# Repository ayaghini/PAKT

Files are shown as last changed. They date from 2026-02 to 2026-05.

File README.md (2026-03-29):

# PAKT

## Executive Summary
PAKT is an ESP32-S3-based APRS pocket TNC/tracker built around an SA818 VHF radio,
SGTL5000 audio codec, GPS, and BLE. The MVP now includes both the native PAKT BLE
protocol and KISS-over-BLE so existing APRS software can use the device as a BLE TNC.

The software foundation is substantially in place, and the current bench prototype
has now cleared the core codec and radio bring-up steps:
- firmware includes AX.25/APRS framing, AFSK modulator/demodulator, BLE GATT services,
  KISS-over-BLE, APRS TX scheduling, telemetry payloads, SGTL5000 audio pipeline bring-up,
  staged SA818 bench tests, and SA818 control paths
- the desktop test app and KISS bridge are implemented as reference host tools
- an in-repo iPhone-only SwiftUI app track now exists under `app/ios/`, built against the same native BLE protocol as the desktop client
- host-side software evidence is strong, with current docs recording `364/364` host tests passing
- bench bring-up has confirmed SGTL5000 discovery and headphone output, shared I2C
  visibility for the MAX17048 and M9N, SA818 UART handshake/config, staged PTT/audio tests,
  and short APRS packet TX receipt on a separate receiver

Recent bench work materially improved the RF picture:
- SA818 UART handshake/config recovered and is now responding again on hardware
- staged PTT test and 10-tone TX bench are confirmed working on the current prototype
- APRS packet TX is now bench-proven again on the current hardware state, with packets
  received externally during the restored full test flow
- RX analog/audio activity reaches the demodulator and now has stronger instrumentation
- RX debug now includes PSRAM-backed WAV export, selectable bench stages, selectable
  sample-path conditioning, and a `16 kHz` capture mode
- a separate quiet-capture firmware profile now supports repeated `30 s` low-noise
  captures with a countdown and framed binary export suitable for handoff analysis
- on-device APRS RX is now proven on hardware after fixing a half-rate I2S capture bug
  and reducing Stage C SA818 receive volume; the prototype now decodes APRS frames on-device
- the APRS message-ack path is now wired into `TxScheduler`, so on-air APRS acks
  can complete the firmware message FSM instead of always timing out
- the GPS path now prefers the shared Feather I2C/STEMMA bus (`u-blox M9N @ 0x42`)
  with `UART2` (`GPIO17/GPIO18`, `38400` baud) retained as a fallback; raw NMEA
  traffic is now logged/published even before a valid fix
- GPS over the shared Feather I2C/STEMMA bus is now working on the current
  prototype, including live telemetry delivery to the app; this path should now
  be treated as the default GPS integration baseline rather than an open bring-up item

The project is not MVP-complete yet because hardware validation still gates the milestone:
- BLE security and PTT fail-safe validation on hardware
- SA818 deviation and on-air receive/transmit calibration
- trusted Bell 202 source validation and on-device APRS RX proof
- third-party KISS client validation

## Project Status At A Glance

| Area | Status | Notes |
|---|---|---|
| Core firmware architecture | `strong` | AX.25/APRS, AFSK, BLE, KISS-over-BLE, scheduling, and host tooling are implemented |
| Bench bring-up | `in progress` | I2C, codec bring-up, SA818 UART/config, PTT, staged TX audio, and APRS TX bench are working |
| APRS TX over RF | `proven on current prototype` | tone sequence and APRS packets were heard/received again after SA818 recovery on 2026-03-21 |
| APRS RX over RF | `proven on current prototype` | quiet-profile RX now decodes APRS on-device after fixing the half-rate capture bug and reducing Stage C volume |
| BLE/KISS hardware validation | `pending` | software-complete enough for hardware validation |
| GPS over shared I2C | `proven on current prototype` | `u-blox M9N @ 0x42` is detected after startup, hot-switches to I2C/DDC, and publishes live telemetry to the app |
| MVP milestone | `open` | blocked by BLE safety validation, radio calibration/repeatability, and remaining hardware gates

## Progress Summary
- Software stack is largely implemented and test-backed.
- Prototype hardware can boot the codec/radio path, recover SA818 control, transmit APRS packets over RF, and now decode APRS on-device.
- Main firmware is now in production mode by default: recorder/export bench stages are disabled on boot while the continuous APRS RX path remains active.
- Demodulator instrumentation now exposes RX peak, flag, FCS-reject, and decode counters during bench work.
- Bench stages are now selectable through [bench_profile_config.h](/Users/macmini4/Desktop/PAKT/firmware/main/bench_profile_config.h), so debug sessions can run only the needed benches/stages instead of the full boot-time sequence.
- Full RX recorder/export now works through PSRAM-backed WAV capture, and the quiet profile can export captured demod-input audio through a framed binary serial stream for offline reconstruction.
- A real RX blocker was found and fixed: the audio pipeline was unpacking only half of each 2048-byte I2S read, effectively feeding the demodulator at `8 kHz` while configured for `16 kHz`.
- After fixing that bug and lowering quiet-profile Stage C SA818 volume from `8` to `4`, the device decoded multiple on-air APRS frames in the same `30 s` window.
- GPS parsing is no longer a stub: `gps_task` now reads the M9N over the shared I2C bus when present, falls back to UART if needed, and publishes BLE GPS telemetry even in the no-fix state.
- GPS over the shared Feather I2C/STEMMA bus is now confirmed working in the current hardware setup, and live GPS data is reaching the app.
- APRS ack handling is no longer a dead end: received APRS acks can now call `ctx.notify_ack()` and complete the message FSM in firmware.
- The RX path is now also configurable at the firmware level for:
  - `8 kHz` or `16 kHz` audio rate
  - left/right/average/stronger channel selection
  - stereo-slot swap
  - sample byte swap
  - firmware DC blocking
- The current best debugging workflow is the separate quiet-capture profile.
- The repo now distinguishes clearly between:
  - audio-path alive
  - packet TX proven
  - on-device APRS RX now proven on the corrected quiet profile

## Immediate Next Steps
1. Validate BLE encrypted+bonded write enforcement and PTT fail-safe behavior on live hardware.
2. Verify the newly wired APRS ack path end-to-end with real on-air message acknowledgements.
3. Validate native BLE + KISS-over-BLE behavior on hardware, including reconnect and at least one real client path.
4. Bring up the iPhone app against the same firmware build: connect, view APRS RX/GPS/status, send TX requests, change radio settings, and enable the BLE debug stream.
5. Keep the shared-I2C GPS path as the default baseline and only use UART fallback for alternate wiring or recovery.

## Bench Profile
- Bench/debug stage selection is controlled in [bench_profile_config.h](/Users/macmini4/Desktop/PAKT/firmware/main/bench_profile_config.h).
- Current toggles allow independent enable/disable of:
  - `audio_bench`
  - `sa818_bench`
  - `aprs_bench`
  - APRS Stage 0 loopback
  - APRS Stage A TX burst
  - APRS Stage B RX gain sweep
  - APRS PCM snapshot dump
  - APRS Stage C full RX recorder/export
- Stage C also has a selectable ADC gain step so targeted RX captures can be taken at the most useful receive setting.
- The same file now controls the audio debug sample rate and RX sample interpretation path.

## Current Status
- Phase: prototype hardware bring-up in progress, with packet TX, on-device APRS RX, and shared-I2C GPS telemetry now proven on the current prototype; remaining work is calibration, repeatability, app validation, and safety validation
- Firmware build flow: ESP-IDF with `idf.py`
- Host test flow: raw CMake only for `firmware/test_host`
- Canonical wire-format source: `docs/aprs_mvp_docs/payload_contracts.md`
- Canonical implementation/risk ledger: `docs/aprs_mvp_docs/agent_bootstrap/audit.md`

## Bench-Proven Baseline
- Feather target: Adafruit ESP32-S3 Feather `4 MB flash / 2 MB PSRAM`
- Shared I2C bus: `SGTL5000 @ 0x0A`, `MAX17048 @ 0x36`, `u-blox M9N @ 0x42`
- Audio bring-up rule: enable `SYS_MCLK` before SGTL5000 I2C init
- Verified audio wiring:
  - `GPIO3` `I2C_SDA`
  - `GPIO4` `I2C_SCL`
  - `GPIO8` `I2S_BCLK`
  - `GPIO15` `I2S_WS`
  - `GPIO12` `I2S_DOUT`
  - `GPIO10` `I2S_DIN`
  - `GPIO14` `I2S_MCLK`
- Verified radio control wiring:
  - `GPIO13` `SA818_RX_CTRL`
  - `GPIO9` `SA818_TX_STAT`
  - `GPIO11` `SA818_PTT`
- Restored and re-verified on 2026-03-21:
  - `AT+DMOCONNECT` handshake passes
  - `AT+DMOSETGROUP` frequency config passes
  - staged PTT test passes
  - 10-tone TX bench is audible on a receiver
  - APRS packet TX is received externally
- Bench modules now in the firmware tree:
  - `firmware/main/audio_bench_test/`
  - `firmware/main/sa818_bench_test/`

## Next Steps
- Measure TX deviation and formalize the corrected RX baseline in the bench docs
- Re-run APRS RX across multiple sessions to confirm repeatable decode margin on the corrected quiet profile
- If needed, tune SGTL5000 input/gain/sample interpretation using the new sample-path debug controls, but the core on-device RX proof now exists
- Measure and record SA818 TX deviation with the actual `LINE_OUT -> AF_IN` attenuation in place
- Validate BLE security enforcement and PTT watchdog behavior on the live hardware stack
- Freeze the harness values into the PCB-facing docs once AF levels, deviation, and PTT topology are measured

## Start Here
- `docs/README.md`
- `docs/aprs_mvp_docs/README.md`
- `docs/aprs_mvp_docs/agent_bootstrap/README.md`
- `docs/aprs_mvp_docs/agent_bootstrap/implementation_steps_mvp.md`
- `docs/aprs_mvp_docs/agent_bootstrap/gate_pass_matrix.md`
- `docs/aprs_mvp_docs/agent_bootstrap/audit.md`
- `docs/aprs_mvp_docs/docs/02_mvp_scope.md`
- `docs/aprs_mvp_docs/docs/05_ble_gatt_spec.md`
- `docs/aprs_mvp_docs/docs/19_ble_integration_reference.md`
- `docs/aprs_mvp_docs/docs/16_kiss_over_ble_spec.md`
- `docs/aprs_mvp_docs/payload_contracts.md`
- `docs/dev_setup.md`
- `docs/bench_bringup_checklist.md`
- `hardware/prototyping_wiring.md`
- `hardware/prototype_breakout_wiring_plan.md`

## Repository Layout
- `docs/`: unified documentation home
- `firmware/`: ESP-IDF firmware, host tests, and embedded integration code
- `app/desktop_test/`: desktop BLE reference client and KISS bridge/harness
- `docs/aprs_mvp_docs/docs/`: product, architecture, protocol, firmware, test, and risk docs
- `docs/aprs_mvp_docs/agent_bootstrap/`: low-token onboarding pack, implementation sequence, gates, and audit log
- `docs/aprs_mvp_docs/hardware/`: hardware interface notes and placeholder BOM
- `docs/hardware/`: hardware source library, CAD asset tracking, and reference links
- `docs/dev_setup.md` + `docs/bench_bringup_checklist.md`: operator/developer companion docs
- `hardware/`: practical prototyping wiring and hardware rationale
- `handoff/agent_integration_package/`: external-agent handoff package for host-software integration work

## Working Rules
- Use ESP-IDF `idf.py` for firmware builds; do not use raw CMake as the direct firmware entrypoint.
- Use raw CMake only for pure-software host tests under `firmware/test_host`.
- Keep `docs/aprs_mvp_docs/docs/05_ble_gatt_spec.md`,
- `docs/aprs_mvp_docs/docs/19_ble_integration_reference.md`,
- `docs/aprs_mvp_docs/agent_bootstrap/ble_protocol_quickref.md`,
  `docs/aprs_mvp_docs/docs/16_kiss_over_ble_spec.md`, and
  `docs/aprs_mvp_docs/payload_contracts.md` aligned with the implementation.
- If BLE UUIDs, payload fields, command semantics, chunking, or client behavior changes,
  update all relevant protocol docs in the same change so the desktop app, iPhone app,
  firmware, and future integrations do not drift.
- Prefer `firmware/main/main.cpp` and the component implementations as the source of truth for what is actually wired versus still hardware-gated.

## Build Directories
- `firmware/build_*` are the intended build output directories for the firmware project.
- Repo-root `build_feather_s3/` is also an ESP-IDF-generated build tree for the same `firmware/` project, not a second source tree.
- The metadata inside both `build_feather_s3/project_description.json` and `firmware/build_feather_s3/project_description.json` points back to `firmware/`; the difference is only the chosen build output path.

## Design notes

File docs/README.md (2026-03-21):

# Documentation Index

`docs/` is the single top-level documentation home for this repo.

## Project Snapshot
- Current phase: bench prototype verification
- Proven today:
  - codec/radio path boots and bench audio stages run
  - APRS packet TX has been received externally in a supervised setup
  - RX analog/audio path is active, instrumented, and can now be recorded to a PSRAM-backed WAV export
  - RX debug path is now bench-configurable at the firmware level, including channel selection and sample conditioning controls
  - a `16-bit / 16 kHz` RX capture path is now running on hardware
- Still open:
  - on-device APRS RX decode from a trusted Bell 202 source
  - SA818 TX deviation measurement
  - BLE safety/security hardware validation
  - final RX margin closure through the SGTL5000/I2S/sample path, where the latest suspicion is now concentrated

## Main Sections
- `aprs_mvp_docs/` — canonical product, protocol, architecture, QA, and status docs
- `dev_setup.md` — local toolchain, build, and test flow
- `bench_bringup_checklist.md` — bench execution order for the prototype
- `bench_measured_values_template.md` — measurement capture sheet
- `hardware/` — hardware reference library, source links, and CAD asset tracking
- `../firmware/main/bench_profile_config.h` — build-time bench stage selection for targeted debug sessions

## Recommended Entry Points
- Repo orientation: `aprs_mvp_docs/README.md`
- Current implementation status: `aprs_mvp_docs/agent_bootstrap/gate_pass_matrix.md`
- Rolling verification record: `aprs_mvp_docs/agent_bootstrap/audit.md`
- Bench work: `bench_bringup_checklist.md`
- Local setup: `dev_setup.md`

## Structure Notes
- `aprs_mvp_docs/` is the canonical spec and project-status tree.
- `hardware/` is the reference-library tree for components and assets.
- Repo-root `hardware/` is different: it contains practical wiring and prototype-planning notes rather than the source-library material.

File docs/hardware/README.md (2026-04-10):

# Hardware Reference Library

This folder holds the hardware references that feed schematic capture and PCB
layout. The active baseline now follows the confirmed bench stack rather than
earlier option-screening documents.

## Active hardware baseline
- MCU: `ESP32-S3-WROOM-1` (PCB antenna).
- Radio: `SA818S`.
- Audio codec: `SGTL5000XNLA3`.
- GPS layout baseline: u-blox `NEO-M8N/M8M` compatible footprint (`ublox_NEO`), with module choice finalized later.
- Fuel gauge: `MAX17048G+T10`.
- Charger: `MCP73831T-2ACI/OT`.
- GPS backup battery: `Panasonic BR-1225A/FAN` (non-rechargeable primary cell).

## Reference-design anchor
For battery charging and battery gauging, the custom PCB should follow the
bench-board power behavior of the Adafruit ESP32-S3 Feather baseline, because
that was used for bench validation and aligns with the `MAX17048` gauge path.

## Folder structure
- `components/README.md` - active vs archived component folders.
- `components/<part>/sources.md` - OEM datasheets, application notes, and reference-design links.
- `components/<part>/cad_assets.md` - symbol, footprint, package, and model mapping for KiCad.
- `components/<part>/symbols/` - local KiCad symbol libraries when needed.
- `components/<part>/footprints/` - local KiCad footprint files when needed.
- `components/<part>/step/` - STEP models if they are stored in-repo.

## Optional-components review flow
- Current plan: `hardware/PCB/rev01/reviews/HARDWARE_OPTIONAL_COMPONENT_PLAN.md`
- Completed reviews:
  - `hardware/PCB/rev01/reviews/GPS_OPTIONAL_COMPONENT_REVIEW.md`
  - `hardware/PCB/rev01/reviews/SA818_OPTIONAL_COMPONENT_REVIEW.md`

## Source policy
- Prefer OEM product pages, datasheets, and application notes.
- Keep breakout-board reference links separate from semiconductor OEM links.
- Mark legacy or mirror references clearly.

Current asset status is tracked in:
- `components/CAD_ASSET_STATUS.md`

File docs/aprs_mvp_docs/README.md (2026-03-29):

# APRS 2m Pocket TNC + Tracker (SA818 + ESP32-S3 + GPS) - MVP Docs

Last updated: 2026-03-28

This folder contains the working documentation set for a standalone APRS
(1200 baud AFSK, AX.25) 2m device that exposes BLE interfaces to desktop and phone clients,
including MVP KISS TNC interoperability over BLE for third-party APRS software.

Companion repo-root operator docs live alongside this folder:
- `../dev_setup.md` — local toolchain, build, and test flow
- `../bench_bringup_checklist.md` — prototype bring-up sequence
- `../bench_measured_values_template.md` — bench measurement capture sheet

## Goal (MVP)
A pocket device that:
- Transmits periodic APRS position beacons on 144.390 MHz (NA), configurable by region
- Receives and decodes APRS packets and forwards them to BLE clients
- Sends APRS messages from BLE clients to RF with basic retry/ack handling
- Exposes a KISS-over-BLE profile so existing APRS software can use the device as a TNC
- Uses GPS for position/time
- Provides BLE configuration and live status
- Runs from battery and charges over USB-C
- Supports a Windows desktop BLE test app workflow before phone app rollout
- Supports an iPhone-only SwiftUI companion app using the same native BLE protocol as the desktop app

## Contents
- `docs/01_product_brief.md`
- `docs/02_mvp_scope.md`
- `docs/03_system_architecture.md`
- `docs/04_hardware_block_diagram.md` (+ `assets/hardware_block_diagram.png`)
- `docs/05_ble_gatt_spec.md`
- `docs/06_firmware_architecture.md`
- `docs/07_audio_i2s_codec_notes.md`
- `docs/08_test_plan.md`
- `docs/09_risks_and_mitigations.md`
- `docs/10_open_questions.md`
- `docs/11_hf_ble_feasibility_study.md`
- `docs/12_implementation_backlog.md`
- `docs/15_interoperability_matrix.md`
- `docs/16_kiss_over_ble_spec.md`
- `docs/17_mvp_gap_analysis.md`
- `docs/19_ble_integration_reference.md`
- `hardware/placeholder_bom.csv`
- `hardware/interfaces.md`
- `agent_bootstrap/README.md` (low-token onboarding pack for AI agents)

## Agent-first entrypoint
Start with:
1. `agent_bootstrap/README.md`
2. `agent_bootstrap/implementation_steps_mvp.md`
3. Remaining files in the strict bootstrap load order

The bootstrap pack includes:
- execution workflow
- implementation step sequence with required evidence
- QA gate criteria and failure handling
- step-to-source mapping for minimal-context document loading
- connected-device upload/debug/verify loop (`agent_bootstrap/device_loop.md`)
- rolling implementation log (`agent_bootstrap/audit.md`)
- gate status summary (`agent_bootstrap/gate_pass_matrix.md`)

## Current implementation snapshot
- Software: most MVP software paths are implemented, including native BLE, KISS-over-BLE, AX.25/APRS framing, AFSK modem, APRS TX scheduling, telemetry payloads, desktop BLE tooling, and KISS bridge support.
- Contracts: `payload_contracts.md` is the canonical JSON schema source for BLE payloads.
- Hardware: bench bring-up and RF/electrical validation remain the main gating steps.
- RF status: APRS packet TX is bench-proven on the current prototype, and on-device APRS RX is now also proven on hardware after fixing the half-rate I2S capture bug in the RX path.
- RX diagnosis status: the earlier SGTL5000 / I2S / sample-capture investigation led to a real firmware fix. The current receive-side focus is no longer first-principles RX proof, but repeatability, margin, calibration, and integration into the main firmware path.
- Bench workflow status: blocking bench stages are now selectable through `firmware/main/bench_profile_config.h`, so prototype debug runs can be narrowed to only the needed stages.
- Interop: KISS-over-BLE is part of MVP and is software-complete enough for hardware validation; third-party client evidence is still pending.
- APRS message ack handling is now wired into the firmware TX state machine; end-to-end on-air ack validation is still pending.
- GPS integration now prefers the shared Feather I2C/STEMMA bus (`u-blox M9N @ 0x42`) with `UART2` (`GPIO17/GPIO18`, `38400` baud) as a fallback; the shared-I2C GPS path is now working on the current prototype and live GPS telemetry is reaching the app.

## Documentation split
- `docs/aprs_mvp_docs/` is the canonical spec, architecture, protocol, and project-status tree.
- The sibling files under repo-root `docs/` are the practical operator/developer companion docs for setup and bench execution.
- If implementation-status wording disagrees, prefer `agent_bootstrap/gate_pass_matrix.md`, `agent_bootstrap/audit.md`, and `firmware/main/main.cpp`.
- BLE/protocol change-control set:
  - `docs/05_ble_gatt_spec.md`
  - `docs/19_ble_integration_reference.md`
  - `payload_contracts.md`
  - `docs/16_kiss_over_ble_spec.md`
  - `agent_bootstrap/ble_protocol_quickref.md`
- If BLE UUIDs, payloads, chunking, command semantics, or client-facing protocol behavior changes, update the relevant files in this set together.

## Current hardware baseline
- Audio codec: `SGTL5000` (with explicit `I2S_MCLK`)
- RF module: `SA818`
- Battery charger: `MCP73831/2` class
- Battery fuel gauge: `MAX17048`

## Recommended reading by role
- New coding agent: start with `agent_bootstrap/README.md`
- Firmware bring-up: read `docs/06_firmware_architecture.md`, `docs/07_audio_i2s_codec_notes.md`, `agent_bootstrap/audit.md`, and `../bench_bringup_checklist.md`
- Host/app integration: read `docs/05_ble_gatt_spec.md`, `docs/16_kiss_over_ble_spec.md`, `payload_contracts.md`, and the desktop app sources under `app/desktop_test/`
- Cross-platform BLE integration: start with `docs/19_ble_integration_reference.md`, then `docs/05_ble_gatt_spec.md`, `payload_contracts.md`, and `docs/16_kiss_over_ble_spec.md`
- iPhone app implementation: start with `docs/18_ios_app_architecture.md`, then `docs/05_ble_gatt_spec.md`, `payload_contracts.md`, and the desktop app sources under `app/desktop_test/`

## Current status at a glance
- MVP gate: open
- Strongest validated RF result so far: APRS TX is proven externally and APRS RX is now proven on-device on the current prototype
- GPS status: shared-I2C GPS transport and BLE/app telemetry are now working on the current prototype
- Most important remaining RF work: repeatability, deviation calibration, and end-to-end validation on the corrected firmware baseline
- Main next verification step: continue MVP hardware validation above the now-working RF + GPS stack, and deliver the first iPhone operator app against the same BLE protocol surface

## What this is / is not
- A practical starting point for hardware + firmware implementation
- Enough structure to onboard agents and execute implementation safely
- Not a complete electrical schematic or PCB layout yet

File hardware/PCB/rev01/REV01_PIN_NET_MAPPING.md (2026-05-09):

# PAKT Rev01 Pin/Net Mapping (As-Built Schematic Snapshot)

This mapping is synced to `hardware/PCB/rev01/rev01.kicad_sch` as currently wired.
Use this file as the source of truth for routing and firmware pin assignment checks.

## 1) MCU Control/Data Mapping

| Function | ESP32-S3-WROOM-1 pin | Net Name | Remote pin(s) | Notes |
|---|---|---|---|---|
| I2C SDA | IO3 | `I2C_SDA` | U3 `CTRL_DATA`, U4 `SDA`, U1 `SDA/~SPI_CS` | Shared I2C bus |
| I2C SCL | IO4 | `I2C_SCL` | U3 `CTRL_CLK`, U4 `SCL`, U1 `SCL/SPI_CLK` | Shared I2C bus |
| I2S BCLK | IO8 | `I2S_BCLK` | U3 `I2S_SCLK` | Audio clock |
| I2S LRCLK/WS | IO15 | `I2S_LRCLK` | U3 `I2S_LRCLK` | Word select |
| I2S DOUT | IO12 | `I2S_DOUT` | U3 `I2S_DOUT` | ESP -> codec |
| I2S DIN | IO10 | `I2S_DIN` | U3 `I2S_DIN` | Codec -> ESP |
| I2S MCLK | IO14 | `I2S_MCLK` | U3 `SYS_MCLK` | Must run before codec init |
| GPS RX path | IO18 | `GPS_RXD` | U1 `TXD/SPI_MISO` | ESP RX <- GPS TX |
| GPS TX path | IO17 | `GPS_TXD` | U1 `RXD/SPI_MOSI` | ESP TX -> GPS RX |
| SA818 RX path | IO9 | `SA818_RXD` | U5 `TXD` | ESP RX <- SA818 TX |
| SA818 TX path | IO13 | `SA818_TXD` | U5 `RXD` | ESP TX -> SA818 RX |
| SA818 PTT | IO11 | `SA818_PTT_N` | U5 `PTT` | Active low |
| USB FS D+ (MCU side) | USB_D+ pin | `USB_D_P` | U8 pin 6 | After ESD device |
| USB FS D- (MCU side) | USB_D- pin | `USB_D_N` | U8 pin 4 | After ESD device |

## 2) USB Data/ESD Chain

| Segment | Net | Nodes |
|---|---|---|
| Connector side D+ | `DD+` | J4 A6/B6, U8 pin 1 |
| Connector side D- | `DD-` | J4 A7/B7, U8 pin 3 |
| MCU side D+ | `USB_D_P` | U8 pin 6, U2 USB_D+ |
| MCU side D- | `USB_D_N` | U8 pin 4, U2 USB_D- |
| ESD supply | `+5V` | U8 pin 5, C22 |

## 3) Power Nets (Current Schematic)

| Net | Source path | Main consumers |
|---|---|---|
| `VBUS` | USB-C VBUS pins | U6 input cap path, Q4 gate control, D6 anode |
| `+5V` | Local USB/ESD rail | U8 (`USBLC6-2P6`), C22 |
| `VBAT` | 18650 battery node (BT2) | U4 `CELL/VDD`, FB16 input, Q4 drain |
| `+5V_SA818` | SA818 pre-supply rail | FB16 output, D15 anode, C33, R7/R8 pull-up source |
| `Net-(D15-K)` | SA818 supply rail after D15 | U5 `VBAT`, C8/C9/C10 |
| `Net-(D6-K)` | Main regulator-input rail | U7 `VIN`, C23, R21, Q4 source |
| `+3.3V` | U7 output | ESP32, SGTL5000 rails, GPS VCC, I2C pull-ups, support caps |
| `VBCKP` | GPS backup rail | BT1+, U1 `V_BCKP`, D2 cathode |
| `GPS_BCKP_CHG` | Backup charge feed | R17 output, D2 anode |

### MAX17048 (U4) pin map (updated symbol)

| U4 pin | Pin name | Intended net/function |
|---|---|---|
| 1 | `CTG` | Leave NC unless using external thermistor path |
| 2 | `CELL` | `VBAT` battery sense |
| 3 | `VDD` | `VBAT` supply |
| 4 | `GND` | `GND` |
| 5 | `*ALRT` | Alert output (`MAX17048_ALRT_N` if labeled) |
| 6 | `QSTRT` | Quick-start control (`MAX17048_QSTRT`) |
| 7 | `SCL` | `I2C_SCL` |
| 8 | `SDA` | `I2C_SDA` |
| 9 | `EPAD` | Tie to `GND` |

## 4) RF/Analog Paths

### SA818 TX/RF path

| Net | From | To |
|---|---|---|
| `SA818_MIC_IN_PATH` | U3 line outputs via C17 | U5 `MIC_IN` |
| `AF_RADIO_OUT` | U5 `AF_OUT` | U3 line inputs via C16 |
| `SA818_ANT` | U5 `ANT` | U9 `IN` |
| `Net-(U9-OUT)` | U9 `OUT` | J2 center pin |

### SGTL5000 bench-reference filtering additions (As currently placed, no AP7313)

Use this as the recommended add-on set for SGTL5000 supply stability and cleaner analog behavior.

| Ref | Value | Connect pin 1 to | Connect pin 2 to | Purpose |
|---|---|---|---|---|
| `C3` | `2.2u_SGTL_PRE` | `+3.3V` | `GND` | Pre-bead bulk decoupling |
| `C4` | `2.2uf` | `+3.3V` | `GND` | Additional pre-bead bulk decoupling (as currently valued) |
| `FB2` | `Murata BLM18PG121SN1D` | `+3.3V` | SGTL filtered rail feeding `VDDA` | Analog-domain HF isolation (same family as SA818 FB16) |
| `C6` | `2.2u_SGTL_POST` | SGTL filtered rail (FB2 output) | `GND` | Post-bead bulk decoupling |
| `C5` | `2.2uf` | SGTL filtered rail (FB2 output) | `GND` | Additional post-bead bulk decoupling (as currently valued) |
| `C15` | `100n_SGTL_VAG` | `U3 VAG` | `GND` | Local VAG HF bypass (place close to U3 pin 5) |

Recommended SGTL rail usage with the above:
- `U3 VDDA` -> SGTL filtered rail from `FB2` output
- `U3 VDDD` and `U3 VDDIO` -> `+3.3V` (or filtered rail if you intentionally choose single-rail codec power)
- Keep `C11/C12/C13/C14` local to U3 pins as currently done.

### GPS rail filtering additions (same ferrite family)

| Ref | Value | Connect pin 1 to | Connect pin 2 to | Purpose |
|---|---|---|---|---|
| `FB1` | `Murata BLM18PG121SN1D` | `+3.3V` | GPS filtered rail feeding `U1 VCC` | Isolate GPS rail noise |
| `C1` | `10u_GPS_RAIL` | GPS filtered rail (FB1 output) | `GND` | GPS local bulk decoupling |
| `C2` | `100n_GPS_RAIL` | GPS filtered rail (FB1 output) | `GND` | GPS local HF bypass |

Audio coupling note from bench reference:
- Teensy Audio Adapter commonly uses `2.2uF` AC-coupling on line paths.
- If you want to match that behavior, change `C16` and `C17` from `1u` to `2.2u`.

Scope note:
- microSD-related parts in the bench reference are intentionally excluded.

### GPS RF path

| Net | From | To | Notes |
|---|---|---|---|
| `GPS_RF_IN` | J5 center pin | U1 `RF_IN` through L3 | GPS antenna input path |
| `Net-(C26-Pad1)` | L3 output | C26, R23 | Matching/bias node |
| `VCCREF` | U1 `VCC_RF` | R23 | RF bias feed |

### GPS timepulse indicator

| Net | From | To |
|---|---|---|
| `GPS_TIMEPULSE` | U1 `TIMEPULSE` | R24 |
| `Net-(D4-A)` | R24 | D4 anode (LED cathode to GND) |

## 5) Key Support Components Present

- GPS: `BT1`, `D2`, `R17`, `J5`, `L3`, `R23`, `C26`, `R24`, `D4`
- SA818 RF/power: `U9`, `J2`, `FB16`, `D15`, `C33`, `C8/C9/C10`
- SGTL filter additions: `FB2`, `C3/C4/C5/C6`, `C15`
- GPS rail filter additions: `FB1`, `C1/C2`
- USB protection: `U8` (`USBLC6-2P6`)
- Charger/fuel gauge core: `U6`, `U4`, `C18/C19/C20`, `R5`, `R10`, `R11`, `R12`
- ESP boot/reset: `SW1`, `SW2`, `R13`, `R14`, `C21`

## 6) Net Label Checklist (Current)

`I2C_SDA`, `I2C_SCL`, `I2S_BCLK`, `I2S_LRCLK`, `I2S_DOUT`, `I2S_DIN`, `I2S_MCLK`, `GPS_RXD`, `GPS_TXD`, `GPS_TIMEPULSE`, `SA818_RXD`, `SA818_TXD`, `SA818_PTT_N`, `SA818_MIC_IN_PATH`, `AF_RADIO_OUT`, `SA818_ANT`, `GPS_RF_IN`, `VCCREF`, `DD+`, `DD-`, `USB_D_P`, `USB_D_N`, `VBUS`, `+5V`, `VBAT`, `+5V_SA818`, `Net-(D15-K)`, `Net-(D6-K)`, `+3.3V`, `VBCKP`, `GPS_BCKP_CHG`, `GND`.

## 7) Notes

- Charger nets are currently auto-named in schematic as `Net-(U6-PROG)` and `Net-(U6-STAT)`.
- ESP EN/BOOT nets are currently auto-named in schematic as `Net-(U2-EN)` and `Net-(U2-IO0)`.
- Keep `R17`/`D2` backup-charge path DNP unless backup chemistry supports recharge.

## 8) Net Standardization Map

Use this map to replace remaining KiCad auto-nets (`Net-(...)`) with explicit names.

| Current Auto Net | Standard Name |
|---|---|
| `Net-(C26-Pad1)` | `GPS_RF_MATCH` |
| `Net-(D1-K)` | `CHG_LED_N` |
| `Net-(D4-A)` | `GPS_TIMEPULSE_LED` |
| `Net-(D5-A)` | `USB_TVS_A` |
| `Net-(D5-K)` | `USB_TVS_K` |
| `Net-(D6-K)` | `VSYS_MAIN` |
| `Net-(D15-K)` | `SA818_VBAT` |
| `Net-(J4-CC1)` | `USB_CC1` |
| `Net-(J4-CC2)` | `USB_CC2` |
| `Net-(U2-EN)` | `ESP_EN` |
| `Net-(U2-IO0)` | `ESP_IO0` |
| `Net-(U4-QSTRT)` | `MAX17048_QSTRT` |
| `Net-(U4-*ALRT)` | `MAX17048_ALRT_N` |
| `Net-(U5-H{slash}L)` | `SA818_HL` |
| `Net-(U5-PD)` | `SA818_PD` |
| `Net-(U6-PROG)` | `MCP73831_PROG` |
| `Net-(U6-STAT)` | `CHG_STAT_N` |
| `Net-(U6-VBAT)` | `MCP73831_VBAT` |
| `Net-(U7-EN)` | `REG_EN` |
| `Net-(U9-OUT)` | `SA818_RF_OUT` |
## 9) Waveshare 3.97in e-Paper HAT+ (40-pin) Integration

Source: Waveshare 3.97in e-Paper HAT+ manual and schematic.

### Recommended ESP32 net assignment (conflict-free with current Rev01)

| e-Paper signal | HAT 40-pin physical pin | ESP32-S3 GPIO | New net name |
|---|---:|---:|---|
| `DIN` | 19 | IO21 | `EPD_DIN` |
| `SCLK` | 23 | IO16 | `EPD_SCLK` |
| `CS` | 24 | IO5 | `EPD_CS` |
| `DC` | 22 | IO6 | `EPD_DC` |
| `RST` | 11 | IO7 | `EPD_RST` |
| `BUSY` | 18 | IO38 | `EPD_BUSY` |
| `PWR` | 12 | IO39 | `EPD_PWR_EN` |
| `3V3` | 1 and/or 17 | 3V3 rail | `+3.3V` |
| `5V` (optional) | 2 and/or 4 | 5V rail | `+5V` |
| `GND` | 6/9/14/20/25/30/34/39 | GND | `GND` |

Notes:
- Above keeps your existing UART/I2C/I2S/SA818 assignments untouched.
- Display board supports 3.3V or 5V supply input; for ESP32-native IO use 3.3V domain.
- Waveshare reference ESP32 mapping is `DIN=IO14`, `CLK=IO13`, `CS=IO15`, `DC=IO27`, `RST=IO26`, `BUSY=IO25`, `PWR=IO33`; reassignment above is intentional to avoid Rev01 pin conflicts.
- `IO14` is already used by `I2S_MCLK` in Rev01 and should not be reused for e-paper.
- For ESP32-S3-WROOM-1 variants with embedded Octal PSRAM (R8 variants), `IO35/IO36/IO37` are not available for user GPIO; mapping above avoids those pins.

### 40-pin socket to place in schematic/PCB

- Symbol: `Connector_Generic:Conn_02x20_Odd_Even`
- Footprint (THT): `Connector_PinSocket_2.54mm:PinSocket_2x20_P2.54mm_Vertical`
- Footprint (stackable/holder style): `Connector_PinSocket_2.54mm:PinSocket_2x20_P2.54mm_Vertical_SMD` (if you need solder-side clearance) or long-tail stackable equivalent from vendor.

Suggested accessible MPN options:
- Through-hole female socket: `Sullins PPTC202LFBN-RC` (2x20, 2.54mm)
- Stackable long-tail female header: `Adafruit 2223` equivalent style (choose vendor-specific 2x20 stackable, 2.54mm, >=8.5mm body).

### Mechanical constraints from vendor docs

Confirmed:
- HAT+ board size: `99.50 mm x 60.00 mm`
- Header pitch: `2.54 mm`, 2x20

Mounting holes:
- Waveshare public manual/schematic do not publish explicit hole XY coordinates for this specific HAT+ board.
- Use these PCB constraints for placement unless you re-measure from the physical board or vendor CAD:
  - Hole drill: `3.2 mm` (M3 clearance)
  - Keepout ring: `>= 6.0 mm` OD recommended
  - If you intend to co-mount with Raspberry Pi pattern hardware, use M2.5 hardware and verify fit against the actual HAT board before fab.

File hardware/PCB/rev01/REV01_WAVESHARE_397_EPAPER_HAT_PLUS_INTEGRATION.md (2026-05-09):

# REV01 Waveshare 3.97inch e-Paper HAT+ Integration

## Sources
- Product: https://www.waveshare.com/3.97inch-e-paper-hat-plus.htm?sku=31063
- Manual: https://www.waveshare.com/wiki/3.97inch_e-Paper_HAT%2B_Manual
- Schematic PDF: https://files.waveshare.com/wiki/3.97inch_e-Paper_HAT%2B_G/3.97inch_e-Paper_HAT%2B.pdf

## Required wiring (HAT 40-pin to ESP32)

| HAT physical pin | HAT net/signal | Connect to Rev01 |
|---:|---|---|
| 1 | 3V3 | `+3.3V` |
| 2 | 5V | `+5V` (optional; do not use if running full 3.3V domain only) |
| 6 | GND | `GND` |
| 11 | RST | `EPD_RST` -> ESP32 IO36 |
| 12 | PWR | `EPD_PWR_EN` -> ESP32 IO38 |
| 18 | BUSY | `EPD_BUSY` -> ESP32 IO37 |
| 19 | DIN (MOSI) | `EPD_DIN` -> ESP32 IO14 |
| 22 | DC | `EPD_DC` -> ESP32 IO35 |
| 23 | SCLK | `EPD_SCLK` -> ESP32 IO16 |
| 24 | CS (CE0) | `EPD_CS` -> ESP32 IO21 |
| 25 | GND | `GND` |

Recommended extra grounds for return-path quality: also tie any of 9/14/20/30/34/39 to GND plane.

## Suggested schematic symbol + footprint

- Symbol: `Connector_Generic:Conn_02x20_Odd_Even`
- Footprint: `Connector_PinSocket_2.54mm:PinSocket_2x20_P2.54mm_Vertical`

### Suggested purchasable connector MPNs
- `Sullins PPTC202LFBN-RC` (2x20 female, THT, 2.54mm)
- Any equivalent 2x20 stackable female header, 2.54mm pitch, long-tail style if you need passthrough/holder behavior.

### Buy links
- Sullins `PPTC202LFBN-RC` (Digi-Key): https://www.digikey.com/en/products/detail/sullins-connector-solutions/PPTC202LFBN-RC/810164
- Waveshare display product page: https://www.waveshare.com/3.97inch-e-paper-hat-plus.htm?sku=31063

## Mechanical dimensions for PCB placement

Confirmed from Waveshare manual:
- Driver board size: `99.50 mm x 60.00 mm`
- Display size: `86.40 mm x 51.84 mm`

Mounting-hole data status:
- The provided manual/schematic do not include explicit hole XY coordinates for this HAT+ board.
- If you need exact hole placement for direct screw alignment, measure from a physical board or request vendor CAD/GERBER.
- Conservative default for placeholder footprints:
  - Hole drill: `3.2 mm` (M3 clearance)
  - Courtyard/keepout diameter: `6.0 mm` minimum

## Firmware pin defines (Rev01 proposal)

```c
#define EPD_DIN_PIN   14
#define EPD_SCLK_PIN  16
#define EPD_CS_PIN    21
#define EPD_DC_PIN    35
#define EPD_RST_PIN   36
#define EPD_BUSY_PIN  37
#define EPD_PWR_PIN   38
```

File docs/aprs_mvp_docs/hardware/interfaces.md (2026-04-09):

# Hardware interfaces (schematic handoff)

## External interfaces
- USB-C: charging and optional native USB/debug.
- Antenna: SMA or equivalent `50 ohm` path from SA818 RF output.
- Single-cell Li-ion battery connector.
- Buttons:
  - Reset / boot on the MCU support side
  - Function button on the product side if retained
- Indicators:
  - Charging status
  - BLE / status
  - TX and RX status

## Internal electrical interfaces
- ESP32-S3 UART <-> SA818 UART (`3.3V` TTL)
- ESP32-S3 GPIO -> SA818 PTT
- ESP32-S3 I2S <-> SGTL5000 codec
- ESP32-S3 MCLK output -> SGTL5000 `SYS_MCLK`
- SGTL5000 analog out -> SA818 `AF_IN` (AC-coupled)
- SA818 `AF_OUT` -> SGTL5000 analog in (AC-coupled)
- ESP32-S3 shared I2C <-> SGTL5000
- ESP32-S3 shared I2C <-> MAX17048
- ESP32-S3 shared I2C <-> GPS (default path)
- ESP32-S3 UART <-> GPS NMEA (fallback path)
- Optional GPS PPS -> ESP32 interrupt-capable GPIO
- MCP73831 `STAT` output -> charge LED and optional observation node

## Battery-section reference rule
- The charger and fuel-gauge topology should follow the Adafruit ESP32-S3 Feather with `4MB Flash / 2MB PSRAM`, because that is the confirmed bench board and Adafruit identifies `MAX17048` on that variant.

## Required named nets
- Power: `VBUS`, `VBAT_RAW`, `V_RADIO`, `V_SYS_3V3`, `V_AUD_3V3`, `GND`
- Radio control: `SA818_PTT`, `SA818_RX_CTRL`, `SA818_TX_STAT`
- Audio: `AF_TX_COUPLED`, `AF_RX_COUPLED`
- GPS: `GPS_TX_NMEA`, `GPS_RX_CTRL`, optional `GPS_PPS`
- Shared buses: `I2C_SDA`, `I2C_SCL`, `I2S_BCLK`, `I2S_WS`, `I2S_DOUT`, `I2S_DIN`, `I2S_MCLK`

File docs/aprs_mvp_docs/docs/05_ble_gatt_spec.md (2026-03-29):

# BLE GATT Specification

This document defines the Bluetooth Low Energy Generic Attribute Profile (GATT)
for the APRS Pocket TNC.

Client note:
- MVP development started with the desktop BLE test app.
- The repo now also carries an iPhone-only SwiftUI app track under `app/ios/`.
- Protocol compatibility between desktop and iPhone clients is a requirement: new app-facing features should extend the existing contract rather than fork it.

## Services Overview

The device exposes:

1. **Device Information Service (Standard):** `0x180A`
2. **APRS Service (Custom):** configuration, commands, messaging, and status
3. **Device Telemetry Service (Custom):** runtime telemetry channels
4. **KISS Service (Custom):** raw KISS TNC frame transport for third-party APRS software

## Project Base UUID

All custom services and characteristics use the shared 128-bit base UUID.

- **Base UUID template:** `544E4332-8A48-4328-9844-3F5C00000000`
- **Rule:** insert the 16-bit value into bytes 12-13 of the UUID (the `0000` before the last group)
- **Example:** `0xA001` -> `544E4332-8A48-4328-9844-3F5CA0010000`

All UUID strings below are shown fully expanded.

---

## 1. Device Information Service

Standard BLE service.

| Characteristic | UUID (16-bit) | Properties | Value (example) |
| --- | --- | --- | --- |
| Manufacturer Name | `0x2A29` | Read | "PAKT" |
| Model Number | `0x2A24` | Read | "APRS-TNC-1" |
| Firmware Revision | `0x2A26` | Read | "0.1.0" |
| Software Revision | `0x2A28` | Read | "0.1.0" (desktop app)  |

---

## 2. APRS Service

**Service UUID:** `544E4332-8A48-4328-9844-3F5CA0000000`

| Characteristic | UUID (16-bit) | Full UUID | Properties | Max App Payload | Data Format  | Notes / canonical payload |
| --- | --- | --- | --- | --- | --- | --- |
| **Device Config** | `0xA001` | `544E4332-8A48-4328-9844-3F5CA0010000` | Read, Write | 256 B | UTF-8 JSON | `{"callsign":"W1AW","ssid":9}` |
| **Device Command** | `0xA002` | `544E4332-8A48-4328-9844-3F5CA0020000` | Write Without Response | 64 B | UTF-8 JSON | `{"cmd":"beacon_now"}` or `{"cmd":"radio_set","freq_hz":144390000}` |
| **Device Status** | `0xA003` | `544E4332-8A48-4328-9844-3F5CA0030000` | Notify | 128 B | UTF-8 JSON | `{"radio":"idle","bonded":true,"gps_fix":true,"pending_tx":0,"rx_queue":0,"uptime_s":3600}` |
| **Device Capabilities** | `0xA004` | `544E4332-8A48-4328-9844-3F5CA0040000` | Read | 160 B | UTF-8 JSON | `{"fw_ver":"0.1.0","hw_rev":"EVT-A","protocol":1,"features":["aprs_2m","ble_chunking","telemetry","msg_ack","config_rw","gps_onboard","kiss_ble"]}` |
| **RX Packet Stream**  | `0xA010` | `544E4332-8A48-4328-9844-3F5CA0100000` | Notify | 256 B | UTF-8 String | APRS packet in TNC2 monitor format |
| **TX Request** | `0xA011` | `544E4332-8A48-4328-9844-3F5CA0110000` | Write | 256 B | UTF-8 JSON | `{"dest":"APRS","text":"Hello World","ssid":0}` |
| **TX Result** | `0xA012` | `544E4332-8A48-4328-9844-3F5CA0120000` | Notify | 64 B | UTF-8 JSON | `{"msg_id":"42","status":"tx|acked|timeout|cancelled|error"}` |

---

## 3. Device Telemetry Service

**Service UUID:** `544E4332-8A48-4328-9844-3F5CA0200000`

| Characteristic | UUID (16-bit) | Full UUID | Properties | Max App Payload | Data Format | Notes / canonical payload |
| --- | --- | --- | --- | --- | --- | --- |
| **GPS Telemetry** | `0xA021` | `544E4332-8A48-4328-9844-3F5CA0210000` | Notify | 128 B | UTF-8 JSON  | `{"lat":49.035,"lon":-123.100,"alt_m":150.0,"speed_kmh":12.5,"course":90.0,"sats":8,"fix":1,"ts":764426119}` |
| **Power Telemetry**  | `0xA022` | `544E4332-8A48-4328-9844-3F5CA0220000` | Notify | 96 B | UTF-8 JSON  | `{"batt_v":3.95,"batt_pct":88,"tx_dbm":30.0,"vswr":1.2,"temp_c":34.5}` |
| **System Telemetry** | `0xA023` | `544E4332-8A48-4328-9844-3F5CA0230000` | Notify | 96 B | UTF-8 JSON  | `{"free_heap":120000,"min_heap":95000,"cpu_pct":22,"tx_pkts":5,"rx_pkts":3,"tx_errs":0,"rx_errs":0,"uptime_s":1800}` |
| **Debug Stream** | `0xA024` | `544E4332-8A48-4328-9844-3F5CA0240000` | Notify | 180 B logical | UTF-8 text  | Runtime debug lines, emitted only when enabled by `Device Command` |

Debug stream rules:

- Disabled by default.
- Enabled and disabled using `{"cmd":"debug_stream","enabled":true|false}` on `Device Command`.
- Intended for operator-facing runtime diagnostics in the desktop and iPhone apps.
- Firmware should emit scoped, human-readable lines only for selected categories; it must not blindly mirror all ESP logs onto BLE.

---

## 4. KISS Service

**Service UUID:** `544E4332-8A48-4328-9844-3F5CA0500000`

| Characteristic | UUID (16-bit) | Full UUID | Properties | Max App Payload | Data Format | Notes |
| --- | --- | --- | --- | --- | --- | ----- |
| **KISS RX** | `0xA051` | `544E4332-8A48-4328-9844-3F5CA0510000` | Notify | 330 B logical | Binary KISS | Device -> client, chunked when needed |
| **KISS TX** | `0xA052` | `544E4332-8A48-4328-9844-3F5CA0520000` | Write With Response  | 330 B logical | Binary KISS | Client -> device, encrypted + bonded |

KISS MVP rules:

- Port 0 only.
- Data frame type `0x00` required for actual AX.25 transfer.
- `0x0F` return-from-KISS may be accepted and echoed for compatibility, but the device is not modal; native PAKT BLE and KISS service may coexist.
- Extended KISS port/parameter commands (`0x01`-`0x06`) are out of scope for MVP and may be ignored safely.
- MVP maximum logical KISS frame size is 330 bytes after reassembly; oversize frames must be dropped and counted as TX/RX errors.

## Canonical Schema Source

For JSON field-level contracts, use:
- `docs/aprs_mvp_docs/payload_contracts.md`

If this file and payload contracts diverge, payload contracts are authoritative.

For KISS binary framing and service behavior, use:
- `docs/aprs_mvp_docs/docs/16_kiss_over_ble_spec.md`

---

## Security Notes

- Pairing alone is not sufficient for write-capable control endpoints.
- Require LE Secure Connections with bonding for production firmware.
- Restrict write access (`Device Config`, `Device Command`, `TX Request`, `KISS TX`) to encrypted + bonded links.
- Require a physical user action (pair button or boot-time pairing window) before accepting new bonds.
- Enforce an application-level allowlist for privileged commands (for example `radio_set`).

## Device Command notes

The `Device Command` characteristic remains the single command channel for one-shot actions and radio/debug control.

Current command families:

1. `{"cmd":"beacon_now"}`
- immediate APRS position beacon attempt using current config and latest GPS snapshot

2. `{"cmd":"debug_stream","enabled":true|false}`
- toggles the dedicated debug notify stream on `0xA024`

3. `{"cmd":"radio_set", ...}`
- supported fields are optional and may be combined in one write:
  - `freq_hz`
  - `rx_freq_hz`
  - `tx_freq_hz`
  - `squelch`
  - `volume`
  - `wide_band`
- unsupported or malformed payloads are rejected

## Device Status notes

`Device Status` is now a live dashboard-oriented notify, not a reserved placeholder.

Current status payload includes at least:
- `radio`
- `bonded`
- `encrypted`
- `gps_fix`
- `pending_tx`
- `rx_queue`
- `rx_freq_hz`
- `tx_freq_hz`
- `squelch`
- `volume`
- `wide_band`
- `debug_enabled`
- `uptime_s`

## Transport and MTU Notes

- Values in "Max App Payload" are logical payload sizes, not guaranteed single-PDU BLE payloads.
- Implement explicit chunking for any payload that can exceed `(negotiated_mtu - 3)` bytes.
- Required protocol fields for chunked payloads:
  - `msg_id`: unique id for a logical message.
  - `chunk_idx`: zero-based chunk index.
  - `chunk_total`: number of chunks.
- RX and TX endpoints must support reassembly timeout and duplicate-chunk handling.
- Clients should request a higher MTU, but firmware must still work at default MTU.
- KISS RX and KISS TX use the same chunk header and timeout rules as the native JSON endpoints.

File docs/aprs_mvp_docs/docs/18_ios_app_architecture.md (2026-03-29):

# iPhone App Architecture

Date: 2026-03-28
Status: initial in-repo scaffold landed; simulator build verified

## Purpose

Define the first iPhone-only operator app for PAKT while keeping protocol compatibility with the existing desktop BLE app.

The app is an MVP operator tool, not a consumer-polished product.

## Goals

- connect and disconnect to a PAKT device over BLE
- show live APRS packets from the native `rx_packet` stream
- show live GPS, system, and device status
- send APRS transmit requests using the existing `tx_request` contract
- send advanced raw commands over `device_command`
- control SA818 settings through the same command channel
- show a session-only debug console backed by the dedicated BLE debug stream

## Compatibility rule

The iPhone app must reuse the same BLE protocol and payload contracts as the desktop app wherever possible.

That means:
- same UUID map
- same JSON payloads
- same TX result semantics
- same device status semantics
- same chunking protocol for client writes
- no separate iOS-only radio-control protocol

New protocol surface added for the app:
- `0xA024` Debug Stream notify characteristic
- expanded `device_command` payload support
- enriched `device_status` payload for dashboard/radio state

## Code layout

Current scaffold:

- `app/ios/project.yml` — XcodeGen source of truth
- `app/ios/PAKTiOS/PAKTiOSApp.swift` — app entry
- `app/ios/PAKTiOS/BLEProtocol.swift` — UUIDs, chunk split/reassembly, payload decoding helpers
- `app/ios/PAKTiOS/Models.swift` — protocol-aligned models
- `app/ios/PAKTiOS/BLEManager.swift` — CoreBluetooth transport/session state
- `app/ios/PAKTiOS/ContentView.swift` — SwiftUI tab shell and feature screens
- `app/ios/PAKTiOSTests/` — protocol-level smoke tests

## Screen set

V1 screen groups:

1. Device
- scan/connect/disconnect
- capability summary
- live device status

2. Packets
- session-only APRS monitor list from native `rx_packet`

3. GPS
- textual GPS fix and motion status

4. Transmit
- APRS TX request send
- beacon-now action
- raw command send
- TX result history

5. Radio
- RX/TX frequency
- squelch
- volume
- bandwidth

6. Debug
- toggle debug stream
- live append-only console
- clear session log

## Transport notes

- CoreBluetooth is wrapped in a single `BLEManager`
- the app subscribes to the native notify characteristics used by the desktop app
- debug stream subscription is enabled only when the user toggles it on
- chunking is required for client writes that may exceed one ATT payload, matching the desktop `chunker.py` behavior

## Session model

V1 is session-only:
- APRS packets are kept in memory only
- debug console is kept in memory only
- no local database
- no offline queueing

## Firmware dependencies

The app depends on firmware support for:
- `device_status` live notify
- `device_command` support for:
  - `radio_set`
  - `debug_stream`
  - `beacon_now`
- `debug_stream` notify characteristic

## Validation checklist

- app builds for iPhone simulator
- scan/connect flow works
- capability and config reads work
- APRS RX notify appears in the packet list
- GPS telemetry updates the GPS screen
- TX request yields `tx_result`
- radio settings write over `device_command`
- debug toggle enables/disables the dedicated debug stream
- desktop app still interoperates with the same firmware build

## Current handoff status

What is already verified in this repo state:
- firmware protocol additions build successfully with `idf.py build`
- the updated firmware was flashed successfully to the current prototype on `/dev/cu.usbmodem111101`
- the SwiftUI iPhone app scaffold generates from XcodeGen and builds for iOS Simulator
- the same iPhone app project also builds for a paired physical iPhone on this machine
- desktop Python telemetry tests pass after the protocol updates

What is still blocked:
- desktop BLE validation from this Mac was not completed in-session; host BLE scanning behaved inconsistently and should be rechecked by the next agent
- physical iPhone install/launch has not yet been verified end to end
- on-device iPhone BLE validation has not yet been run
- keep `app/ios/project.yml` and the generated `app/ios/PAKTiOS.xcodeproj` aligned on future changes; treat `project.yml` as the source of truth and regenerate deliberately

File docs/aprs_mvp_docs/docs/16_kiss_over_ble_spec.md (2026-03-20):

# KISS-over-BLE Profile — MVP Specification (INT-003)

Status: **MVP REQUIRED** — specification frozen for implementation.
Version: 0.2
Date: 2026-03-16

---

## 1. Purpose

This document defines the KISS-over-BLE profile: a transport-layer mapping of
the KISS TNC protocol [TAPR KISS] onto the PAKT BLE GATT service. The goal is
to enable existing APRS software (for example APRSdroid, YAAC, and Xastir) to
communicate with the PAKT TNC in MVP, either directly or through a thin bridge
utility where needed.

KISS is now an MVP requirement because third-party APRS software compatibility
is a core project goal. Native PAKT BLE remains the richer control/telemetry
protocol, but KISS-over-BLE must coexist with it in the same MVP release.

---

## 2. Background: KISS Protocol

KISS (Keep It Simple Stupid) is a simple framing protocol defined for TNC
communication over serial (RS-232/USB). Relevant properties:

- Frames delimited by `0xC0` (FEND) bytes
- Frame type byte: `0x00` = data frame, `0x0F` = return-from-KISS
- Special byte escaping: `0xC0 -> 0xDB 0xDC`, `0xDB -> 0xDB 0xDD`
- No ACK, no retransmit — KISS is a raw byte pipe

The PAKT BLE GATT service already provides structured message semantics
(chunking, ack, retry). The KISS profile adds a raw-frame pipe alongside the
structured service for compatibility with existing tools.

---

## 3. KISS-over-BLE Design

### 3.1 Transport approach

Rather than repurposing the existing APRS service characteristics, the KISS
profile adds a new **KISS Service** with two characteristics:

| Characteristic | UUID | Properties | Direction | Description |
|---|---|---|---|---|
| KISS RX | `544E4332-8A48-4328-9844-3F5CA0510000` | Notify | Device -> App | KISS frames decoded from RF, delivered to client |
| KISS TX | `544E4332-8A48-4328-9844-3F5CA0520000` | Write (with response) | App -> Device | KISS frames to transmit over RF |

### 3.2 Frame transport

KISS frames MAY exceed a single BLE ATT payload. The INT-002 chunking protocol
(`[msg_id:1][chunk_idx:1][chunk_total:1][payload...]`) is used for both KISS RX
and KISS TX characteristics, identical to the existing APRS service chunking.

- `mtu - 6` bytes of KISS frame data per chunk
- MVP maximum logical KISS frame size after reassembly: `330` bytes
- Oversize frames are dropped and counted as protocol errors

### 3.3 KISS service UUIDs

```
KISS Service:  544E4332-8A48-4328-9844-3F5CA0500000
KISS RX:       544E4332-8A48-4328-9844-3F5CA0510000  (notify)
KISS TX:       544E4332-8A48-4328-9844-3F5CA0520000  (write w/ response)
```

### 3.4 KISS frame handling

**TX path (App -> Device -> RF):**
1. App sends chunked KISS frame to KISS TX characteristic.
2. Firmware reassembles the frame via BleChunker.
3. Firmware strips FEND delimiters, un-escapes, and parses the KISS command byte.
4. Only port `0` data frames (`0x00`) are forwarded as AX.25 frames to the
   existing TX scheduler (`TxScheduler`).
5. Firmware does NOT send KISS-level ACK for data frames; KISS remains a raw pipe.
6. Invalid or oversize KISS frames are dropped and counted in error telemetry.

**RX path (RF -> Device -> App):**
1. Firmware decodes APRS/AX.25 frame from modem.
2. Firmware wraps the AX.25 frame in a KISS data frame (FEND `0x00` <data> FEND).
3. Firmware sends chunked KISS frame via KISS RX notify.
4. App reassembles and delivers to KISS-speaking software.

### 3.5 Return-from-KISS (`0x0F`)

If the app sends a frame with type byte `0x0F`, the device may echo a one-shot
`0x0F` compatibility response, but it does **not** switch modes. The device is
non-modal in MVP: native PAKT BLE and KISS-over-BLE may both remain active.

### 3.6 Multi-client arbitration

KISS mode and native PAKT mode operate simultaneously. The device sends both
KISS RX notifies and native `rx_packet` notifies for every decoded frame. TX
requests from the native `tx_request` characteristic and KISS TX characteristic
are merged into the same `TxScheduler` queue. KISS TX frames do not receive
`tx_result` notifies; KISS callers must implement their own retry logic if
needed.

---

## 4. Capability negotiation

Before using the KISS profile, the client MUST check the Device Capabilities
characteristic:

```python
caps = await client.read_capabilities()
if not caps.supports("kiss_ble"):
    # Fall back to native PAKT protocol
```

Firmware that supports the KISS profile will advertise `"kiss_ble"` in the
features list. Firmware without the KISS profile will not have the KISS Service
in its GATT table; attempting to subscribe to KISS RX will raise a
characteristic-not-found error.

---

## 5. MVP implementation scope

The MVP implementation consists of:

1. **Firmware**: `firmware/components/kiss/` — KissFramer (encode/decode), KISS
   GATT service added to BleServer, TX path integration into TxScheduler.
2. **Desktop bridge app**: `app/desktop_test/kiss_bridge.py` — accepts serial
   KISS connection (virtual COM or named pipe) and bridges to BLE KISS
   characteristics.
3. **Test vectors**: known KISS-encoded AX.25 frames with expected BLE chunk
   sequences.

---

## 6. MVP acceptance

The KISS profile is MVP-complete when all of the following are true:

1. KISS Service is present in the GATT table and capability record advertises `kiss_ble`.
2. A chunked KISS TX data frame reaches the shared TX scheduler and produces RF
   output through the normal APRS path.
3. A decoded RF frame appears on both native `rx_packet` and KISS RX.
4. Oversize or malformed KISS frames are dropped safely with no crash or stuck-TX behavior.
5. At least one third-party KISS client or bridge exchanges frames successfully
   with the device.

---

## 7. Protocol decisions frozen for MVP

1. KISS TX requires the same encrypted + bonded write policy as native `tx_request`.
2. Only port `0` is supported.
3. KISS extended commands (`0x01`-`0x06`) are ignored or treated as no-op in MVP.
4. Device operation is non-modal; native PAKT BLE and KISS-over-BLE may coexist.
5. The MVP logical frame size limit is 330 bytes after reassembly.

---

## 8. References

- TAPR KISS TNC specification: https://www.ax25.net/kiss.aspx (external)
- PAKT BLE GATT specification: `docs/aprs_mvp_docs/docs/05_ble_gatt_spec.md`
- INT-002 chunking specification: `docs/aprs_mvp_docs/docs/05_ble_gatt_spec.md` (chunk framing section)

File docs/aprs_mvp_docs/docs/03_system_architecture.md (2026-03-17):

# System architecture (high level)

## Major subsystems
1. RF subsystem
   - SA818 VHF module
   - Antenna, matching, filtering, shielding

2. Audio modem subsystem
   - SGTL5000 I2S audio codec (ADC/DAC, mono path in firmware)
   - Explicit `SYS_MCLK` from ESP32-S3 I2S clock output
   - Analog interface to SA818 AF in/out
   - DSP / modem running on ESP32-S3:
     - 1200 baud AFSK demod (Bell 202)
     - AX.25 framing/CRC
     - APRS encode/decode helpers

3. Positioning subsystem
   - GPS module (UART NMEA, optional PPS)

4. Connectivity subsystem
   - BLE GATT services
   - Windows desktop BLE test client (development and bench validation)
   - Phone BLE client (user-facing workflow)
   - KISS-over-BLE service for third-party APRS software
   - Optional Wi-Fi (later) for updates / gateway

5. Power subsystem
   - MCP73831/2 Li-ion/LiPo charger
   - MAX17048 battery gauge on I2C
   - Regulators (3.3V digital, SA818 supply as required)
   - Power switching (RF off in sleep)

## Data flow
- GPS -> ESP32 -> APRS encoder -> Audio DAC -> SA818 -> RF
- RF -> SA818 audio -> Codec ADC -> ESP32 demod -> packet stream -> BLE -> Phone
- RF -> SA818 audio -> Codec ADC -> ESP32 demod -> packet stream -> BLE -> Windows desktop test app
- Windows desktop test app -> BLE -> ESP32 -> APRS message encoder -> TX
- Phone -> BLE -> ESP32 -> APRS message encoder -> TX
- Third-party KISS client/bridge -> BLE KISS service -> ESP32 -> AX.25/TX scheduler -> TX
- RF -> ESP32 decode -> BLE KISS service -> third-party KISS client/bridge

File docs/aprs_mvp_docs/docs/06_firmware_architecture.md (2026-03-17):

# Firmware architecture (draft)

## RTOS model
ESP32-S3 FreeRTOS tasks suggested:
1. `radio_task`
   - SA818 UART config
   - PTT control
   - TX scheduling
2. `audio_task`
   - I2S read/write (SGTL5000 codec)
   - SGTL5000 clock and route init (including `SYS_MCLK` expectations)
   - AFSK demod/encode pipeline
3. `aprs_task`
   - AX.25 encode/decode
   - APRS parsing/building (position/message)
   - Message retry/ack state machine
4. `gps_task`
   - NMEA parse
   - Fix aging, smoothing, time
5. `ble_task`
   - GATT services, notify throttling
   - Config storage
   - Native PAKT BLE + KISS-over-BLE coexistence
6. `power_task`
   - battery measurement
   - sleep policy, wake sources

7. `kiss_task` or KISS module within `ble_task`/`aprs_task`
   - KISS frame encode/decode
   - shared queue integration with native TX/RX path

## Key interfaces
- `IAudioIO` (codec abstraction): `read_samples()`, `write_samples()`
- `IRadioControl`: `set_freq()`, `set_squelch()`, `ptt(on/off)`
- `IPacketLink`: send/receive AX.25 frames
- `IStorage`: config + logs

## Data structures
- Ring buffer for audio samples
- Packet queue:
  - RX decoded frames -> BLE notify
  - RX decoded frames -> KISS RX notify
  - TX requests -> scheduler
  - KISS TX requests -> same scheduler

## Timing
- Use precise sample rate (e.g., 8 kHz) for AFSK modem.
- Ensure SGTL5000 `SYS_MCLK` ratio is valid for selected sample rate.
- Ensure TX preamble flags and bit-stuffing per AX.25.
- Rate-limit BLE notifications to avoid starving modem.

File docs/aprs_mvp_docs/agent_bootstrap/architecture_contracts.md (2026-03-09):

# Architecture Contracts (Implementation Constraints)

## A. Firmware layer contracts
- `IAudioIO`: deterministic sample IO; no dynamic allocation in hot path.
- `IRadioControl`: idempotent `set_freq`, explicit `ptt(on/off)` state.
- `IPacketLink`: AX.25 frames in/out; no BLE concerns in this layer.
- `IStorage`: versioned config, atomic writes.

## B. BLE contract
- Use current UUID map from `../docs/05_ble_gatt_spec.md`. Base UUID: `544E4332-8A48-4328-9844-3F5C00000000`.
- Writes for config/command/TX require encrypted+bonded link.
- Chunking required above `(mtu-3)` with `msg_id/chunk_idx/chunk_total`.
- Firmware must function at default MTU.
- Notify paths must be rate-limited and must not starve modem/audio tasks.

## C. Audio/clock contract (SGTL5000 baseline)
- SGTL5000 requires valid `SYS_MCLK`; firmware and board must agree on clock source and ratio.
- Sample rate configuration is invalid unless SGTL5000 clock-ratio checks pass.
- Audio/modem path has priority over BLE notify bursts.
- BLE notify must be rate-limited to protect demod stability.
- TX state machine must fail safe to `PTT=off`.
- Startup/shutdown sequencing must avoid pop/click events on AF path where practical.

## D. App contract
- Separate transport (BLE) from mode logic (APRS/HF profiles).
- UI never sends raw radio commands without validation.
- Show explicit state for pending/ack/timeout.
- Desktop test app must validate GATT behavior before phone UX features depend on it.

## E. Compatibility contract
- New protocol behavior must be versioned.
- Unknown fields must be ignored (forward compatibility).
- Breaking changes require capability negotiation.

## F. Power/telemetry contract
- Charger path baseline is MCP73831/2; gauge baseline is MAX17048.
- Battery telemetry must expose both voltage and percentage if available.
- Telemetry reads must degrade gracefully when gauge data is temporarily unavailable.

## G. Error and recovery contract
- Any unrecoverable TX/audio/radio error forces `PTT=off`.
- Reinit paths must be idempotent (safe to call more than once).
- Recovery logic must use bounded retries: maximum 3 attempts with at least 1 s between attempts; escalate to error state if all retries fail.

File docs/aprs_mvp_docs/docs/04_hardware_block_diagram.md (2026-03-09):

# Hardware block diagram

See: `assets/hardware_block_diagram.png`

Notes:
- SGTL5000 is the current codec baseline for MVP/Rev A planning.
- Include explicit I2S `MCLK` routing from ESP32-S3 to SGTL5000 `SYS_MCLK`.
- Use an I2S codec path for stable audio levels and simpler filtering.
- Keep RF module physically separated/shielded from digital sections.
- Provide test points for audio in/out, PTT, UART, and power rails.

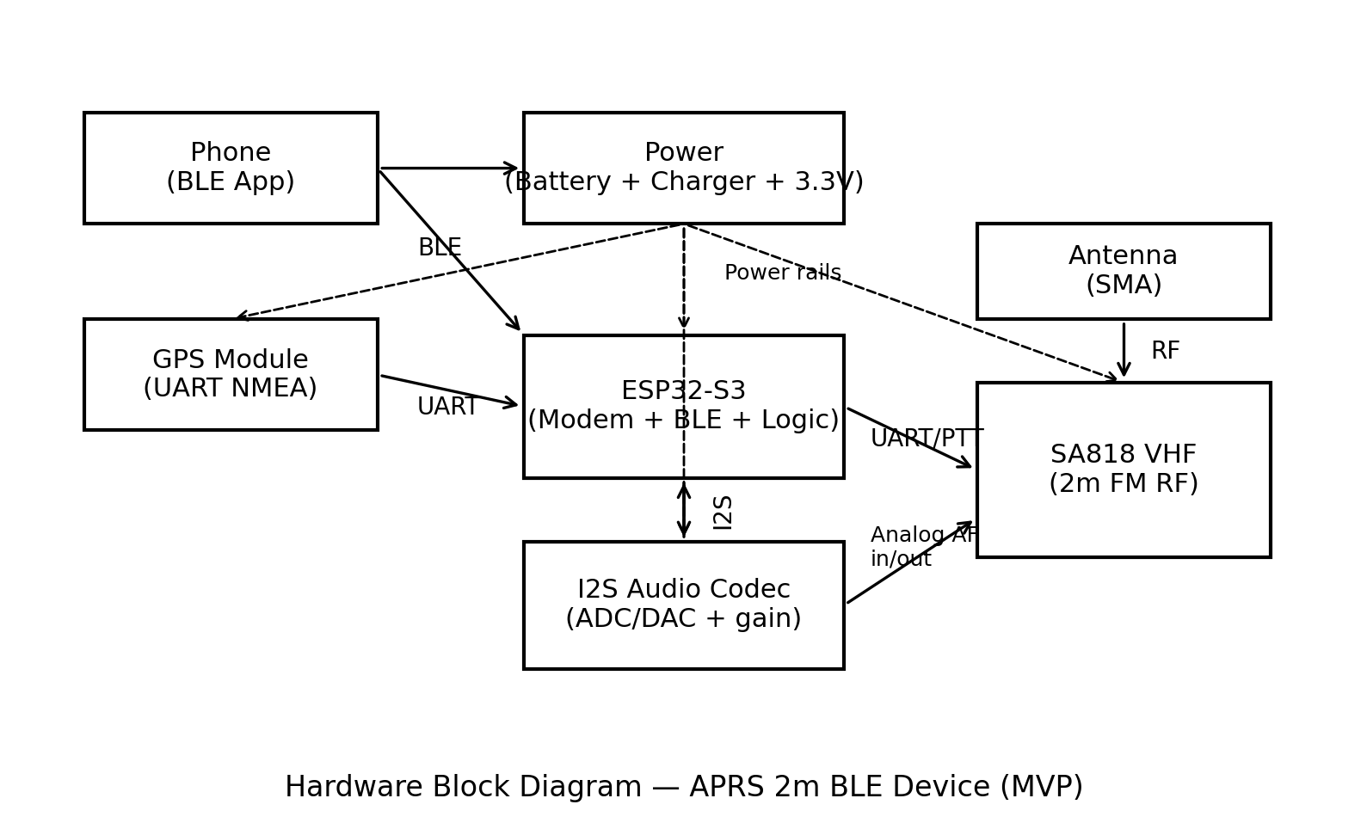
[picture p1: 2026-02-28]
docs/aprs_mvp_docs/assets/hardware_block_diagram.png

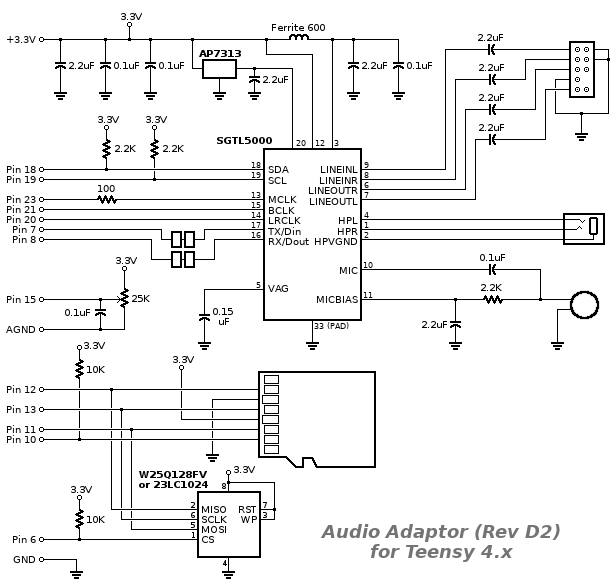
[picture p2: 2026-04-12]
docs/hardware/components/sgtl5000/schematic_audio4b.png

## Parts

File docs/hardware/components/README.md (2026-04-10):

# Hardware Component Library

This folder is the hardware source-of-truth library for PCB capture.

## Active component set
- `esp32-s3/` - ESP32-S3 module references used for the Feather-class MCU baseline.
- `sa818/` - SA818-V radio module references and imported CAD assets.
- `sgtl5000/` - SGTL5000 codec references and CAD assets for the bench-proven audio path.
- `neo-m8n/` - current GPS baseline is the u-blox `NEO-M9N` breakout/module; this folder name is legacy and will be renamed only when the schematic tree is moved to a dedicated PCB project.
- `gps-backup-battery/` - selected `V_BCKP` backup-cell references and implementation notes for the GPS block.
- `max17048/` - active fuel-gauge baseline for PCB capture.
- `mcp73831/` - active single-cell charger baseline for PCB capture.

## Archived legacy references
- `max17043/` - archived alternate; not part of the current PCB baseline.
- `wm8960/` - archived codec alternate; not part of the current PCB baseline.

## How to use this library
1. Start with each component folder's `sources.md` and `cad_assets.md`.
2. Use only the active component set above for the first KiCad schematic.
3. Treat archived folders as historical context only.
4. If a standard KiCad library part is preferred over a vendored local copy, record that explicitly in `cad_assets.md`.

## Important power-reference note
The battery and gauge reference for this project is the Adafruit ESP32-S3
Feather with `4MB Flash / 2MB PSRAM`, because that is the board used on the
bench and Adafruit's current guide for that board identifies `MAX17048` as the
fuel gauge.

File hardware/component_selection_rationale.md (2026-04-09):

# Confirmed Hardware Baseline

This document replaces the earlier option-screening rationale with the
bench-confirmed hardware baseline that should drive KiCad schematic capture.

## Locked subsystem choices

| Subsystem | Locked baseline | Status | PCB implication |
|---|---|---|---|
| MCU + BLE/Wi-Fi | Adafruit ESP32-S3 Feather with `4MB Flash / 2MB PSRAM` bench baseline | locked | Match the exact bench board family for power-domain behavior and proven GPIO usage. |
| RF modem module | `SA818-V` | locked | Keep UART + PTT + AF wiring unchanged from the bench profile. |
| Audio codec | `SGTL5000` | locked | Preserve `SYS_MCLK` requirement and the proven `LINE_OUT_L` / `LINE_IN_L` radio path. |
| GPS | u-blox `NEO-M9N` class | locked | Keep shared-I2C integration as the default baseline; retain UART fallback pads if space allows. |
| Fuel gauge | `MAX17048` | locked | Follow the Adafruit ESP32-S3 Feather `4MB Flash / 2MB PSRAM` bench-board behavior and pin usage. |
| Charger | `MCP73831T-2ACI/OT` topology | locked | Follow the same Feather bench-board charging behavior. |

## What is no longer part of the active baseline
- `WM8960` is no longer an active codec candidate.
- `MAX17043` is no longer an active fuel-gauge candidate.
- Older Feather battery-gauge topologies that use `LC709203` are not the reference for this PCB.
- The optional SSD1306 display is not part of the first PCB capture baseline.

## Bench-confirmed design rules to preserve

### ESP32-S3
- Preserve the proven bus and control mapping:
  - `GPIO3` -> `I2C_SDA`
  - `GPIO4` -> `I2C_SCL`
  - `GPIO8` -> `I2S_BCLK`
  - `GPIO15` -> `I2S_WS`
  - `GPIO12` -> `I2S_DOUT`
  - `GPIO10` -> `I2S_DIN`
  - `GPIO14` -> `I2S_MCLK`
  - `GPIO13` -> `SA818_RX_CTRL`
  - `GPIO9` -> `SA818_TX_STAT`
  - `GPIO11` -> `SA818_PTT`
  - `GPIO17/GPIO18` -> GPS UART fallback
- Keep UART debug/programming access on Rev A.

### SA818-V
- Preserve active-low PTT behavior.
- Keep local radio bulk capacitance near the module.
- Keep the antenna path short, controlled, and isolated from high-speed digital routing.

### SGTL5000
- Keep `SYS_MCLK` explicit in the schematic and routing plan.
- Preserve the firmware bring-up order: start `I2S/MCLK`, then configure the codec over I2C.
- Keep AC-coupled analog paths with DNP tuning footprints for TX attenuation and RX filtering.

### GPS
- Shared I2C is the default integration baseline because it is bench-proven.
- UART fallback remains useful for recovery, alternate modules, or debug.
- Add optional PPS if routing budget permits.

### Battery subsystem
- Mirror the Adafruit ESP32-S3 Feather with `4MB Flash / 2MB PSRAM` battery behavior so bench wiring and custom PCB behavior stay aligned.
- Keep charger, battery connector, bulk cap, and fuel gauge physically close to the battery entry area.
- Add test points for `VBAT_RAW`, `V_SYS_3V3`, `V_RADIO`, and charger status if possible.

## Schematic requirements generated from the confirmed baseline
1. Explicit `VBUS`, `VBAT_RAW`, `V_SYS_3V3`, `V_AUD_3V3`, and `V_RADIO` nets.
2. Explicit `I2S_MCLK` net from ESP32-S3 to SGTL5000.
3. DNP footprints for AF gain shaping and receive filtering.
4. DNP footprint for an optional PTT transistor stage.
5. USB-C sink `CC1/CC2` resistors and ESD protection on external connectors.
6. Radio bulk capacitance close to the SA818 supply entry.

## PCB release gates
1. SA818 supply droop and PTT polarity remain stable on the bench baseline.
2. TX deviation has measured, repeatable attenuation values.
3. RX decode remains repeatable on the proven SGTL5000 path.
4. No brownout or reset occurs during repeated TX cycles.
5. Every active BOM line has at least one real sourceable candidate and a verified package.

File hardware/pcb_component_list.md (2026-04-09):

# PCB Component List

This is the first-pass component list for KiCad capture. It is organized around
the confirmed bench baseline and is intended for review before schematic entry.

## Status keys
- `locked` — selected from the bench-proven baseline.
- `reference-derived` — taken from the Adafruit reference design and should be reviewed.
- `tuning` — expected to be finalized from bench measurements or datasheet review.

## Core active components

| Subsystem | Item | Component / value | Package / form | Status | Notes |
|---|---|---|---|---|---|
| MCU | U1 | ESP32-S3 module, matching Adafruit ESP32-S3 Feather `4MB Flash / 2MB PSRAM` | module | locked | Match the exact bench board family. |
| Radio | U2 | `SA818-V` | module | locked | Bench-proven radio baseline. |
| Codec | U3 | `SGTL5000` | QFN-32 | locked | Bench-proven audio codec. |
| GPS | U4 | u-blox `NEO-M9N` class module | module | locked | Shared-I2C baseline, UART fallback optional. |
| Fuel gauge | U5 | `MAX17048` | TDFN-8 | locked | Use the `MAX17048` family, not `MAX17043`. |
| Charger | U6 | `MCP73831T-2ACI/OT` | SOT-23-5 | locked | Adafruit-style single-cell charger baseline. |
| 3V3 regulator | U7 | main `3.3V` regulator | TBD | reference-derived | Final part depends on current budget and power-path strategy. |

## Battery / USB / charge section

| Item | Component / value | Package / form | Status | Notes |
|---|---|---|---|---|
| J1 | USB-C receptacle | USB-C | locked | USB device + charging input. |
| R1 | `5.1 kOhm` `CC1` resistor | 0603 | reference-derived | USB-C sink configuration. |
| R2 | `5.1 kOhm` `CC2` resistor | 0603 | reference-derived | USB-C sink configuration. |
| J2 | JST-PH-2 battery connector | through-hole / SMT hybrid | locked | Single-cell Li-ion battery connector. |
| U6 | `MCP73831T-2ACI/OT` | SOT-23-5 | locked | Charger IC. |
| R3 | `PROG` resistor, start with `5.1 kOhm` | 0603 | reference-derived | Review against desired battery charge current. |
| D1 | Charge LED | 0603 | reference-derived | Driven from charger `STAT`. |
| R4 | Charge LED resistor, start with `5.1 kOhm` | 0603 | reference-derived | Mirrors Adafruit approach. |
| C1 | Charger input bulk cap, start with `10 uF` | 0805 | reference-derived | Place close to charger input. |
| C2 | Battery-node bulk cap, start with `10 uF` | 0805 | reference-derived | Place close to battery node / charger. |
| U5 | `MAX17048` | TDFN-8 | locked | Fuel gauge IC. |
| TP1 | `VBAT_RAW` test point | test pad | locked | Required for bring-up. |

## ESP32-S3 support

| Item | Component / value | Package / form | Status | Notes |
|---|---|---|---|---|
| SW1 | Reset button | tact switch | locked | Keep on Rev A. |
| SW2 | Boot / recovery button | tact switch | locked | Keep on Rev A. |
| R5 | `EN` pull-up, start with `10 kOhm` | 0603 | reference-derived | Mirrors Feather-class support network. |
| C3 | `EN` / reset timing capacitor, start with `1 uF` | 0603 | reference-derived | Review with final module/reset topology. |
| J3 | Debug / programming header | header or tag-connect | locked | Keep early bring-up easy. |
| C4..C7 | ESP32 supply decoupling caps | `100 nF + bulk` | tuning | Final quantity depends on selected module and regulator. |

## I2C shared bus

| Item | Component / value | Package / form | Status | Notes |
|---|---|---|---|---|
| R6 | `I2C_SDA` pull-up, `2.2 kOhm` to `4.7 kOhm` | 0603 | tuning | Only one effective pull-up set on the bus. |
| R7 | `I2C_SCL` pull-up, `2.2 kOhm` to `4.7 kOhm` | 0603 | tuning | Shared by SGTL5000, MAX17048, GPS. |

## SGTL5000 audio section

| Item | Component / value | Package / form | Status | Notes |
|---|---|---|---|---|
| U3 | `SGTL5000` | QFN-32 | locked | Main audio codec. |
| C8..C15 | Codec supply decoupling network | mixed | tuning | Pull exact values from the NXP datasheet during schematic capture. |
| FB1 | Ferrite bead for `V_AUD_3V3` | 0603 | reference-derived | DNP-capable if not needed. |
| C16 | `AF_TX` AC-coupling cap, start with `1 uF` | 0603/0805 | locked | Between codec output and SA818 AF input network. |
| R8 / R9 | `AF_TX` attenuation network | 0603 | tuning | Final values depend on measured TX deviation. |
| C17 | `AF_RX` AC-coupling cap, start with `1 uF` | 0603/0805 | locked | Between SA818 AF output and codec line input. |
| R10 / C18 | Optional `AF_RX` RC filter | 0603 | tuning | DNP-capable bench-tuning network. |

## SA818 radio section

| Item | Component / value | Package / form | Status | Notes |
|---|---|---|---|---|
| U2 | `SA818-V` | module | locked | Main radio module. |
| C19 | Radio local decoupling `100 nF` | 0603 | locked | Place at module supply entry. |
| C20 | Radio local bulk `10 uF` | 0805/1206 | locked | Place at module supply entry. |
| C21 | Radio burst bulk `220 uF` to `470 uF` | electrolytic / polymer | tuning | Final value to be confirmed from TX supply droop measurement. |
| Q1 | Optional PTT transistor stage | SOT-23 | tuning | DNP unless direct drive proves weak/noisy. |
| R11 / R12 | Optional PTT bias resistors | 0603 | tuning | Populate only if transistor stage is used. |
| J4 | Antenna connector | SMA or U.FL | locked | Depends on enclosure/mechanics. |

## GPS section

| Item | Component / value | Package / form | Status | Notes |
|---|---|---|---|---|
| U4 | `NEO-M9N` class module | module | locked | Shared-I2C baseline. |
| C22..C24 | GPS local decoupling caps | mixed | tuning | Pull exact values from the chosen module datasheet. |
| TP2 | Optional PPS test point | test pad | reference-derived | Useful during bring-up. |

## User interface / support

| Item | Component / value | Package / form | Status | Notes |
|---|---|---|---|---|
| D2 | Status LED | 0603 | reference-derived | Firmware-controlled. |
| D3 | RX LED | 0603 | reference-derived | Firmware-controlled. |
| D4 | TX LED | 0603 | reference-derived | Firmware-controlled. |
| R13..R15 | LED resistors | 0603 | tuning | Final value depends on LED choice and brightness target. |
| SW3 | Function button | tact switch | reference-derived | Optional but useful on Rev A. |
| TP3..TP6 | `V_SYS_3V3`, `V_RADIO`, `AF_TX_COUPLED`, `AF_RX_COUPLED` | test pads | locked | Strongly recommended. |

## Open review items before schematic entry
1. Lock the exact ESP32-S3 module orderable.
2. Confirm the main `3.3V` regulator part and current headroom.
3. Decide whether `MAX17048 !ALRT` is routed to the MCU.
4. Confirm the desired charger current and therefore the final `PROG` resistor.
5. Replace the tuning placeholders in the SGTL5000 and GPS sections with datasheet-derived values.

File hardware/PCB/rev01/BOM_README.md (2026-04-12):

# Rev01 BOM Notes

This folder now includes two BOM helper files:

- `rev01_bom_preferred.csv`: one line per reference with preferred MPN/manufacturer.
- `rev01_bom_grouped.csv`: grouped line items with quantity and reference list.

## Packaging strategy applied

- Resistors: standardized to `0603` (`R_0603_1608Metric`).
- Ferrite beads: standardized to `0603` (`BLM18PG121SN1D` family).
- Capacitors:
  - `100n`, `1u`, `2.2u`: mostly `0603`.
  - `4.7u`, `10u`: mostly `0805` for capacitance derating margin.
  - `47pF` RF matching capacitor (`C26`): `0402`.
  - `100u` bulk (`C10`): kept `1206`.
  - Polymer bulk (`C33`): kept custom footprint.
- LEDs: unified to `0603`.

## Important review items before release

- Confirm exact ESP32 module variant for production order (`U2` flash/PSRAM option).
- Confirm exact GPS module order code (`U1`, e.g. `NEO-M8N-0` vs `NEO-M8M-0`).
- Verify RF-matching/passive choices (`L3`, `C26`, `R23`) against measured RF results.
- Verify TVS part selection (`D5`) against final USB protection requirement.
- Treat `DNP` entries as not populated unless intentionally enabled.

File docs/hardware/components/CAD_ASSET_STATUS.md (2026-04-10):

# CAD Asset Status

This file tracks the CAD assets that matter for the current PCB baseline.

## Status legend
- `exact`: ready to use as-is for the active hardware baseline.
- `provisional`: usable with explicit pre-schematic verification.
- `reference-only`: archived or historical, not part of the active PCB baseline.

## Active component matrix
| Component | Symbol | Footprint | STEP | Status | Notes |
|---|---|---|---|---|---|
| `esp32-s3` | `RF_Module.kicad_sym` | `ESP32-S3-WROOM-1.kicad_mod` | `ESP32-S3-WROOM-1.step` | provisional | Use as a module reference only after matching the exact module variant for the PCB. |
| `sa818` | `SA818S.kicad_sym` | `XCVR_SA818S.kicad_mod` | `SA818S.step` | exact | Bench baseline radio module. |
| `sgtl5000` | `Audio.kicad_sym` | `QFN-32-1EP_5x5mm_P0.5mm_EP3.6x3.6mm.kicad_mod` | `QFN-32-1EP_5x5mm_P0.5mm_EP3.7x3.7mm.step` | provisional | Symbol is fine; confirm exposed-pad size and 3D fit before PCB release. |
| `neo-m8n` | `RF_GPS.kicad_sym` | `ublox_NEO.kicad_mod` | `NEO-M9N-00B.step` | provisional | Folder name is legacy; current bench baseline is `NEO-M9N`. |
| `gps-backup-battery` | standard KiCad (`Device:Battery_Cell`, `Device:D_Schottky`) | selected during schematic (`BR-1225A/FAN` tab pattern + SOD-323 diode) | n/a | provisional | Backup battery path is now part of rev01 plan; verify exact battery tab footprint against chosen cell. |
| `max17048` | `MAX17048.kicad_sym` | `DFN-8-1EP_3x2mm_P0.5mm_EP1.7x1.4mm.kicad_mod` | `DFN-8-1EP_3x2mm_P0.5mm_EP1.75x1.45mm.step` | provisional | Dedicated local symbol added; confirm package drawing against exact orderable suffix before release. |
| `mcp73831` | `MCP73831.kicad_sym` | `Package_TO_SOT_SMD:SOT-23-5` | standard KiCad 3D model | provisional | Active charger package is `SOT-23-5`; do not use the old placeholder DFN mapping. |

## Archived references
| Component | Status | Notes |
|---|---|---|
| `max17043` | reference-only | Archived alternate, not part of the current PCB baseline. |
| `wm8960` | reference-only | Archived codec alternate, not part of the current PCB baseline. |

## Pre-schematic checks still required
1. Lock the exact ESP32-S3 module orderable tied to the final antenna/module strategy.
2. Confirm the SGTL5000 exposed pad and analog supply pin decoupling network from the NXP datasheet.
3. Confirm the exact `NEO-M9N` mechanical model if enclosure clearance is tight.
4. Verify the MAX17048 and MCP73831 package land patterns against selected manufacturers' package drawings before fab release.
5. Verify `BR-1225A/FAN` tab footprint land dimensions and polarity marking before PCB release.

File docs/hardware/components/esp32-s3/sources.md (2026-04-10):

# ESP32-S3 Sources

## Official datasheets
- ESP32-S3 Datasheet (Espressif PDF)
  - https://www.espressif.com/en/support/documents/technical-documents/datasheets/ESP32-S3-Datasheet.pdf
- ESP32-S3-WROOM-1/WROOM-1U Datasheet (module-level)
  - https://www.espressif.com/sites/default/files/documentation/esp32-s3-wroom-1_wroom-1u_datasheet_en.pdf
- ESP32-S3 Technical Reference Manual (Espressif PDF)
  - https://www.espressif.com/sites/default/files/documentation/esp32-s3_technical_reference_manual_en.pdf

## Official application notes / design guidance
- ESP32-S3 Hardware Design Guidelines
  - https://documentation.espressif.com/esp-hardware-design-guidelines/en/latest/esp32s3/index.html
- ESP32-S3 Series SoC Errata
  - https://www.espressif.com/en/support/documents/technical-documents/errata/esp32-s3-series-soc-errata

## Bench-board reference
- Adafruit Learn guide: Adafruit ESP32-S3 Feather
  - https://learn.adafruit.com/adafruit-esp32-s3-feather/overview
- Adafruit Learn downloads page
  - https://learn.adafruit.com/adafruit-esp32-s3-feather/downloads

## Notes
- Use the Hardware Design Guidelines and errata as mandatory review before schematic freeze.
- For this project, the exact bench board is the Adafruit ESP32-S3 Feather with `4MB Flash / 2MB PSRAM`.
- Module integration reminders for rev01:
  - Preserve antenna keepout for `ESP32-S3-WROOM-1` PCB antenna.
  - Keep EN/boot-strapping support network explicit in schematic.

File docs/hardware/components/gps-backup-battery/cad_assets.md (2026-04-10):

# CAD Assets

This folder tracks schematic/PCB assets for the GPS backup battery support path.

## Symbol intent
- Battery symbol (`Device:Battery_Cell` or project-local equivalent).
- Schottky diode symbol (`Device:D_Schottky`).
- Optional 0 ohm link symbol (`Device:R` with value `0R`, default DNP).

## Footprint intent
- Battery:
  - Prefer the exact footprint matching selected tab-cell package dimensions for `BR-1225A/FAN`.
- Schottky diode:
  - `SOD-323` or `SOD-523` class footprint (based on chosen diode part).
- Optional link resistor:
  - `0402`/`0603` according to assembly preference.

## Verification checklist
1. Battery footprint polarity and keepout are correct.
2. `V_BCKP` diode orientation is battery -> `V_BCKP`.
3. `VCC -> V_BCKP` 0 ohm link is marked DNP by default when battery is used.

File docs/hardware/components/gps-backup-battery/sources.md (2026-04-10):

# GPS Backup Battery Sources

## Selected battery (rev01 default)
- Panasonic `BR-1225A/FAN` (3 V, 48 mAh, tab-mount primary lithium coin cell)
  - Product listing:
    - https://www.digikey.com/en/products/detail/panasonic-energy/BR-1225A-FAN/447501
  - Datasheet page:
    - https://www.digikey.com/htmldatasheets/production/3718077/0/0/1/br-1225a-fan.html

## GPS backup-domain references
- u-blox NEO-M9N Integration Manual (backup battery and minimal design guidance)
  - https://content.u-blox.com/sites/default/files/NEO-M9N_Integrationmanual_UBX-19014286.pdf
- u-blox NEO-M9N datasheet
  - https://www.u-blox.com/sites/default/files/NEO-M9N-00B_DataSheet_UBX-19014285.pdf

## Notes
- `BR-1225A/FAN` is non-rechargeable. Do not implement any charge path into the battery node.
- Keep isolation diode + DNP fallback link strategy in schematic so `V_BCKP` source can be switched without PCB respin.

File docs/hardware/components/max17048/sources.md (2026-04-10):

# MAX17048 Sources

## OEM references
- Analog Devices product page
  - https://www.analog.com/en/products/max17048.html
- Analog Devices datasheet PDF
  - https://www.analog.com/media/en/technical-documentation/data-sheets/max17048-max17049.pdf

## OEM application / design guidance
- Analog Devices technical article: Characterizing a Battery for Use with a Fuel Gauge
  - https://www.analog.com/en/resources/technical-articles/battery-gauge--maxim-integrated.html

## Bench-board reference
- Adafruit Learn guide: Adafruit ESP32-S3 Feather
  - https://learn.adafruit.com/adafruit-esp32-s3-feather/overview
- Adafruit Learn downloads page
  - https://learn.adafruit.com/adafruit-esp32-s3-feather/downloads

## Project note
- `MAX17048` is the locked fuel-gauge baseline for the custom PCB.
- The bench board is the Adafruit ESP32-S3 Feather with `4MB Flash / 2MB PSRAM`.
- Adafruit's current public Learn guide for that board identifies `MAX17048` as the battery gauge.
- Datasheet capture notes for schematic:
  - `VDD` bypass capacitor `0.1 uF` to GND is required.
  - `QSTRT` should be tied to GND when unused.
  - `ALRT`/`SDA`/`SCL` require system pullups when used.

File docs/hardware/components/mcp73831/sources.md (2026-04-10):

# MCP73831 Sources

## OEM references
- Microchip product page
  - https://www.microchip.com/en-us/product/MCP73831
- Microchip datasheet landing page
  - https://www.microchip.com/en-us/product/MCP73831#document-table
- Microchip datasheet PDF (`DS20001984H`)
  - https://ww1.microchip.com/downloads/en/DeviceDoc/MCP73831-Family-Data-Sheet-DS20001984H.pdf

## OEM application notes
- AN1149: Battery Charger System Design for a Single-Cell Li-Ion Battery
  - https://www.microchip.com/en-us/application-notes/an1149
- AN947: Power Management in Portable Applications: Charging Lithium-Ion/Lithium-Polymer Batteries
  - https://www.microchip.com/en-us/application-notes/an947

## Bench-board reference
- Adafruit Learn guide: Adafruit ESP32-S3 Feather
  - https://learn.adafruit.com/adafruit-esp32-s3-feather/overview

## Project notes
- The project baseline is `MCP73831T-2ACI/OT`.
- Use the Adafruit ESP32-S3 Feather with `4MB Flash / 2MB PSRAM` as the bench-board reference when reviewing the charger section.
- Keep `5.1 kOhm` as the starting `PROG` resistor assumption unless the battery charge-current target changes during sourcing review.
- Pull the exact datasheet PDF revision from the Microchip product page before fab release.
- Datasheet capture notes for schematic:
  - `VDD` and `VBAT` each need at least `4.7 uF` bypass to `VSS`.
  - Charge current formula: `IREG (mA) = 1000 / RPROG (kOhm)`.
  - Hot-pluggable input should include transient suppression (TVS/transorb).

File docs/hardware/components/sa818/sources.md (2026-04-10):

# SA818 Sources

## Official datasheets
- SA818 Product Download Center (NiceRF)
  - https://www.nicerf.com/driver?m=driver&f=driver&driver_id=88
- NiceRF Download Center (All documents)
  - https://www.nicerf.com/download/
- SA818S-CE product page (includes specs, pin definitions, and typical application circuit)
  - https://www.nicerf.com/walkie-talkie-module/walkie-talkie-module-sa818s-ce.html
- SA818S 1W Embedded walkie talkie module datasheet V1.7 (direct file endpoint)
  - https://www.nicerf.com/download_file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

## Official application notes / programming guidance
- SA818 Program Software User Manual (from SA818 download center)
- SA818 FAQ / command examples (from SA818 download center)
- SA818 SA818S SA868 programming manual (NiceRF direct file endpoint, password-protected)
  - https://www.nicerf.com/download_file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

## Notes
- NiceRF hosts SA818 docs in the module download center. Save exact PDF revisions into this folder before schematic release.
- Downloaded locally for this repo snapshot:
  - `SA818S_1W_Embedded_walkie_talkie_module_V1.7.pdf`
  - `SA818S_typical_application_circuit.jpg`

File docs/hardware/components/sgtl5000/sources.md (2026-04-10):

# SGTL5000 Sources

## Datasheet / Product
- NXP SGTL5000 product page
  - https://www.nxp.com/products/audio-and-radio/audio-converters/ultra-low-power-audio-codec%3ASGTL5000
- NXP SGTL5000 datasheet (Rev. 7, 2022-01)
  - https://www.nxp.com/docs/en/data-sheet/SGTL5000.pdf

## Evaluation hardware
- NXP SGTL5000 evaluation kit
  - https://www.nxp.com/products/audio-and-radio/audio-converters/evaluation-kit-sgtl5000-low-power-stereo-codec%3AKITSGTL5000EVBE

## Notes
- SGTL5000 is selected as current project baseline codec for MVP and Rev A planning.
- Ensure `SYS_MCLK` planning is explicit in schematic and firmware clock configuration.
- Mono modem operation should use a single channel with deterministic routing and gain control.
- External `VDDD` is required for new designs (per NXP datasheet typical application note).

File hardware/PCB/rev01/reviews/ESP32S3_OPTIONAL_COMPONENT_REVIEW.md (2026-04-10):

# ESP32-S3 Review 01: Optional/Support Components for Rev01

Scope: `ESP32-S3-WROOM-1` module integration only, focused on boot/reset robustness, power stability, and RF-safe layout support parts.

Primary references:
- ESP32-S3-WROOM-1/WROOM-1U datasheet:
  - https://www.espressif.com/sites/default/files/documentation/esp32-s3-wroom-1_wroom-1u_datasheet_en.pdf
- ESP32-S3 hardware design guidelines:
  - https://documentation.espressif.com/esp-hardware-design-guidelines/en/latest/esp32s3/index.html

---

## 1. Key constraints from official guidance

- Boot strapping depends on GPIO strapping pins (`GPIO0`, `GPIO45`, `GPIO46`; plus `GPIO3` for JTAG source selection).
- `GPIO0` and `GPIO46` control boot mode at reset; signal timing must satisfy setup/hold around reset release.
- Module placement must protect antenna performance; baseboard interference near antenna region should be minimized.
- Hardware guidelines recommend 3.3 V supply with sufficient current capability and local input capacitance/ESD protection at power entry.

---

## 2. Power stability and entry protection

Populate now:
1. `TVS_3V3_IN` (or upstream rail TVS) at module power entry if rail is exposed to cable/hot-plug transients.
2. `C_3V3_ENTRY_10uF` bulk capacitor at 3.3 V entry to the ESP32 power branch.
3. `C_3V3_LOCAL_100nF` decoupling near module power pins (at least one per local power cluster).
4. Keep power feed short/wide and ensure low-impedance return path.

DNP options to place now:
1. Extra local `1uF` footprint near module supply pins if bench shows transient droop.
2. Ferrite bead footprint for isolating noisy digital branch if coexistence noise appears.

---

## 3. Reset/boot support network

Populate now:
1. `R_EN_PULLUP` (10k typical) on EN/CHIP_PU.
2. `C_EN_DELAY` (100 nF to 1 uF footprint) to GND for reset stabilization/boot reliability tuning.
3. `R_IO0_PULLUP` (10k typical) so normal boot defaults to SPI boot.
4. `BOOT` pushbutton footprint to pull `GPIO0` low for download mode.
5. `RESET` pushbutton footprint on EN.

DNP options to place now:
1. Auto-program transistor network footprint (USB-UART DTR/RTS to EN/IO0) if automated flashing is desired in rev01.
2. Small series resistor footprints on EN/IO0 control lines for edge/noise tuning.

Note:
- Exact pull-up/down values can be finalized after combined MCU + USB-UART interface decision; values above are standard integration practice for ESP modules.

---

## 4. Strapping pin safety and reserved pins

Populate/layout now:
1. Keep strapping-pin external loads weak/high-impedance at reset unless intentionally controlling boot behavior.
2. Avoid large capacitive loads directly on strapping pins.
3. Keep test points for at least `EN`, `GPIO0`, `U0TXD`, `U0RXD`.

Design rule notes:
- Respect module-specific unavailable pins tied to in-package memory interfaces (variant-dependent) per module datasheet.
- Do not place copper/ground/features in antenna keepout region.

---

## 5. Minimal practical BOM additions (ESP32-S3 section)

Populate now:
1. `R_EN_PULLUP`
2. `C_EN_DELAY`
3. `R_IO0_PULLUP`
4. `SW_BOOT` and `SW_RESET`
5. `C_3V3_ENTRY_10uF` + local decoupling (`100nF` class)

Place as DNP/optional:
1. Auto-program transistor network
2. Extra local `1uF` near module supply
3. Ferrite bead on module power branch

---

## 6. Recommended rev01 population

- Populate robust manual boot/reset network and power-entry stabilization now.
- Keep auto-download circuit as DNP footprint unless you want immediate USB-UART one-click flashing on prototype boards.
- Reserve antenna keepout strictly in layout and keep noisy/high-current nets away from module antenna edge.

Bench checks to decide optional population:
- Cold-boot and reset reliability across supply ramp profiles.
- Flash/download reliability with chosen programming workflow.
- RF performance sensitivity to nearby board features.

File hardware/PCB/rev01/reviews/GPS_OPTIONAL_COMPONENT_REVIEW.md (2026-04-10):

# GPS Review 01: NEO-M9N / NEO-M8N-Layout Optional Support Components

Scope: GPS section only (as requested), focused on supply stability, filtering, and startup behavior.

Primary references:
- NEO-M9N Integration Manual (UBX-19014286, R10, 2025-03-27)
  - https://content.u-blox.com/sites/default/files/NEO-M9N_Integrationmanual_UBX-19014286.pdf
- NEO-M9N-00B Datasheet (UBX-19014285, R08, 2025-10-09)
  - https://www.u-blox.com/sites/default/files/NEO-M9N-00B_DataSheet_UBX-19014285.pdf

---

## 1. Decisions You Should Make Now (GPS-only)

### A) Backup domain strategy (`V_BCKP`)
- Why: without `V_BCKP`, module cold-starts each boot.
- Datasheet/integration guidance: connect backup battery to `V_BCKP` for warm/hot starts; if no backup source, tie `V_BCKP` to `VCC`.

Recommendation:
- Add all three options in schematic now:
  1. `R_DNP` link: `VCC -> V_BCKP` (default populated for first build).
  2. Backup-source footprint option (coin cell or supercap) to `V_BCKP`.
  3. Isolation diode footprint (DNP by default) between backup source and `V_BCKP`.

This gives you startup-performance flexibility without PCB respin.

### B) USB usage on GPS (`V_USB` pin)
- If GPS USB is not used: `V_USB` must be tied to GND.
- If USB is used: keep 1 uF local capacitor near `V_USB`; u-blox recommends separate LDO path for USB supply behavior.

Recommendation for PAKT rev01:
- You are not planning GPS USB now -> tie `V_USB` to GND in schematic, no connector required.

### C) RF front-end protection level
- u-blox flags RF input ESD protection as mandatory in real-world integration.

Recommendation:
- Add ESD diode footprint at antenna connector to GND (populate by default).
- Keep optional footprints for extra protection/filtering (DNP unless testing requires):
  - series RF element / 0 ohm jumper position
  - SAW footprint or matching placeholder

---

## 2. Power/Supply Stability Components

## Must-have (populate)
- `C_VCC_1uF` close to GPS `VCC` pin.
- `C_VCC_100nF` close to GPS `VCC` pin.
- Solid low-impedance `VCC` feed (avoid series resistance in supply path; short/wide feed).
- Full ground pin stitching to ground plane.

## Strongly recommended (populate)
- Keep GPS supply branch isolated from noisy digital/radio return loops (placement/routing discipline).
- Add at least one GPS rail test point (`TP_GPS_VCC`) and one ground probe point nearby.

## Optional (DNP footprints)
- Ferrite bead in GPS `VCC` branch (`FB_GPS`) if conducted noise appears during coexistence tests.
- Extra bulk cap footprint (`4.7 uF` to `10 uF`) near module in case of rail droop in full-system operation.

---

## 3. RF/Antenna Optional Components

## Must-have (populate)
- ESD protection path at antenna input.
- Controlled-impedance RF trace planning (50 ohm target), no stubs.

## Optional by use-case
- Bias-tee inductor footprint if active antenna feed is needed from `VCC_RF`.
- Current-limit resistor footprint in `VCC_RF` feed path for short-circuit robustness in active-antenna scenarios.
- Optional external LNA/SAW placeholders only if your enclosure/RF environment proves hostile.

For first PAKT board: place footprints, leave DNP unless bench validates need.

---

## 4. Interface/Protection Optional Components

## Recommended optional footprints
- `SAFEBOOT_N` test pad (or tiny header access) for recovery/firmware service.
- `TIMEPULSE` test pad (excellent for bring-up timing/lock diagnostics).
- Optional open-drain isolation footprint on host I/O paths if you plan deep backup scenarios with host rails off (prevents back-powering through IOs).

---

## 5. Minimal Practical BOM Additions (GPS section)

Populate now:
1. `C_GPS_VCC_1uF` (X7R).
2. `C_GPS_VCC_100nF` (X7R).
3. `ESD_RF_GPS` diode at antenna connector.
4. `BAT_GPS_BCKP` = `Panasonic BR-1225A/FAN` (3 V, 48 mAh, tab-mount primary coin cell).
5. `D_GPS_BCKP_OR` = Schottky isolation diode (`BAT54`-class) in series from battery to `V_BCKP`.
6. `TP_TIMEPULSE` and `TP_GPS_VCC`.

Place as DNP options now:
1. `R_VBCKP_LINK` (0 ohm) from `VCC` to `V_BCKP` (lab/fallback option only; keep DNP when battery is populated).
2. `FB_GPS_VCC` ferrite bead.
3. `C_GPS_BULK` 4.7-10 uF.
4. `L_BIAS_TEE` for active antenna power path.
5. Optional RF front-end placeholder parts (series/SAW position).

---

## 6. My Recommendation for Rev01 (fastest safe path)

- Populate: basic decoupling + ESD + backup battery path on `V_BCKP` + testpoints.
- Keep DNP: `VCC -> V_BCKP` fallback link and active-antenna bias path.
- Validate on bench:
  - TTFF and reacquisition performance first.
  - If startup behavior is not acceptable, populate backup source next spin/next build.

---

## 7. Selected Backup Battery (locked for review)

Chosen part:
- `Panasonic ML-1220/F1AN` (rechargeable lithium coin cell, 3 V class).

Why this part:
- Active industrial part with standard 12.5 mm coin-cell form factor.
- Commonly sourced through major distributors; practical for prototype and low-volume builds.
- Capacity (48 mAh nominal) is usable for GPS backup retention without adding a charging circuit.

Implementation notes:
- Keep the isolation diode (`BAT54`-class) between backup battery positive and `V_BCKP`.
- Add low-current trickle path for rechargeable option:
  - `+3V3 -> R18 (100k) -> D7 (BAT54) -> GPS_BCKP_BAT`.
- Keep the `VCC -> V_BCKP` 0 ohm fallback link footprint (`R6`) for bring-up flexibility.
- If you switch back to a primary (non-rechargeable) coin cell, do not populate the trickle-charge path.

Source links:
- u-blox integration guidance (`V_BCKP`, `V_USB`, minimal design):
  - https://content.u-blox.com/sites/default/files/NEO-M9N_Integrationmanual_UBX-19014286.pdf
- Rechargeable backup battery references:
  - https://industry.panasonic.com/global/en/products/primary-batteries/rechargeable-coin/ml

If you want, next message I can convert this into exact schematic symbols/refs/nets for your current `rev01.kicad_sch` naming so you can drop them in directly.

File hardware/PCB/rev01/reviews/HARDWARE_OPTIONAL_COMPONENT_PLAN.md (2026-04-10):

# Rev01 Optional Components Plan

This plan tracks datasheet-driven optional/support components one block at a time, with explicit decisions for what we populate in `rev01` vs leave as DNP.

## Current status

| Block | Review file | Status | Decision summary |
|---|---|---|---|
| GPS (`NEO-M8N`/`M9N`-layout compatible) | `GPS_OPTIONAL_COMPONENT_REVIEW.md` | done | Add backup battery path + decoupling + RF ESD now; keep ferrite/bias-tee/extra RF filtering as DNP options. |
| Radio (`SA818S`) | `SA818_OPTIONAL_COMPONENT_REVIEW.md` | done | Add robust local power decoupling/bulk and RF ESD; keep extra supply filtering/audio conditioning as DNP options until bench data says needed. |
| Audio codec (`SGTL5000XNLA3`) | `SGTL5000_OPTIONAL_COMPONENT_REVIEW.md` | done | Core decoupling + VAG cap + audio AC coupling now; keep CPFLT as conditional by rail voltage and optional analog shaping as DNP. |
| Fuel gauge (`MAX17048G+T10`) | `MAX17048_OPTIONAL_COMPONENT_REVIEW.md` | done | Add mandatory 0.1uF bypass + clean CELL/VDD sense routing; tie QSTRT low; ALRT/I2C pullups included with optional alert flexibility. |
| Charger (`MCP73831T-2ACI/OT`) | `MCP73831_OPTIONAL_COMPONENT_REVIEW.md` | done | Add required >=4.7uF input/output caps, set RPROG baseline, include TVS and thermal/layout safeguards; keep extra bulk/STAT-MCU path as options. |
| MCU (`ESP32-S3-WROOM-1`) | `ESP32S3_OPTIONAL_COMPONENT_REVIEW.md` | done | Add robust EN/BOOT network and entry decoupling; keep auto-program and extra filtering as optional footprints; enforce antenna keepout/strap safety. |

## Locked decision: GPS backup battery

- Selected battery: `Panasonic BR-1225A/FAN` (3 V, 48 mAh, tab-mount primary cell).
- Required support parts:
  1. `D_GPS_BCKP_OR` Schottky diode (`BAT54` class), battery -> `V_BCKP`.
  2. `R_VBCKP_LINK` 0 ohm fallback link (`VCC -> V_BCKP`), DNP by default if battery is populated.
  3. `C_GPS_VCC_1uF` + `C_GPS_VCC_100nF` local decoupling at GPS `VCC`.

## Notes for schematic capture

- Use DNP footprints for optional filters from each review so rev01 can be tuned on bench without PCB respin.
- Record final population choices in this plan before routing freeze.

## Power architecture updates (current)

- USB input connector added: `USB_C_Receptacle_USB2.0_16P` (`J4`) with `5.1k` Rd on `CC1/CC2`.
- Main rail for high-current radio path is now `VSYS_MAIN`.
- SA818 supply preference updated to `VSYS_MAIN` (not from `+3V3` regulator output).
- Added `TPS63031DSK` (`U7`) as 3.3V regulator stage with required inductor and input/output capacitors.
- GPS backup battery updated to rechargeable option (`ML-1220/F1AN`) with trickle path (`R18` + `D7`) plus isolation diode to `V_BCKP`.

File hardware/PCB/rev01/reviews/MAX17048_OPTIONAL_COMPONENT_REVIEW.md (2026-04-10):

# MAX17048 Review 01: Optional/Support Components for Rev01

Scope: `MAX17048G+T10` only, focused on supply stability, sensing integrity, and alert/pullup behavior for schematic readiness.

Primary references:
- ADI MAX17048/MAX17049 datasheet (Rev. 7):
  - https://www.analog.com/media/en/technical-documentation/data-sheets/max17048-max17049.pdf
- ADI MAX17048 product page:
  - https://www.analog.com/en/products/max17048.html

---

## 1. Key datasheet constraints for external components

- `VDD` must be bypassed with `0.1 uF` to GND (explicit pin description requirement).
- `MAX17048` `VDD` and `CELL` both connect to the positive battery terminal in 1S usage.
- `CTG` must connect to ground.
- `QSTRT` should be tied to GND if not used.
- `ALRT` is open-drain active-low; if used, system pull-up is required.
- Datasheet states the system must provide pullups for `ALRT` (if used), `SDA`, and `SCL`.
- Exposed pad (TDFN) should be connected to GND.

---

## 2. Power/sense stability components

Populate now:
1. `C_FG_VDD_100nF` (X7R) very close to `VDD`.
2. Kelvin-style short routing from battery rail to `CELL`/`VDD` node (avoid noisy/high-current detours).
3. Solid local ground reference and exposed-pad grounding vias.

DNP options to place now:
1. `C_FG_BULK_1uF` footprint near `VDD`/`CELL` only if bench noise or droop appears.
2. Optional small series resistor footprint in alert line for edge damping if needed by EMC testing.

---

## 3. I2C and alert support network

Populate now:
1. `R_I2C_SDA_PU` and `R_I2C_SCL_PU` on the shared bus (typical 4.7k to 3.3V unless bus capacitance dictates otherwise).
2. `R_FG_ALRT_PU` (typical 10k to 3.3V) if `ALRT` is routed to MCU.
3. `QSTRT` tie-to-GND (direct or via 0R link).

DNP options:
1. Test-point on `ALRT` if not routed to MCU interrupt on rev01.
2. Optional 0R link to repurpose `QSTRT` to a reset pulse source in later testing.

Note:
- Pull-up resistor values above are implementation guidance inferred from standard I2C/open-drain practice; the datasheet mandates pullups but does not force exact resistor values.

---

## 4. Minimal practical BOM additions (MAX17048 section)

Populate now:
1. `C_FG_VDD_100nF`
2. `R_I2C_SDA_PU`
3. `R_I2C_SCL_PU`
4. `R_FG_ALRT_PU` (if `ALRT` used)
5. `QSTRT` GND tie component (`0R` or direct net tie)

Place as DNP/optional:
1. `C_FG_BULK_1uF`
2. Optional alert-series resistor footprint
3. Optional `ALRT` test-point if MCU interrupt is omitted

---

## 5. Recommended rev01 population

- Populate the mandatory `0.1uF` bypass and stable battery-sense routing now.
- Keep `QSTRT` tied low for rev01.
- Route `ALRT` to MCU with pull-up if you want low-SOC interrupt behavior from first bring-up; otherwise leave it on test pad with pull-up footprint.

Bench checks to decide optional population:
- I2C waveform quality at chosen pull-up values.
- Gauge reading stability during SA818 TX current bursts.
- Need for asynchronous low-battery interrupt handling (`ALRT`) in firmware behavior.

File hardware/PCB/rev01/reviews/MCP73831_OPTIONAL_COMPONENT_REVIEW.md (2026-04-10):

# MCP73831 Review 01: Optional/Support Components for Rev01

Scope: `MCP73831T-2ACI/OT` charger block only, focused on required external parts, power stability, and thermal robustness.

Primary references:
- Microchip MCP73831/2 datasheet (DS20001984H):
  - https://ww1.microchip.com/downloads/en/DeviceDoc/MCP73831-Family-Data-Sheet-DS20001984H.pdf
- Microchip MCP73831 product page:
  - https://www.microchip.com/en-us/product/mcp73831

---

## 1. Key datasheet constraints for external components

- `VDD` input should be bypassed to `VSS` with a minimum `4.7 uF`.
- `VBAT` output should be bypassed to `VSS` with a minimum `4.7 uF` for CV-loop stability, especially with no battery attached.
- Charge current is set by resistor from `PROG` to `VSS` with:
  - `IREG (mA) = 1000 / RPROG (kOhm)`.
- If `PROG` is left floating (or driven high), charging is disabled.
- Hot-pluggable inputs (USB/cable) require input overvoltage transient protection; datasheet recommends transorb from input to ground.
- Exposed thermal pad (if DFN package used) must connect to `VSS`; thermal vias improve dissipation.

---

## 2. Power stability and filtering network

Populate now:
1. `C_CHG_IN_4u7` (`>=4.7 uF`, X7R preferred) from `+5V_USB` to GND, near `VDD`.
2. `C_CHG_BAT_4u7` (`>=4.7 uF`, X7R preferred) from `VBAT` to GND, near `VBAT` pin.
3. `R_PROG` set for target charge current (start with `5.1 kOhm` for ~196 mA).
4. Short/wide copper on high-current charger paths (`VDD`, `VBAT`, GND return).

DNP options to place now:
1. Extra bulk on input (`10 uF`) if USB rail droop appears under cable/hub conditions.
2. Extra bulk on battery node (`10 uF`) if pack wiring inductance/no-load ringing appears.

---

## 3. Protection and status interface

Populate now:
1. `TVS_USB_IN` on charger input (transorb/TVS from `+5V_USB` to GND) due to hot-plug transients.
2. `R_LED_CHG` + status LED on `STAT` (if visual charging indicator desired in rev01).

DNP options:
1. `R_STAT_PU` footprint to route `STAT` to MCU input if firmware-side charge-state reading is desired later.
2. Input series impedance footprint (ferrite or small resistor) only if EMI/plug-in transients require tuning.

---

## 4. Thermal and layout recommendations

Populate/layout now:
1. Keep MCP73831 physically close to battery connector and `VBAT` copper to reduce drop.
2. Provide copper area around ground and power pins for heat spreading.
3. If migrating to DFN variant in future revision, include thermal-via strategy under EP.

Bench-triggered optional action:
- If charger enters thermal regulation too early under expected ambient, reduce programmed current (increase `R_PROG`) or improve copper heat spreading.

---

## 5. Minimal practical BOM additions (MCP73831 section)

Populate now:
1. `C_CHG_IN_4u7`
2. `C_CHG_BAT_4u7`
3. `R_PROG` (`5.1 kOhm` initial)
4. `TVS_USB_IN`
5. `R_LED_CHG` + `LED_CHG` (if status LED kept)

Place as DNP/optional:
1. `C_CHG_IN_BULK_10uF`
2. `C_CHG_BAT_BULK_10uF`
3. `R_STAT_PU` + MCU status routing option
4. Input tuning footprint (ferrite/resistor)

---

## 6. Recommended rev01 population

- Populate both required `>=4.7 uF` capacitors and keep `R_PROG = 5.1 kOhm` as first-build baseline.
- Populate input TVS for hot-plug protection.
- Keep optional bulk and STAT-to-MCU path as DNP footprints unless bench behavior requires them.

Bench checks to decide DNP population:
- Input rail transient behavior at plug/unplug events.
- Charge thermal throttling behavior at expected ambient.
- Need for MCU-aware charge-state telemetry beyond LED indication.

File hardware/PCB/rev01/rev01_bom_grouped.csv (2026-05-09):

Quantity | Value | Footprint | MPN | Manufacturer | DNP | References | Notes
1 | 0500LP15A500E | PAKT_Local_Fp:Johanson_0500LP15A500E_P8 | 0500LP15A500E | Johanson Technology | no | U9 | SA818 RF low-pass filter
1 | 0R_QSTRT_GND | Resistor_SMD:R_0603_1608Metric | RC0603JR-070RL | Yageo | no | R11 | Jumper 0603
1 | 10 | Resistor_SMD:R_0603_1608Metric | RC0603FR-0710RL | Yageo | no | R23 | 1% 0603
1 | 100k_EN_PULLUP | Resistor_SMD:R_0603_1608Metric | RC0603FR-07100KL | Yageo | no | R21 | 1% 0603
1 | 100k_VBUS_PD | Resistor_SMD:R_0603_1608Metric | RC0603FR-07100KL | Yageo | no | R19 | 1% 0603
1 | 100n | Capacitor_SMD:C_0603_1608Metric | CL10B104KB8NNNC | Samsung | no | C25 | 100nF 50V X7R 0603
1 | 100n_EN_DELAY | Capacitor_SMD:C_0603_1608Metric | CL10B104KB8NNNC | Samsung | no | C21 | 100nF 50V X7R 0603
1 | 100n_FG_VDD | Capacitor_SMD:C_0603_1608Metric | CL10B104KB8NNNC | Samsung | no | C18 | 100nF 50V X7R 0603
1 | 100n_GPS_RAIL | Capacitor_SMD:C_0603_1608Metric | CL10B104KB8NNNC | Samsung | no | C2 | 100nF 50V X7R 0603
1 | 100n_SA818 | Capacitor_SMD:C_0603_1608Metric | CL10B104KB8NNNC | Samsung | no | C8 | 100nF 50V X7R 0603
1 | 100n_SGTL_VAG | Capacitor_SMD:C_0603_1608Metric | CL10B104KB8NNNC | Samsung | no | C15 | 100nF 50V X7R 0603
1 | 100n_VDDA | Capacitor_SMD:C_0603_1608Metric | CL10B104KB8NNNC | Samsung | no | C12 | 100nF 50V X7R 0603
1 | 100n_VDDD | Capacitor_SMD:C_0603_1608Metric | CL10B104KB8NNNC | Samsung | no | C11 | 100nF 50V X7R 0603
1 | 100n_VDDIO | Capacitor_SMD:C_0603_1608Metric | CL10B104KB8NNNC | Samsung | no | C13 | 100nF 50V X7R 0603
2 | 100nf | Capacitor_SMD:C_0603_1608Metric | CL10B104KB8NNNC | Samsung | no | C22, C31 | 100nF 50V X7R 0603
1 | 100u_SA818 | Capacitor_SMD:C_1206_3216Metric | GRM31CR60J107ME39L | Murata | no | C10 | 100uF 6.3V X5R 1206 (verify derating)
1 | 10k_ALRT_PU | Resistor_SMD:R_0603_1608Metric | RC0603FR-0710KL | Yageo | no | R10 | 1% 0603
1 | 10k_EN_PULLUP | Resistor_SMD:R_0603_1608Metric | RC0603FR-0710KL | Yageo | no | R13 | 1% 0603
1 | 10k_IO0_PULLUP | Resistor_SMD:R_0603_1608Metric | RC0603FR-0710KL | Yageo | no | R14 | 1% 0603
1 | 10k_PD_PULLUP | Resistor_SMD:R_0603_1608Metric | RC0603FR-0710KL | Yageo | no | R8 | 1% 0603
1 | 10k_STAT_PU | Resistor_SMD:R_0603_1608Metric | RC0603FR-0710KL | Yageo | no | R12 | 1% 0603
1 | 10u_3V3_OUT | Capacitor_SMD:C_0805_2012Metric | CL21A106KPFNNNE | Samsung | no | C24 | 10uF 10V X5R 0805
1 | 10u_GPS_RAIL | Capacitor_SMD:C_0805_2012Metric | CL21A106KPFNNNE | Samsung | no | C1 | 10uF 10V X5R 0805
1 | 10u_SA818 | Capacitor_SMD:C_0805_2012Metric | CL21A106KPFNNNE | Samsung | no | C9 | 10uF 10V X5R 0805
1 | 10u_VHI_IN | Capacitor_SMD:C_0805_2012Metric | CL21A106KPFNNNE | Samsung | no | C23 | 10uF 10V X5R 0805
2 | 10uf | Capacitor_SMD:C_0805_2012Metric | CL21A106KPFNNNE | Samsung | no | C27, C28 | 10uF 10V X5R 0805
1 | 18650_LiIon | Battery:BatteryHolder_Keystone_1042_1x18650 | Keystone 1042 | Keystone | no | BT2 | 18650 holder
1 | 1k | Resistor_SMD:R_0603_1608Metric | RC0603FR-071KL | Yageo | no | R24 | 1% 0603
1 | 1k_RPROG | Resistor_SMD:R_0603_1608Metric | RC0603FR-071KL | Yageo | no | R5 | 1% 0603
1 | 1u_AF_RX_IN | Capacitor_SMD:C_0603_1608Metric | CL10A105KA8NNNC | Samsung | no | C16 | 1uF 10V X5R 0603
1 | 1u_AF_TX_OUT | Capacitor_SMD:C_0603_1608Metric | CL10A105KA8NNNC | Samsung | no | C17 | 1uF 10V X5R 0603
1 | 1uf | Capacitor_SMD:C_0805_2012Metric | CL10A105KA8NNNC | Samsung | no | C29 | 1uF 10V X5R 0603
1 | 1uF 16v | Capacitor_SMD:C_0603_1608Metric | CL10A105KA8NNNC | Samsung | no | C14 | 1uF 10V X5R 0603
1 | 2.2u_SGTL_POST | Capacitor_SMD:C_0603_1608Metric | CL10A225KO8NNNC | Samsung | no | C6 | 2.2uF 16V X5R 0603
1 | 2.2u_SGTL_PRE | Capacitor_SMD:C_0603_1608Metric | CL10A225KO8NNNC | Samsung | no | C3 | 2.2uF 16V X5R 0603
2 | 2.2uf | Capacitor_SMD:C_0603_1608Metric | CL10A225KO8NNNC | Samsung | no | C4, C5 | 2.2uF 16V X5R 0603
2 | 4.7k | Resistor_SMD:R_0603_1608Metric | RC0603FR-074K7L | Yageo | no | R3, R4 | 1% 0603
1 | 4.7k_GPS_BCKP_CHG | Resistor_SMD:R_0603_1608Metric | RC0603FR-074K7L | Yageo | no | R17 | 1% 0603
1 | 4.7u_CHG_BAT | Capacitor_SMD:C_0805_2012Metric | CL21A475KBQNNNE | Samsung | no | C20 | 4.7uF 16V X5R 0805
1 | 4.7u_CHG_IN | Capacitor_SMD:C_0805_2012Metric | CL21A475KBQNNNE | Samsung | no | C19 | 4.7uF 16V X5R 0805
1 | 4.7u_GPS_BULK | Capacitor_SMD:C_0805_2012Metric | CL21A475KBQNNNE | Samsung | no | C7 | 4.7uF 16V X5R 0805
1 | 47k_PTT_PULLUP | Resistor_SMD:R_0603_1608Metric | RC0603FR-0747KL | Yageo | no | R7 | 1% 0603
1 | 47pF | Capacitor_SMD:C_0402_1005Metric | CL05C470JB5NNNC | Samsung | no | C26 | 47pF C0G 0402
1 | 5.1k_CC1 | Resistor_SMD:R_0603_1608Metric | RC0603FR-075K1L | Yageo | no | R15 | 1% 0603
1 | 5.1k_CC2 | Resistor_SMD:R_0603_1608Metric | RC0603FR-075K1L | Yageo | no | R16 | 1% 0603
1 | AP2112K-3.3 | Package_TO_SOT_SMD:SOT-23-5 | AP2112K-3.3TRG1 | Diodes Inc. | no | U7 | 3.3V LDO
1 | BAT54 | Diode_SMD:D_SOD-323 | BAT54 | onsemi | no | D2 | Schottky
1 | BOOT | Button_Switch_SMD:SW_SPST_TL3342 | TL3342F160QG | E-Switch | no | SW2 | Boot button
1 | BR-1225A/FAN | Battery:BatteryHolder_Keystone_3000_1x12mm | Keystone 3000 | Keystone | no | BT1 | CR1225 holder
1 | CI160808-33NJ | Inductor_SMD:L_0603_1608Metric | CI160808-33NJ | Samsung Electro-Mechanics | no | L3 | 33nH RF inductor
1 | CONSMA006.062 | PAKT_Local_Fp:SMA_Amphenol_132134-14_Vertical_P5 | TBD | TBD | no | J2 | Review/Select
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

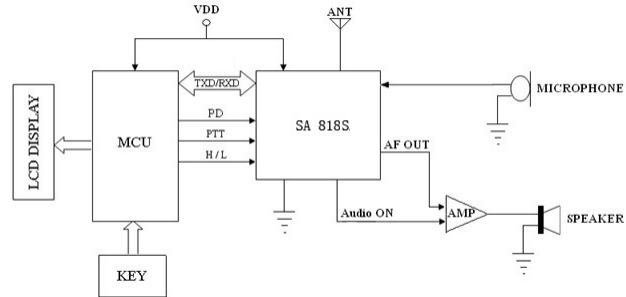
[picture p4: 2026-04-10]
docs/hardware/components/sa818/SA818S_typical_application_circuit.jpg

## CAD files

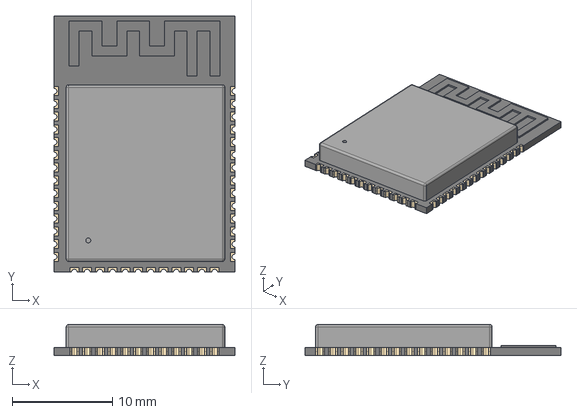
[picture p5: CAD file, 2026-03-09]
docs/hardware/components/esp32-s3/step/ESP32-S3-WROOM-1.step
18.0 x 25.5 x 3.10 mm

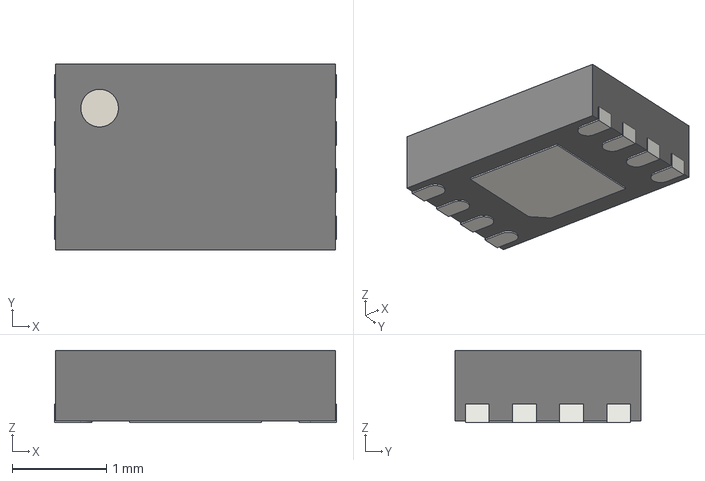
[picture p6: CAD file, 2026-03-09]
docs/hardware/components/max17043/step/DFN-8-1EP_3x2mm_P0.5mm_EP1.75x1.45mm.step
3.00 x 1.98 x 0.77 mm

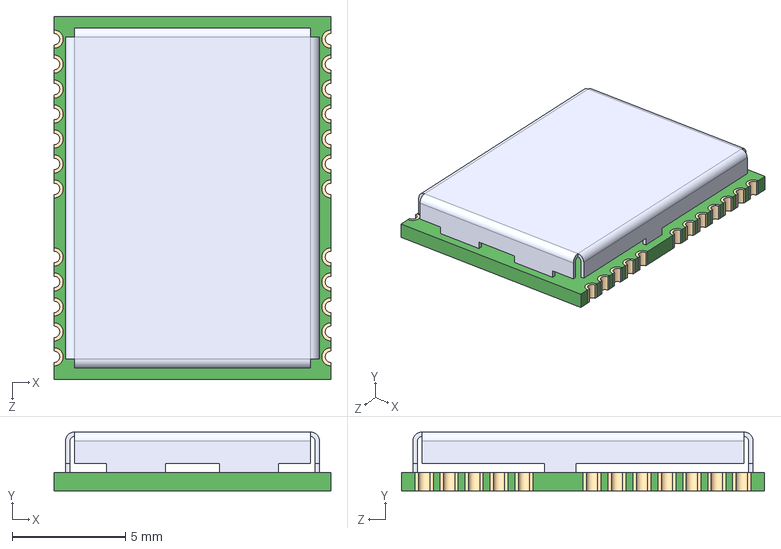
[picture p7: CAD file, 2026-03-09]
docs/hardware/components/neo-m8n/step/NEO-M9N-00B.step
12.2 x 2.60 x 16.0 mm

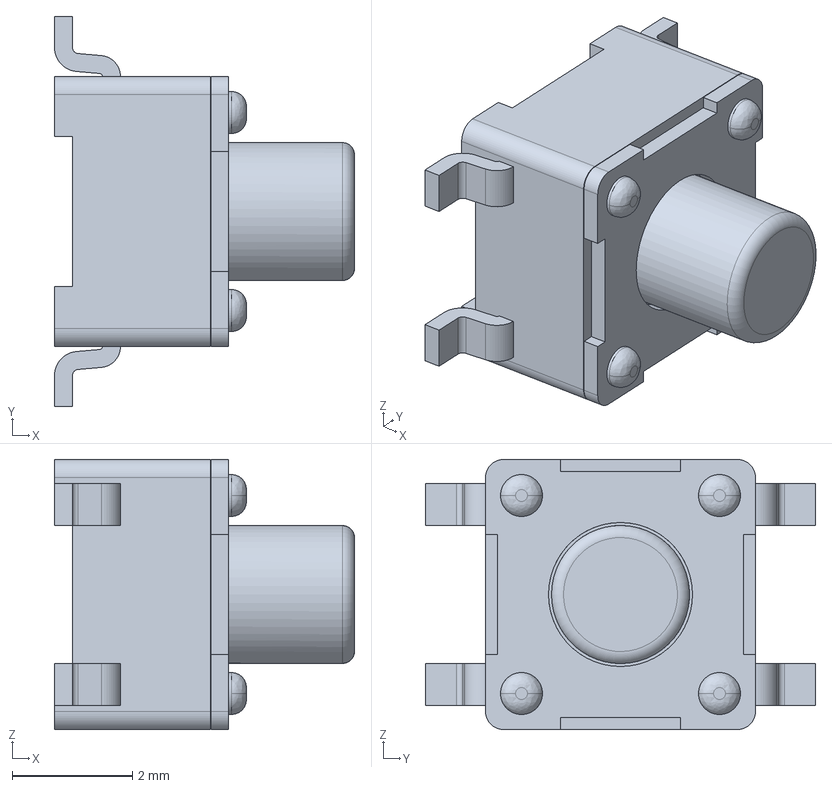
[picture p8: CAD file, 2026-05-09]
docs/hardware/components/PTS_647_SN50_SMTR2_LFS/PTS647SN50SMTR2LFS.stp
5.00 x 6.50 x 4.50 mm

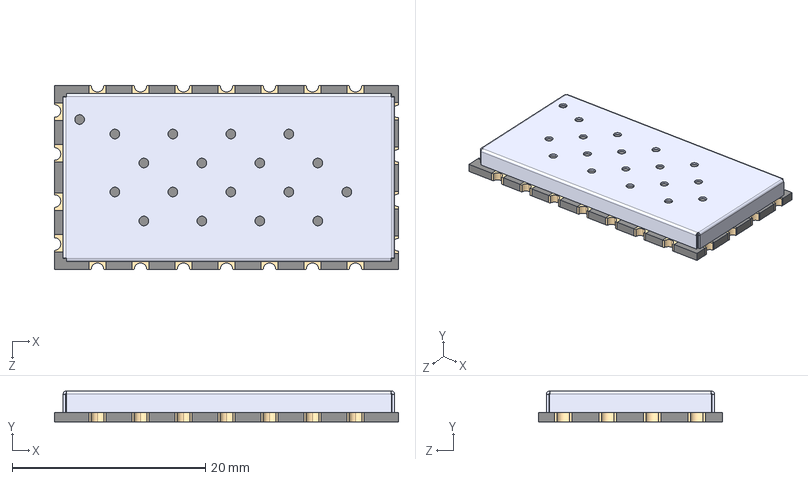
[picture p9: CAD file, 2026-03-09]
docs/hardware/components/sa818/step/SA818S.step
35.6 x 3.20 x 19.0 mm

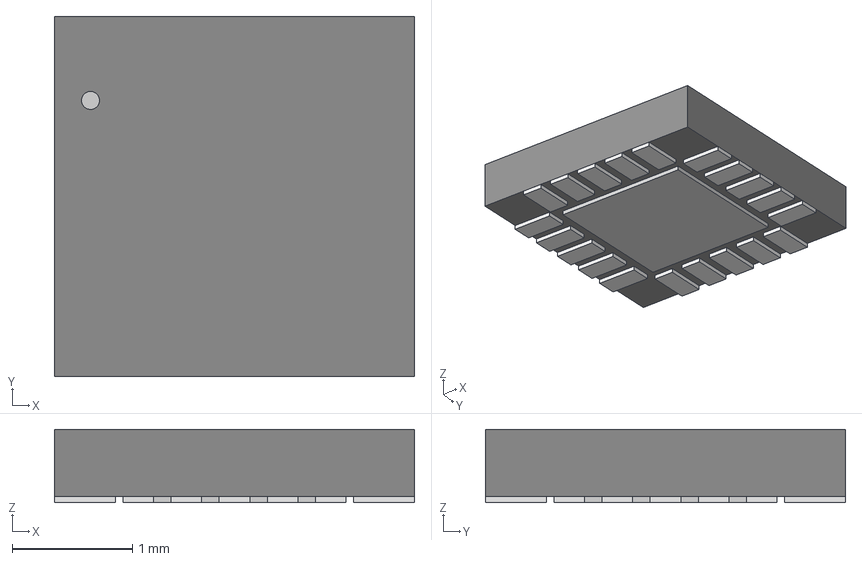
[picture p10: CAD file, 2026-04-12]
docs/hardware/components/sgtl5000/step/HUQFN20_SOT1628-1_NXP.step
3.00 x 3.00 x 0.612 mm

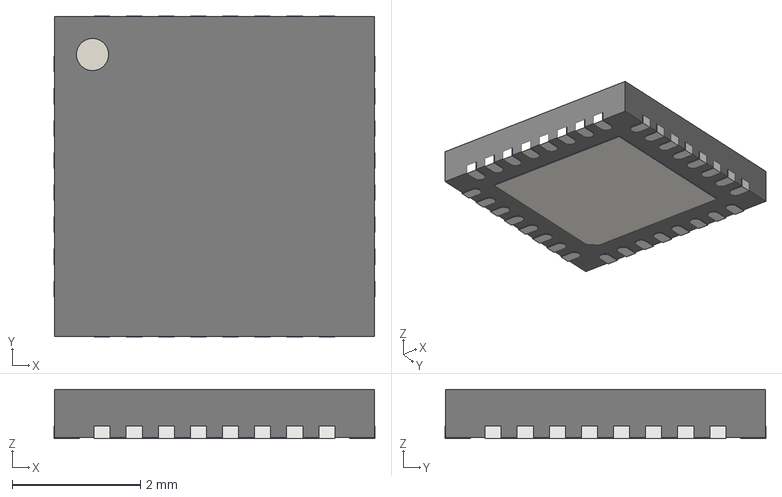
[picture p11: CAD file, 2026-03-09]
docs/hardware/components/wm8960/step/QFN-32-1EP_5x5mm_P0.5mm_EP3.45x3.45mm.step
5.00 x 5.00 x 0.77 mm

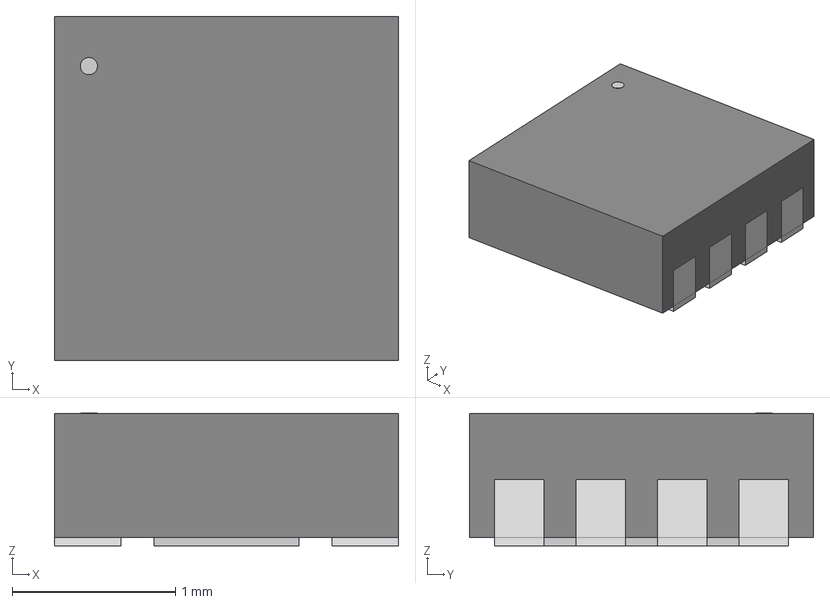
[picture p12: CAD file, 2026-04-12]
docs/hardware/components/max17048/MAX17048.step
2.11 x 2.11 x 0.815 mm

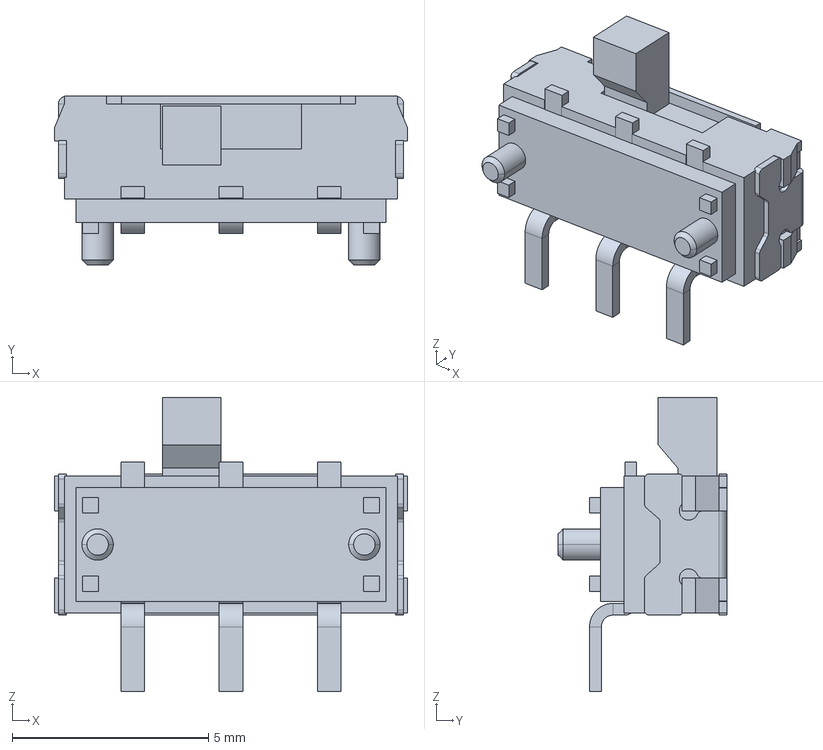
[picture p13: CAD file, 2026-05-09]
docs/hardware/components/Slide_switch/JS102011SAQN.step
9.00 x 4.30 x 7.50 mm

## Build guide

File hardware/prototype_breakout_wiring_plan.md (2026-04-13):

# Prototype Breakout Wiring Plan

Bench stack:
- Adafruit ESP32-S3 Feather family, `4 MB flash / 2 MB PSRAM` power-reference baseline
- Teensy Audio Adapter Rev D (`SGTL5000`)
- `SA818-V`
- u-blox `M9N`
- `1.3 inch IIC v2.0` OLED display with `SH1106` controller on the default I2C bus

Goal:
- Use one wiring plan for prototype bring-up and later PCB migration.
- Keep firmware pin mapping stable between proto and PCB.
- Keep the custom PCB power section aligned with the Adafruit ESP32-S3 Feather with `4MB Flash / 2MB PSRAM` bench behavior.
- Keep bench validation aligned with `docs/bench_bringup_checklist.md` and record values in `docs/bench_measured_values_template.md`.

## 1. Sources consulted
- `hardware/prototyping_wiring.md`
- `hardware/component_selection_rationale.md`
- `docs/aprs_mvp_docs/hardware/interfaces.md`
- `docs/hardware/components/esp32-s3/sources.md`
- `docs/hardware/components/sa818/sources.md`
- `docs/hardware/components/neo-m8n/sources.md`
- `docs/hardware/components/sgtl5000/sources.md`
- `docs/hardware/components/max17048/sources.md`
- `docs/hardware/components/mcp73831/sources.md`

Notes:
- This repo stores authoritative source links and the Adafruit Feather reference repos used for the battery subsystem.
- The electrical plan below follows the confirmed project net conventions and the bench-proven SGTL5000/SA818/GPS architecture already used in firmware.

## 2. Architecture wiring diagram

```mermaid
flowchart LR
    USB5V["USB 5V"] --> FEATHER["ESP32-S3 Feather"]
    BAT["Li-ion Battery"] --> FEATHER

    FEATHER -->|3V3 + GND| AUDIO["Teensy Audio Adapter Rev D\nSGTL5000"]
    FEATHER -->|UART + PTT + GND| SA["SA818-V"]
    FEATHER -->|I2C + optional UART fallback| GPS["u-blox M9N"]
    FEATHER -->|I2C SDA/SCL| OLED["1.3 inch OLED\nSH1106"]

    FEATHER -->|I2C SDA/SCL| AUDIO
    FEATHER -->|I2S BCLK/LRCLK/DOUT/DIN/MCLK| AUDIO

    AUDIO -->|AF_TX_COUPLED| SA
    SA -->|AF_RX_COUPLED| AUDIO
    SA --> ANT["Antenna / dummy load"]
```

## 3. Pin map

### 3.1 I2C control bus
| Feather GPIO | Net | Connects to |
|---|---|---|
| GPIO3 | `I2C_SDA` | SGTL5000 SDA, MAX17048 SDA, GPS SDA, SH1106 SDA |
| GPIO4 | `I2C_SCL` | SGTL5000 SCL, MAX17048 SCL, GPS SCL, SH1106 SCL |

Requirements:
- One pull-up set only on the bus.
- Bench bus members now include `SGTL5000 @ 0x0A`, `MAX17048 @ 0x36`, `u-blox M9N @ 0x42`, and the SH1106 display at the module's fitted address, typically `0x3C` and occasionally `0x3D`.
- The SGTL5000 appears on I2C only after `SYS_MCLK` is active.
- Confirm the SH1106 module does not add pull-ups strong enough to overload the existing bus pull-ups.

### 3.2 I2S audio bus
| Feather GPIO | Net | Teensy Audio / SGTL5000 signal |
|---|---|---|
| GPIO8 | `I2S_BCLK` | `BCLK / SCLK` |
| GPIO15 | `I2S_LRCLK` | `LRCLK / WS` |
| GPIO12 | `I2S_DOUT` | `DIN` |
| GPIO10 | `I2S_DIN` | `DOUT` |
| GPIO14 | `I2S_MCLK` | `MCLK / SYS_MCLK` |

Requirements:
- Keep wires short and grouped with ground.
- The earlier overlap concern is obsolete; the current bench profile already uses this mapping successfully alongside the radio control pins.

### 3.3 UARTs and control
| Function | Feather GPIO | Net | Remote signal |
|---|---|---|---|
| GPS TX | GPIO17 | `GPS_TXD` | GPS RXD |
| GPS RX | GPIO18 | `GPS_RXD` | GPS TXD |
| Radio TX | GPIO13 | `SA818_TXD` | SA818 RXD |
| Radio RX | GPIO9 | `SA818_RXD` | SA818 TXD |
| PTT | GPIO11 | `SA818_PTT_N` | SA818 PTT |

### 3.4 USB data protection path (current schematic)
| Segment | Net | Notes |
|---|---|---|
| USB-C connector side D+ | `DD+` | J4 A6/B6 to ESD input |
| USB-C connector side D- | `DD-` | J4 A7/B7 to ESD input |
| MCU side D+ | `USB_D_P` | ESD output to ESP32 USB_D+ |
| MCU side D- | `USB_D_N` | ESD output to ESP32 USB_D- |
| ESD IC | `U8 USBLC6-2P6` | Protects USB data pair |

## 4. Analog audio interconnect

| Source | Destination | Net | Prototype conditioning |
|---|---|---|---|
| `SGTL5000 LINE_OUT_L` | `SA818 AF_IN` | `AF_TX_COUPLED` | `1 uF` AC coupling + attenuation pad |
| `SA818 AF_OUT` | `SGTL5000 LINE_IN_L` | `AF_RX_COUPLED` | `1 uF` AC coupling + optional RC filter |

RF path now present in rev01 schematic:
- `SA818_ANT` from SA818 goes into `U9 (0500LP15A500E)` RF filter.
- Filter output `Net-(U9-OUT)` goes to SMA connector `J2`.
- GPS RF input uses `J5` plus L/C/R network (`L3`, `C26`, `R23`) tied to `VCCREF`.

Bench-proven usage:
- Headphone verification uses the PJRC 3.5 mm jack.
- Input verification uses the PJRC `LINE_IN` header.
- The project-appropriate SGTL5000 receive path for SA818 is `LINE_IN`, not `MIC_IN`.

## 5. Power and grounding guidance

### 5.1 Rail strategy
- For this prototype, battery management and charging are provided by the Feather board.
- For the custom PCB, replicate the Adafruit ESP32-S3 Feather with `4MB Flash / 2MB PSRAM` battery behavior so the bench behavior carries forward.
- Current rev01 schematic feeds SA818 through a dedicated branch:
  - `VBAT` -> `FB16` -> `+5V_SA818` -> `D15` -> `Net-(D15-K)` -> SA818 `VBAT`.
  - Local bulk caps on SA818 rail: `C8/C9/C10` and upstream `C33`.
- Keep the codec on a clean `3.3V` domain, optionally filtered for analog use.

### 5.2 Prototype decoupling guidance
- SA818 supply entry: `100 nF + 10 uF + 220-470 uF` bulk nearby.
- Add local `10 uF` on the SGTL5000 harness if leads are long.
- Add local decoupling at the GPS breakout if the breakout itself is sparse.

### 5.3 Grounding
- Use a star-like return concept in proto wiring.
- Run at least one dedicated ground wire alongside each signal bundle.

## 6. Open items before PCB capture
- Replace provisional AF attenuation and filter values with measured bench values.
- Record measured SA818 deviation and received AF levels from the working harness.
- Decide whether to keep net auto-names (`Net-(...)`) or replace with stable named nets before final routing review.
- Complete SGTL filtered-rail wiring using placed parts: `FB2` (`BLM18PG121SN1D`) with `C3/C4` on bead input side and `C6/C5` on bead output side; keep `C15` on `VAG`.
- Complete GPS filtered-rail wiring using placed parts: `FB1` (`BLM18PG121SN1D`) + `C1 10u` + `C2 100n` on bead output side near `U1`.
- Add a display status screen on the SH1106 that mirrors the bench system state: top bar for battery, GPS, and frequency; main area for received APRS traffic.

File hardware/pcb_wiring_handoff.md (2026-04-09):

# PCB Wiring Handoff

This is the schematic-entry wiring guide for the first KiCad pass.

## 1. Power architecture

### Main flow
1. USB-C `VBUS` feeds the charger input.
2. Charger output and battery connector meet at `VBAT_RAW`.
3. `VBAT_RAW` feeds:
   - the fuel gauge `MAX17048`
   - the main system power path / regulator input
   - the radio power branch
4. Main regulation produces `V_SYS_3V3`.
5. `V_AUD_3V3` is derived from `V_SYS_3V3` through filtering for the codec analog domain.

### Required power nets
- `VBUS`
- `VBAT_RAW`
- `V_SYS_3V3`
- `V_AUD_3V3`
- `V_RADIO`
- `GND`

### Battery section rules
- Follow the Adafruit ESP32-S3 Feather with `4MB Flash / 2MB PSRAM` bench-board battery behavior.
- Keep charger, battery connector, fuel gauge, and battery bulk capacitor physically close.
- Keep the SA818 high-current return away from codec analog return routing.

## 2. ESP32-S3 pin map to preserve

| GPIO | Net | Destination |
|---|---|---|
| GPIO3 | `I2C_SDA` | SGTL5000, MAX17048, GPS |
| GPIO4 | `I2C_SCL` | SGTL5000, MAX17048, GPS |
| GPIO8 | `I2S_BCLK` | SGTL5000 |
| GPIO15 | `I2S_WS` | SGTL5000 |
| GPIO12 | `I2S_DOUT` | SGTL5000 |
| GPIO10 | `I2S_DIN` | SGTL5000 |
| GPIO14 | `I2S_MCLK` | SGTL5000 |
| GPIO13 | `SA818_RX_CTRL` | SA818 RXD |
| GPIO9 | `SA818_TX_STAT` | SA818 TXD |
| GPIO11 | `SA818_PTT` | SA818 PTT |
| GPIO17 | `GPS_RX_CTRL` | GPS RXD fallback |
| GPIO18 | `GPS_TX_NMEA` | GPS TXD fallback |

## 3. Shared I2C bus

### Bus members
- `SGTL5000 @ 0x0A`
- `MAX17048 @ 0x36`
- `u-blox M9N @ 0x42`

### Rules
- Only one effective pull-up set on the bus.
- Keep the bus short and away from the SA818 RF area.
- Preserve shared-I2C GPS as the default path.

## 4. I2S audio bus

### Signals
- `I2S_BCLK`
- `I2S_WS`
- `I2S_DOUT`
- `I2S_DIN`
- `I2S_MCLK`

### Rules
- `I2S_MCLK` is mandatory for the SGTL5000.
- Keep the I2S group compact and referenced to a continuous ground plane.
- If edge quality becomes poor, reserve `22 Ohm` to `47 Ohm` series resistor footprints near the MCU.

## 5. Codec-to-radio analog path

### TX path
- `SGTL5000 LINE_OUT_L`
- AC-coupling capacitor
- DNP attenuation network
- `SA818 AF_IN`

### RX path
- `SA818 AF_OUT`
- AC-coupling capacitor
- optional DNP RC filter
- `SGTL5000 LINE_IN_L`

### Rules
- Keep analog routing short and away from RF and switching noise.
- Add accessible test points for `AF_TX_COUPLED` and `AF_RX_COUPLED`.
- Preserve the left-channel path that was proven on the bench.

## 6. SA818 interface

### Digital control
- `SA818_RX_CTRL`
- `SA818_TX_STAT`
- `SA818_PTT`

### Rules
- `SA818_PTT` is active low in the current bench baseline.
- Keep a DNP transistor stage available if direct GPIO drive needs conditioning.
- Add local `100 nF`, `10 uF`, and extra bulk capacitance at the SA818 supply entry.

## 7. GPS interface

### Default path
- Shared `I2C_SDA` / `I2C_SCL`

### Fallback path
- `GPS_TX_NMEA`
- `GPS_RX_CTRL`
- optional `GPS_PPS`

### Rules
- Keep GPS physically separated from the SA818 RF and power-burst area.
- Preserve UART fallback pads if space permits.

## 8. Bring-up-critical notes
1. Start `I2S/MCLK` before SGTL5000 I2C configuration.
2. Confirm `AT+DMOCONNECT` on the radio path before RF testing.
3. Measure TX deviation before locking the final `AF_TX` attenuation values.
4. Confirm no brownout during repeated TX bursts before PCB release.

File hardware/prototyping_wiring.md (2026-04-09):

# PCB Wiring Baseline

This document is the wiring baseline for the first KiCad schematic. It now
reflects the confirmed bench configuration rather than earlier exploratory
hardware plans.

For the physical breakout harness used on the bench, see:
- `hardware/prototype_breakout_wiring_plan.md`

## Scope and assumptions
- Target architecture: ESP32-S3 + SA818-V + SGTL5000 + u-blox M9N + MAX17048.
- Logic domain is `3.3V` unless a module explicitly requires otherwise.
- Battery charging and battery gauging should follow the Adafruit ESP32-S3 Feather with `4MB Flash / 2MB PSRAM` bench-board behavior.
- SA818 supply/current and AF levels still require final measured values before layout release.

## 1. Power tree

### Functional flow
1. USB-C `VBUS` -> `MCP73831T-2ACI/OT` charger input.
2. Charger `VBAT` -> single-cell Li-ion battery connector.
3. `VBAT_RAW` -> `MAX17048 CELL/VDD`.
4. `VBAT_RAW` -> system power path / regulator path.
5. Switched or regulated rails feed:
   - `V_RADIO` for the SA818 path
   - `V_SYS_3V3` for ESP32-S3 digital logic
   - `V_AUD_3V3` as the filtered codec analog rail

### Required rails
- `VBUS`
- `VBAT_RAW`
- `V_SYS_3V3`
- `V_AUD_3V3`
- `V_RADIO`
- `GND`

### Power integrity rules
- Place local bulk capacitance near the SA818 supply entry.
- Place `100 nF` decoupling at every IC power pin with the shortest possible loop.
- Add bulk capacitance near the ESP32-S3 supply entry.
- Keep SA818 TX current return out of the codec analog ground path.
- Include test points for `VBAT_RAW`, `V_SYS_3V3`, and `V_RADIO`.
- Keep charger, battery connector, and fuel gauge in the same battery-power zone.

## 2. Shared I2C control bus

| ESP32-S3 pin | Net | Devices |
|---|---|---|
| GPIO3 | `I2C_SDA` | SGTL5000, MAX17048, GPS |
| GPIO4 | `I2C_SCL` | SGTL5000, MAX17048, GPS |

Rules:
- Only one effective pull-up set on the bus.
- Keep the bus short and away from the SA818 RF area.
- Bench-verified devices on this bus are `SGTL5000 @ 0x0A`, `MAX17048 @ 0x36`, and `u-blox M9N @ 0x42`.
- The SGTL5000 does not answer cleanly until `SYS_MCLK` is running, so start `I2S/MCLK` first, then run codec I2C init.

## 3. I2S audio bus

| ESP32-S3 pin | Net | SGTL5000 pin |
|---|---|---|
| GPIO8 | `I2S_BCLK` | `SCLK` |
| GPIO15 | `I2S_WS` | `LRCLK` |
| GPIO12 | `I2S_DOUT` | `DIN` |
| GPIO10 | `I2S_DIN` | `DOUT` |
| GPIO14 | `I2S_MCLK` | `SYS_MCLK` |

Rules:
- `I2S_MCLK` is mandatory for the SGTL5000.
- Keep these traces short and referenced to a continuous ground plane.
- Reserve optional `22 Ohm` to `47 Ohm` series resistors at the MCU side if edge control is needed.
- The earlier pin-conflict draft is obsolete. The current bench profile uses `GPIO15` for `I2S_WS` and `GPIO13/GPIO9/GPIO11` for radio control without overlap.

## 4. UART and control links

| Function | ESP32-S3 pin | Net | Remote pin |
|---|---|---|---|
| GPS TX | GPIO17 | `GPS_RX_CTRL` | GPS RXD |
| GPS RX | GPIO18 | `GPS_TX_NMEA` | GPS TXD |
| Radio TX | GPIO13 | `SA818_RX_CTRL` | SA818 RXD |
| Radio RX | GPIO9 | `SA818_TX_STAT` | SA818 TXD |
| PTT | GPIO11 | `SA818_PTT` | SA818 PTT |

Optional:
- Route GPS PPS to a spare interrupt-capable GPIO if board space allows.

## 5. Analog audio interface

| Source | Destination | Net | Starting network |
|---|---|---|---|
| `SGTL5000 LINE_OUT_L` | SA818 `AF_IN` | `AF_TX_COUPLED` | AC coupling capacitor + DNP attenuation network |
| SA818 `AF_OUT` | `SGTL5000 LINE_IN_L` | `AF_RX_COUPLED` | AC coupling capacitor + optional DNP RC filter |

Rules:
- Keep the analog path short and away from RF and switching currents.
- Add test pads for `AF_TX_COUPLED` and `AF_RX_COUPLED`.
- Preserve the bench-proven left-channel path for the first PCB pass.

## 6. Battery and charging

- Follow the Adafruit ESP32-S3 Feather with `4MB Flash / 2MB PSRAM` battery behavior for:
  - `MCP73831T-2ACI/OT`
  - `MAX17048`
  - USB-C sink `CC` resistors
  - charger `STAT` LED path
- Keep `MAX17048 CELL` and `VDD` on `VBAT_RAW`.
- Tie `MAX17048 QSTRT` low unless a firmware-controlled quick-start function is intentionally added.
- Decide whether `MAX17048 !ALRT` goes to the ESP32 or to a test pad only.
- Provide charger status output to LED and optionally to an MCU-readable node if that adds value.

## 7. Required named nets

- Power: `VBUS`, `VBAT_RAW`, `V_SYS_3V3`, `V_AUD_3V3`, `V_RADIO`, `GND`
- Audio: `AF_TX_COUPLED`, `AF_RX_COUPLED`
- Radio control: `SA818_PTT`, `SA818_RX_CTRL`, `SA818_TX_STAT`
- GPS: `GPS_TX_NMEA`, `GPS_RX_CTRL`, optional `GPS_PPS`
- I2C: `I2C_SDA`, `I2C_SCL`
- I2S: `I2S_BCLK`, `I2S_WS`, `I2S_DOUT`, `I2S_DIN`, `I2S_MCLK`

## 8. Pre-PCB validation checklist
1. Confirm SA818 supply voltage/current limits on the exact purchased module.
2. Confirm SA818 PTT polarity and UART electrical levels.
3. Measure the required `AF_TX` level for proper deviation.
4. Measure `AF_RX` level/noise floor into the codec path.
5. Verify no ESP32 resets during repeated TX bursts.
6. Verify GPS lock and shared-I2C stability while TX/RX is active.
7. Verify I2C bus rise time with SGTL5000, MAX17048, and GPS attached.
8. Verify BLE operation while the RX audio pipeline is active.
9. Verify SGTL5000 `SYS_MCLK` frequency/ratio configuration is stable at the selected sample rate.
10. Keep the firmware bring-up order as: power bus -> enable QT/STEMMA pull-up path -> start I2S/MCLK -> init SGTL5000 over I2C.
11. Preserve these working SGTL5000 setup assumptions in firmware unless bench data disproves them:
    `CHIP_I2S_CTRL=0x0030`, `CHIP_SSS_CTRL=0x0010`, `CHIP_ANA_CTRL=0x0006`, `CHIP_SHORT_CTRL=0x4446`, final `CHIP_ANA_POWER=0x40FF`
12. Confirm headphone output with the bench audio test before wiring SA818.
13. Validate SA818 UART on `GPIO13/GPIO9` with `AT+DMOCONNECT` before RF tests.
14. Run only short, supervised TX-audio tests until deviation is measured and tuned.

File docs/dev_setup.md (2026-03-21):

# PAKT Developer Setup Guide

Covers: host unit tests, Python desktop tests, and ESP-IDF firmware build.
No hardware required for the first three sections.

This file is the practical setup companion to the canonical spec/status tree in
`docs/aprs_mvp_docs/`. For protocol or implementation-status questions, prefer:
- `docs/aprs_mvp_docs/docs/05_ble_gatt_spec.md`
- `docs/aprs_mvp_docs/docs/16_kiss_over_ble_spec.md`
- `docs/aprs_mvp_docs/agent_bootstrap/gate_pass_matrix.md`
- `docs/aprs_mvp_docs/agent_bootstrap/audit.md`

Generated build directory note:
- `firmware/build_*` is the intended location for firmware and host-test build outputs.
- Repo-root `build_feather_s3/` is also an ESP-IDF-generated build tree for the same `firmware/` project, but it is a separate output directory rather than a second source tree.

---

## 1. Prerequisites

Important toolchain split:

- Firmware target (`firmware/`) is built through ESP-IDF using `idf.py`.
- Raw CMake is not the direct developer entrypoint for firmware builds.
- Raw CMake is used for the host-only test target in `firmware/test_host`.

### 1.1 Host unit tests (C++, CMake)

| Tool | Minimum version | Notes |
|---|---|---|
| CMake | 3.16 | FetchContent used for doctest |
| C++ compiler | GCC 10 / Clang 12 / MSVC 2019 (v16.11) | C++17 required |
| Ninja (optional) | any | faster builds |
| Git | any | doctest fetched via FetchContent |

### 1.2 Python desktop tests

| Tool | Minimum version |
|---|---|
| Python | 3.10 |
| pip | any |

### 1.3 ESP-IDF firmware build (no hardware needed)

| Tool | Version | Notes |
|---|---|---|
| ESP-IDF | v5.3.2 | exact version used in CI; other v5.x may work |
| idf.py | bundled with ESP-IDF | |

Install ESP-IDF following the official guide for your OS. After install, `idf.py` must be on PATH or activated via `. $IDF_PATH/export.sh`.

---

## 2. Host unit tests

```bash
# From repo root:
cmake -S firmware/test_host -B build/test_host -DCMAKE_BUILD_TYPE=Release
cmake --build build/test_host
./build/test_host/pakt_tests --reporters=console --no-intro
```

On Windows (MSVC or MinGW):
```powershell
cmake -S firmware/test_host -B build/test_host -DCMAKE_BUILD_TYPE=Release
cmake --build build/test_host --config Release
.\build\test_host\Release\pakt_tests.exe --reporters=console --no-intro
```

Run a single test file's tests by filtering:
```bash
./build/test_host/pakt_tests -tc="GPRMC*" --reporters=console
```

Expected output: `[doctest] test cases: 200+ | 200+ passed | 0 failed`

---

## 3. Python desktop tests

```bash
cd app/desktop_test
python -m venv .venv
# Linux/macOS:
source .venv/bin/activate
# Windows:
.venv\Scripts\activate

pip install -r requirements.txt
pytest -v
```

Expected output: all tests pass. BLE transport tests use mocks (no hardware needed).

---

## 4. Firmware build (ESP-IDF, no hardware)

Use ESP-IDF's `idf.py` for firmware builds. Although ESP-IDF uses CMake under
the hood, developers and agents should treat `idf.py` as the supported command
surface for the firmware target.

```bash
# Activate ESP-IDF environment (adjust path to your install):
. ~/esp/esp-idf/export.sh        # Linux/macOS
# or:
%USERPROFILE%\esp\esp-idf\export.bat   # Windows CMD

cd firmware
idf.py set-target esp32s3
idf.py build
```

Build output: `firmware/build/pakt.bin`, `pakt.elf`, `pakt.map`.
No device connection is needed for a build-only check.

### 4.1 Bench/debug stage selection

The prototype firmware now supports build-time selection of which blocking bench
stages run at boot. Edit:

- `firmware/main/bench_profile_config.h`

This file controls:

- top-level benches: `audio_bench`, `sa818_bench`, `aprs_bench`
- APRS sub-stages: Stage 0 loopback, Stage A TX burst, Stage B RX gain sweep,
  PCM snapshot logging, and Stage C full RX recorder/export
- audio sample-rate selection for the codec/I2S/modem pipeline:
  - `8000` for the original APRS bench rate
  - `16000` for higher-fidelity debug and capture runs
- Stage C ADC gain step for targeted capture runs
- RX sample-path controls for codec/I2S debugging:
  - selected RX input view: left, right, average, or stronger channel
  - optional stereo-slot swap
  - optional sample byte swap
  - optional firmware DC blocker before recorder/demod
  - SGTL5000 register readback logging after init

Recommended workflow for focused debugging:

1. Edit `firmware/main/bench_profile_config.h`
2. Disable benches you do not want for this session
3. Rebuild with `idf.py build`
4. Flash and monitor the targeted run only

This is the preferred path for prototype debug work instead of commenting bench
code in `main.cpp`.

---

## 5. CI pipeline (reference)

The GitHub Actions CI runs three jobs on every push/PR to `main`:

| Job | Command | What it checks |
|-----|---|---|
| `firmware-build` | `idf.py build` | Full ESP-IDF build, no warnings in touched modules |
| `host-tests` | CMake + CTest | 200+ C++ unit tests (ax25, aprs, modem, BLE chunker, TxScheduler, telemetry, GPS, payload validator, TX integration, PTT watchdog/PttController, config store, SA818 driver) |
| `app-tests` | `pytest` | Python tests for chunker, BLE transport FSM, config store, message tracker, telemetry parser |

See `.github/workflows/ci.yml` for full configuration.

---

## 6. Component dependency map

```
main
|- aprs_fsm         <- TxScheduler, TxResultEncoder, AprsTaskContext
|  \- payload_codec <- PayloadValidator, DeviceConfigStore (+ config_to_json)
|- safety_watchdog  <- PttWatchdog, PttController
|- radio_sa818      <- ISa818Transport, Sa818CommandFormatter, Sa818ResponseParser, Sa818Radio
|- ble_services     <- BleServer, BleChunker
|- gps              <- NmeaParser
|- telemetry        <- GpsTelem, BattTelem, SysTelem
|- capability       <- DeviceCapabilities
|- aprs             <- Aprs frame encoder/decoder
|  \- ax25         <- AX.25 framing
\- modem           <- AfskModulator, AfskDemodulator
```

`payload_codec`, `safety_watchdog`, and `radio_sa818` have no component dependencies (pure C++).
All others depend on `payload_codec` transitively through `aprs_fsm`.

---

## 7. Useful build targets

```bash
# Run only GPS parser tests:
./build/test_host/pakt_tests -tc="GPRMC*" -tc="GPGGA*" -tc="feed*"

# Run only payload validator tests (42 tests):
./build/test_host/pakt_tests -tc="config*" -tc="tx_request*"

# Run only TX integration tests (26 tests):
./build/test_host/pakt_tests -tc="TxResultEncoder*" -tc="AprsTaskContext*"

# Python: run only chunker tests:
pytest app/desktop_test/test_chunker.py -v

# Python: run all tests with verbose output:
pytest app/desktop_test/ -v

# Python: run only messaging tracker tests:
pytest app/desktop_test/test_messaging.py -v

# Run only PTT watchdog + PttController tests (21 tests):
./build/test_host/pakt_tests -tc="PttWatchdog*" -tc="PttController*" --reporters=console

# Run only config store tests (7 tests, includes config_to_json):
./build/test_host/pakt_tests -tc="DeviceConfigStore*" --reporters=console

# Run only SA818 driver tests (18 tests):
./build/test_host/pakt_tests -tc="Sa818*" --reporters=console
```

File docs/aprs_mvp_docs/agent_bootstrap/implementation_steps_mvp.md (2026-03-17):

# MVP Implementation Steps (Agent Sequence)

Status legend: `todo | in_progress | blocked | done`
Evidence legend: `code + tests + gate summary + residual risks`

## Step 0 - Project readiness
- IDs: PM-001, PM-002, FW-001
- Status: done
- Exit: reproducible build confirmed; board detected; toolchain version pinned; CI baseline passing
- Evidence: firmware/CMakeLists.txt (ESP-IDF v5.3.2, target esp32s3); sdkconfig.defaults with pinned BLE/FreeRTOS config; .github/workflows/ci.yml with firmware-build and host-tests jobs
- Connected-board add-on: command profile selected + first successful flash/boot log capture

## Step 1 - Hardware control baseline
- IDs: HW-002, FW-002, FW-003, FW-016
- Status: in_progress
- Exit: SA818 driver works on bench; PTT safe-off verified
- Evidence (FW-002 done): IAudioIO/IRadioControl/IPacketLink/IStorage interfaces in firmware/components/pakt_hal/include/pakt/; mocks in mock/; 40 host unit tests passing in firmware/test_host/. FW-003 (SA818 driver) software-complete (see below).
- Evidence (FW-003 done — software): Sa818Radio component (firmware/components/radio_sa818/): ISa818Transport (injectable UART abstraction), Sa818CommandFormatter (connect/set_group AT builders), Sa818ResponseParser (Ok/Error/Unknown classifier), Sa818Radio (IRadioControl impl; idempotent set_freq; force_ptt_off on any UART failure). Sa818UartTransport (firmware/main/Sa818UartTransport.h): ESP-IDF UART1 concrete transport, excluded from host tests. radio_task wired: GPIO11 configured as PTT output (default HIGH=off), direct-GPIO safe-off callback registered before init(), uart_driver_install + SA818 init + APRS freq set, safe-off callback upgraded to radio.ptt(false) after successful init. 18 host unit tests in test_host/test_sa818.cpp covering formatter, parser, and Sa818Radio state machine (PTT before/after init, init success/failure/timeout, set_freq idempotency, set_freq failure, ptt(false) in error state).
- Evidence (FW-016 done — software): PttWatchdog + PttController components (firmware/components/safety_watchdog/): pure C++ IDLE→ARMED→TRIGGERED FSM; 10 s default timeout; safe_fn fires exactly once via compare_exchange_strong; heartbeat() recovery path; PttController provides settable safe-off hook (ptt_register_safe_off / ptt_safe_off / ptt_is_registered). 21 host unit tests in test_host/test_ptt_watchdog.cpp covering all state transitions, wrap-around arithmetic, force_safe idempotency, PttController no-op/registered/watchdog-integration/state-transition cases, and RadioControlMock integration. watchdog_task wired into main.cpp at priority 6 (ticks every 500 ms); aprs_task calls heartbeat() each loop iteration; safe_fn calls pakt::ptt_safe_off(). radio_task now registers direct-GPIO safe-off before SA818 init and upgrades to `radio.ptt(false)` after successful init.
- Residual risk: FW-003 SA818 electrical validation (UART handshake, PTT polarity, audio deviation) blocked until prototype hardware is available (bench checklist step 5). FW-016 hardware portion (hardware PTT fault injection) blocked pending EVT prototype. Sa818Radio software integration is complete.

## Step 2 - Audio pipeline baseline (SGTL5000)
- IDs: FW-004, QA-002
- Status: in_progress
- Exit: stable I2S read/write at target sample rate without sustained underrun; SGTL5000 `SYS_MCLK` validation complete
- Evidence (software done): `audio_pipeline_run()` in `firmware/main/main.cpp` now performs SGTL5000 I2C init, full-duplex I2S channel setup, RX-side `AfskDemodulator` processing into `g_rx_ax25_queue`, and TX-side publication of `g_i2s_tx_chan` for shared `afsk_tx_frame()` use. Clocking was corrected to an 8 kHz plan using `I2S_MCLK_MULTIPLE_1024` and SGTL5000 `SYS_FS = 32 kHz, RATE_MODE = ÷4`, giving `8.192 MHz` MCLK. Runtime bring-up remains hardware-gated.
- Residual risk: verify actual MCLK/BCLK/WS on the bench, confirm SGTL5000 lock, check underrun/overrun behavior, and calibrate ADC/DAC gain on hardware.

## Step 3 - APRS modem core
- IDs: FW-006, FW-007, FW-008, FW-009
- Status: in_progress
- Exit: known-vector encode/decode passes; reference receiver decodes TX frames
- Evidence (software done): AX.25 codec (components/ax25/), APRS helpers (components/aprs/), AfskModulator + AfskDemodulator (components/modem/); full encode->modulate->demodulate->decode round-trip test suite in test_host/. Reference receiver TX decode blocked until hardware is available.
- Residual risk: Bell 202 demodulator uses transition-tracking sync (no PLL); real-world timing and level calibration will need tuning on hardware. Audio deviation calibration is a known top risk.

## Step 4 - BLE services and security
- IDs: FW-011, FW-012, INT-002
- Status: in_progress
- Exit: full GATT endpoints + encrypted/bonded write policy validated
- Evidence (software done): ble_services component (components/ble_services/): BleChunker (pure C++ splitter/reassembler), BleServer (NimBLE GATT server with all 9 characteristics across 3 services, encrypted+bonded write enforcement, rate-limited notify). BleChunker host unit tests in test_host/test_ble_chunker.cpp. BleServer requires hardware for full GATT/security validation.
- Residual risk: BleServer encrypted+bonded write rejection and GATT endpoint validation blocked until prototype hardware is available. Stub handlers in main.cpp ble_task will be replaced when APRS logic is wired in (Steps 6-7).

## Step 4b - GPS/NMEA parser (FW-005)
- IDs: FW-005
- Status: done (software; hardware integration pending)
- Exit: GPRMC/GPGGA parsed correctly; stale-fix management operational; GpsTelem populated
- Evidence: firmware/components/gps/ — NmeaParser (feed() byte-stream + process() batch interface, GPRMC/GNRMC + GPGGA/GNGGA, checksum verification, decimal-degree conversion, Unix timestamp from date+time, stale-fix mark_stale/reset). 37 host unit tests in test_host/test_nmea_parser.cpp. gps_task in main.cpp updated to use NmeaParser with 5 s stale-fix timeout and 1 Hz BLE notify publish (UART read stubbed pending hardware).
- Residual risk: UART byte-stream path (NEO-M8N on board's GPS port) blocked until hardware; timing/level validated on hardware. gps_task UART stub must be replaced before real GPS data flows.

## Step 5 - Desktop BLE test app baseline
- IDs: APP-000
- Status: in_progress
- Exit: desktop app can connect/pair/reconnect, exercise core GATT paths, and export debug logs
- Evidence (software done): app/desktop_test/: chunker.py (client-side BleChunker mirror with split + Reassembler), pakt_client.py (bleak async GATT client with transparent chunked writes and notify reassembly), main.py (interactive CLI: scan, connect, DIS read, config read/write, command, TX request, 30 s notify listen, timestamped log export). test_chunker.py (25 pytest tests). CI app-tests job added.
- Residual risk: full GATT validation (pair, write-rejection when unbonded, RX stream, TX result, telemetry, reconnect matrix) blocked until prototype hardware is available.

## Step 6 - App connectivity and config
- IDs: APP-001, APP-002, APP-003, APP-008
- Status: in_progress
- Exit: stable pair/connect/reconnect + config R/W
- Evidence (software done): app/desktop_test/: transport.py (BleTransport FSM: IDLE/SCANNING/CONNECTING/CONNECTED/RECONNECTING/ERROR, bounded reconnect: 3 attempts x 1 s, per architecture contract G, on_reconnected callback re-subscribes GATT notify), config_store.py (local JSON cache with save/load/validate/diff), pakt_client.py refactored to use BleTransport + ConfigStore (auto-cache on read, auth-error classification via is_auth_error()), main.py updated with state display, config diff preview, offline config view, and pairing guidance on auth errors. test_app.py: 45 pytest tests covering ConfigStore, BleTransport FSM, reconnect callbacks, and is_auth_error().
- Residual risk: reconnect matrix and config persistence checks against real hardware blocked until prototype available.

## Step 7 - Messaging end-to-end
- IDs: FW-010, APP-006
- Status: in_progress
- Exit: send->pending->ack/timeout flow works reliably
- Evidence (software done): TxMessage + TxScheduler (components/aprs_fsm/): static 8-slot queue, 5-retry policy at 20 s intervals, enqueue/tick/on_ack_received/cancel API, result callback fires on ACKED/TIMED_OUT/CANCELLED. 26 host unit tests in test_host/test_tx_scheduler.cpp. Python MessageTracker (app/desktop_test/message_tracker.py): MsgState FSM, on_sent/on_tx_result/cancel/pending/recent/clear_resolved API; 37 pytest tests in test_messaging.py. pakt_client.py routes tx_result notify into MessageTracker; main.py adds [9] message queue view. CI app-tests updated to include test_messaging.py.
- Evidence (DeviceConfigStore + NvsStorage done — software): DeviceConfigStore (firmware/components/payload_codec/include/pakt/DeviceConfigStore.h): header-only class; set_storage(IStorage*) attaches backend after construction; apply(ConfigFields&) updates in-memory DeviceConfig and calls storage_->save() if backend set; load() populates from storage on startup; in-memory always updated regardless of persist result. NvsStorage (firmware/main/NvsStorage.h): concrete IStorage using ESP-IDF NVS blob API (namespace "pakt_cfg", key "device_config", schema_version guard, nvs_commit() on every save). app_main() NVS boot path: nvs_flash_init() → erase+reinit if needed → set_storage + load() with explicit log for loaded/defaults/failure outcomes; tasks created after config is ready. Wired in main.cpp on_config_write: apply() called after PayloadValidator acceptance; logs persist success or in-memory-only warning. Wired on_config_read to `DeviceConfigStore::config_to_json(g_device_config.config(), ...)`. 7 host tests in test_host/test_config_store.cpp covering in-memory update, storage backend save, persist failure, load-without-storage defaults, and config_to_json behavior.
- Residual risk: full send→ack/timeout flow requires hardware (firmware TxScheduler wired into APRS task, radio TX, and ack detection). BLE TX result notify format must be confirmed against firmware implementation when hardware is available. NVS persistence for DeviceConfigStore requires hardware (flash + ESP-IDF NVS driver) — NvsStorage code is complete but untested on-device.

## Step 8 - Telemetry and operator UX
- IDs: APP-004, APP-005, FW-015
- Status: in_progress
- Exit: status + RX stream + diagnostics visible and exportable
- Evidence (software done): Telemetry component (components/telemetry/): DeviceStatus, GpsTelem, PowerTelem, SysTelem structs + compact JSON serialisers (to_json, ≤ 240 B/frame). 18 host unit tests in test_host/test_telemetry.cpp. Python telemetry.py: typed parsers + summary formatters for all 4 channels, parse_notify dispatcher. diagnostics.py: DiagnosticsStore — 300-sample ring per channel, running stats (min/max/avg), export_dict/export_json. 40 pytest tests in test_telemetry_app.py. pakt_client.py routes telemetry notifies into DiagnosticsStore; rx_packet frames into add_rx_frame. main.py adds [T] telemetry snapshot and [X] export diagnostics report. CI app-tests updated.
- Residual risk: live telemetry stream, GPS fix, power readings, and system stats require prototype hardware. RX frame delivery via rx_packet notify requires APRS decode pipeline wired in firmware.

## Step 9 - MVP validation gates
- IDs: QA-003, QA-004, QA-006, DOC-001, DOC-003
- Status: in_progress
- Exit: all MVP gates pass (see `qa_gates.md`)
- Evidence (software done): gate_pass_matrix.md — full G0–G4 assessment with pass/partial/blocked per check item and 8-item residual risk table with mitigation owners. CI regression suite (QA-006) operational: firmware-build + host-tests + app-tests on every push/PR. DOC-001: docs/13_quickstart_guide.md — 9-step first-use guide covering installation, pairing, config, TX, telemetry, and log export. DOC-003: docs/14_pairing_security_policy.md — LE SC security model, AUTH_ERR resolution procedure, bond-reset flow, multi-client notes, regulatory notes. QA-003 (RF functional test) and QA-004 (BLE endurance matrix) blocked until hardware available.
- Residual risk: G1 (functional), G3 hardware portion (bonded-write rejection, PTT safe-off), and G4 blocked pending EVT prototype. PTT safe-off under fault (G3) is a P0 blocker for any TX-capable field use.

## Step 10 - MVP KISS interop
- IDs: INT-001, INT-003, INT-004, FW-018, APP-013, DOC-004
- Status: in_progress
- Exit: capability negotiation live, KISS-over-BLE implemented, and at least one reference KISS client or bridge validated
- Evidence (software done): DeviceCapabilities component (components/capability/): feature bitmask, JSON serialiser, mvp_defaults(), has() API; 16 host unit tests in test_capability.cpp. kDeviceCapabilities UUID (0xA0040000) added to BleUuids.h and now wired into BleServer GATT table as a read-only characteristic (2026-03-14): BleServer::Handlers gained on_caps_read callback, aprs_chars[] gained a BLE_GATT_CHR_F_READ entry for uuid_dev_caps, aprs_access_cb handles the read and falls back to `{}` if the handler is not set, main.cpp ble_task wires on_caps_read to DeviceCapabilities::mvp_defaults().to_json(). Python capability.py: DeviceCapabilities parser (protocol, fw_ver, hw_rev, features frozenset), CapabilityNegotiator (read on connect, assumed_mvp() fallback, feature flag API, on_caps callback with CAPS_WARN for missing MVP features, reset on disconnect); 28 pytest tests in test_capability.py. pakt_client.py reads capabilities on connect, exposes capabilities property, logs CAPS/CAPS_WARN.
- Evidence (software done 2026-03-16): KISS-over-BLE software path is now substantially implemented end-to-end. `KissFramer` is implemented and host-tested; KISS UUIDs and GATT service are present in `BleServer`; `handlers.on_kiss_tx` decodes inbound KISS and enqueues raw AX.25 into `AprsTaskContext`; the shared TX path uses `afsk_tx_frame()`; `aprs_task` drains decoded AX.25 frames from `g_rx_ax25_queue` and forwards them to both native `rx_packet` and KISS RX notifications; `notify_kiss_rx()` applies INT-002 chunking; desktop `kiss_bridge.py` handles multi-chunk RX reassembly. Capability negotiation exposes `kiss_ble`, and the Python side has KISS capability and bridge coverage.
- Remaining implementation required (hardware-gated):
  - Validate KISS TX and KISS RX with physical BLE + RF/audio hardware
  - Validate with third-party KISS client on hardware (APRSdroid, Direwolf, YAAC, Xastir)
  - Update DOC-004 interop matrix with real evidence
- Primary docs: `docs/16_kiss_over_ble_spec.md`, `docs/17_mvp_gap_analysis.md`, `docs/15_interoperability_matrix.md`.
- Residual risk: CapabilityNegotiator fallback to assumed_mvp() will be exercised until hardware validates the actual BLE read. KISS is now MVP-critical rather than deferred. Third-party client interoperability and BLE/RF behavior remain hardware-gated.

## Step 11 - HF discovery track
- IDs: HF-001..HF-011
- Status: todo
- Exit: go/no-go decision record for production HF audio bridge
- Evidence: latency/jitter/battery measurements and explicit decision rationale
- Note: This is a discovery track that can run alongside Steps 9-10 if a second agent is available, but must not block MVP milestone closure. A single agent should complete Steps 0-10 before starting Step 11.

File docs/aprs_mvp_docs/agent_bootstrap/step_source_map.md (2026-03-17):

# Step Source Map

Use this map to open the minimum additional documents for each step.

## Step 0
- `../docs/12_implementation_backlog.md`
- `device_loop.md` (if hardware connected)

## Step 1
- `../hardware/interfaces.md`
- `../docs/03_system_architecture.md`
- `device_loop.md` (if hardware connected)

## Step 2
- `../docs/07_audio_i2s_codec_notes.md`
- `../docs/06_firmware_architecture.md`
- `../docs/08_test_plan.md`
- `device_loop.md` (if hardware connected)

## Step 3
- `../docs/06_firmware_architecture.md`
- `../docs/08_test_plan.md`
- `device_loop.md` (if hardware connected)

## Step 4
- `../docs/05_ble_gatt_spec.md`
- `../docs/06_firmware_architecture.md`
- `device_loop.md` (if hardware connected)

## Step 5
- `../docs/05_ble_gatt_spec.md`
- `../docs/02_mvp_scope.md`
- `../docs/08_test_plan.md`
- `device_loop.md` (if hardware connected)

## Step 6
- `../docs/05_ble_gatt_spec.md`
- `../docs/02_mvp_scope.md`
- `../docs/08_test_plan.md`
- `device_loop.md` (if hardware connected)

## Step 7
- `../docs/05_ble_gatt_spec.md`
- `../docs/08_test_plan.md`
- `device_loop.md` (if hardware connected)

## Step 8
- `../docs/05_ble_gatt_spec.md`
- `../docs/08_test_plan.md`
- `../docs/12_implementation_backlog.md`
- `device_loop.md` (if hardware connected)

## Step 9
- `../docs/08_test_plan.md`
- `../docs/12_implementation_backlog.md`
- `device_loop.md` (if hardware connected)

## Step 10
- `../docs/05_ble_gatt_spec.md`
- `../docs/16_kiss_over_ble_spec.md`
- `../docs/17_mvp_gap_analysis.md`
- `../docs/12_implementation_backlog.md`

## Step 11
- `../docs/11_hf_ble_feasibility_study.md`

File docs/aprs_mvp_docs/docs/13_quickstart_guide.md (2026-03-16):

# PAKT APRS Pocket TNC — Setup and Quickstart Guide (DOC-001)

Version: 0.1 (pre-hardware draft — validated by new-user test required before DOC-001 closes)
Date: 2026-03-09

---

## What you need

| Item | Notes |
|---|---|
| PAKT APRS Pocket TNC device | Charged via USB-C before first use |
| Windows 10/11 PC with Bluetooth 4.2+ | Bluetooth must be enabled |
| Python 3.10+ | Comes with Windows 11; or install from python.org |
| Amateur radio licence | Required to transmit on 144.390 MHz APRS |
| Valid callsign and SSID | e.g. `W1AW`, SSID `9` for a portable tracker |

---

## Step 1 — Install the desktop test app

```
pip install bleak
```

Clone or download the PAKT repository, then navigate to the desktop test app:

```
cd app/desktop_test
python main.py
```

The app starts in disconnected state and displays the main menu.

---

## Step 2 — Power on the device

Connect the PAKT TNC to USB-C power (or use a charged LiPo battery).
The device will:
1. Boot the ESP32-S3 (< 2 s).
2. Start advertising as **PAKT-TNC** over BLE.
3. Begin listening for APRS packets on 144.390 MHz (default).

The device is ready when the blue LED blinks slowly (advertising mode).

---

## Step 3 — Scan and connect

In the desktop app main menu:

```
  [S]  Scan for PAKT devices
```

Press `S` then Enter. The app scans for 8 seconds and lists found devices:

```
  [0]  PAKT-TNC  (AA:BB:CC:DD:EE:FF)
Select [0]:
```

Press Enter to select device 0 (or type the index number).

---

## Step 4 — Pair the device (first use only)

On **first connection**, Windows will show a Bluetooth pairing dialog.
Accept the pairing request. The device uses LE Secure Connections — no PIN is required.

After pairing, the app displays:

```
      <timestamp>  CONNECT         AA:BB:CC:DD:EE:FF      mtu=247
      <timestamp>  SUBSCRIBE       device_status          ok
      ...
```

You are now connected and bonded.

> **If you do NOT see a pairing dialog** and writes are rejected with `[!] AUTH_ERR`:
> See [Pairing and Security Policy](14_pairing_security_policy.md) for the bond-reset procedure.

---

## Step 5 - Configure your callsign

Press `3` (Write config) and enter your configuration as JSON:

```json
{
  "callsign": "W1AW",
  "ssid": 9
}
```

The app will show a diff of any changes vs. the cached config, then write to the device.
The device stores config in NVS flash (survives reboot).

**Field meanings:**

| Key | Description | Example |
|---|---|---|
| `callsign` | Your amateur callsign (no SSID) | `"W1AW"` |
| `ssid` | APRS SSID (0-15); 9 = portable | `9` |

## Step 6 — Read device info and status

Press `1` to read Device Information Service (firmware version, model, manufacturer).

Press `8` (Listen 30 s) to see live notifications:
- `device_status` — radio state, GPS fix, BLE bond state, pending TX count
- `gps_telem` — lat/lon/alt/speed/course/sats
- `power_telem` — battery voltage and percentage, TX power, VSWR, temperature
- `system_telem` — free heap, CPU load, packet counts, uptime

Press `T` at any time to see the latest telemetry snapshot without waiting for a notify.

---

## Step 7 - Send a test message

Press `7` (Send TX request) and enter:

```json
{"dest":"APRS","text":"Hello from PAKT","ssid":0}
```

`msg_id` is assigned by firmware and returned via `tx_result` notifications.
Watch for `tx_result` notifications - the device sends one for each transmission attempt
and a final terminal result (`acked`, `timeout`, `cancelled`, or `error`).

Press `9` to view the message queue with per-message state and attempt count.

## Step 8 — Export logs and diagnostics

Press `E` to export the full timestamped session log to `pakt_session_<timestamp>.log`.

Press `X` to export the structured diagnostics report (telemetry stats, packet counts,
GPS track, power history) to `pakt_diagnostics_<timestamp>.json`.

---

## Step 9 — Disconnect

Press `D` to disconnect cleanly. Press `Q` to quit.

The last-read config is cached locally in `pakt_config_cache.json` and shown on the
next startup so you always know the last-known device state.

---

## Frequency and regulatory notes

- Default frequency: **144.390 MHz** (North America APRS)
- Europe: 144.800 MHz — change via `radio_set` command (Step 7, command `{"cmd":"radio_set","freq_hz":144800000}`)
- **Transmitting requires a valid amateur radio licence** for the frequency and region in use.
- The device will not transmit until a valid callsign is configured (Step 5).

---

## Troubleshooting quick reference

| Symptom | Check |
|---|---|
| Device not found in scan | Ensure BLE is enabled on PC; device is powered and advertising (blue LED blinking) |
| Write rejected with AUTH_ERR | Bond is missing — see [Pairing and Security Policy](14_pairing_security_policy.md) |
| No GPS fix (`gps_fix: false`) | Move to outdoor location with clear sky view; allow 1–2 min for cold fix |
| No notifications arriving | Press `8` to subscribe; check that `SUBSCRIBE` lines appeared after connect |
| Config lost after reboot | Ensure write completed with no AUTH_ERR; check NVS flash is not erased |
| TX request stays in `pending` | Verify callsign is set; check radio state in `device_status` notify |

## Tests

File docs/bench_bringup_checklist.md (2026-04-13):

# Hardware Bench Bring-Up Checklist

Aligned with: `hardware/prototype_breakout_wiring_plan.md`
Purpose: step-by-step validation sequence for first EVT prototype bring-up.

Status source for what is already software-complete versus still hardware-gated:
- `docs/aprs_mvp_docs/agent_bootstrap/gate_pass_matrix.md`
- `docs/aprs_mvp_docs/agent_bootstrap/audit.md`

Each step lists the expected outcome and the failure mode to watch for.
Record measured values in `docs/bench_measured_values_template.md`.

Bench selection note:
- Blocking bench stages are now configurable in `firmware/main/bench_profile_config.h`.
- For focused debug runs, disable unrelated stages before rebuilding/flashing.
- APRS Stage C can now be run as an isolated recorder/export workflow and has a configurable ADC gain step.
- The audio pipeline sample rate is also selectable there (`8 kHz` or `16 kHz`);
  the current high-fidelity debug path prefers `16 kHz`.
- A separate quiet capture profile now exists for low-noise RX debugging:
  - `firmware/main/bench_profile_quiet_codec_capture.h`
  - includes a `30 s` pre-roll countdown before recording starts
  - uses framed binary chunk export instead of the older long base64 stream
  - current known-good RX baseline:
    - `16 kHz`
    - full `512`-frame mono processing from each `2048-byte` I2S batched read
    - Stage C SA818 volume `4`
    - low ADC gain (`+1.5 dB` at the time of the successful decode run)

---

## Pre-power checklist (bench setup)

Before applying any power:

- [ ] Wiring matches `hardware/prototype_breakout_wiring_plan.md` pin map — verify each net
- [ ] I2C pull-ups: exactly one set (2.2–4.7 kΩ to 3.3 V); duplicates removed/lifted
- [ ] SA818 supply decoupling populated: 100 nF + 10 µF + 220–470 µF bulk near module
- [ ] SGTL5000 supply decoupling: local 10 µF on harness if leads are long
- [ ] GPS breakout decoupling: 100 nF on VIN/VCC
- [ ] No solder bridges on Feather headers or audio adapter
- [ ] PTT net open (SA818 PTT not asserted) — verify with multimeter before power-on

---

## Step 1 — Power-only smoke test

**Goal:** verify supply rails before connecting active peripherals.

1. [ ] Apply USB 5 V to Feather USB port (no battery, no SA818 connected)
2. [ ] Measure V_3V3 on Feather 3.3 V rail → expect 3.28–3.36 V
3. [ ] Measure current draw → expect < 50 mA (MCU idle only)
4. [ ] No thermal hot spots on Feather LDO or Feather board
5. [ ] Open serial monitor (115200 baud) — expect `PAKT firmware vX.Y.Z starting` log

**Failure mode:** over-current or missing 3.3 V → check for wiring short before proceeding.

---

## Step 2 — BLE advertising visible

**Goal:** confirm BLE stack starts without errors.

1. [ ] Power on (USB)
2. [ ] On a phone or PC BLE scanner, scan for device named `PAKT-TNC`
3. [ ] Device appears in advertising list within 5 s
4. [ ] Serial log shows `BleServer init` and `advertising started` (or equivalent)

**Failure mode:** device not visible → check NimBLE stack log for init errors.

---

## Step 3 — BLE connect + security handshake (G3 critical path)

**Goal:** verify encrypted+bonded write enforcement.

1. [ ] Connect with desktop test app: `python app/desktop_test/main.py`
2. [ ] Attempt a config write **before** pairing → expect write rejected with auth error
3. [ ] Initiate pairing via OS Bluetooth settings → `PAKT-TNC` → Pair
4. [ ] Retry config write with `{"callsign":"W1AW"}` → expect **success** (no error)
5. [ ] Reconnect without re-pairing → config write still succeeds (bond retained)

Record: paired successfully, auth error confirmed on unpaired write.

**Failure mode:** write accepted without pairing → critical security regression; do not proceed.

---

## Step 4 — I2C detect (SGTL5000)

**Goal:** confirm SGTL5000 codec responds at its I2C address.

1. [ ] Connect Teensy Audio Rev D to Feather per wiring plan (`I2C_SDA=GPIO3`, `I2C_SCL=GPIO4`)
2. [ ] Power on
3. [ ] Ensure firmware starts `SYS_MCLK` before codec probing
4. [ ] Run I2C scan firmware or monitor log for SGTL5000 detect message
5. [ ] Expected I2C devices on the current harness: `0x0A` (SGTL5000), `0x36` (MAX17048), `0x42` (u-blox M9N), and the SH1106 display at `0x3C` or `0x3D`
6. [ ] Serial log shows `Using SGTL5000 candidate address 0x0A` and successful codec init

---

## Step 4b — SH1106 display smoke test

**Goal:** confirm the `1.3 inch IIC v2.0` display on the default I2C bus is detected and can render a basic system screen.

1. [ ] Connect the SH1106 display to the Feather default I2C bus (`GPIO3` SDA, `GPIO4` SCL, `3.3V`, `GND`)
2. [ ] Confirm the I2C scan shows the display at `0x3C` or `0x3D`
3. [ ] Verify the display powers on without disturbing the other I2C devices
4. [ ] Run a display smoke test that renders:
   - top row: battery status, GPS status, current frequency
   - main area: placeholder text or the most recent received APRS message
5. [ ] Confirm the screen refresh remains stable while BLE, GPS, and radio tasks are running
6. [ ] Confirm no I2C bus lockup or codec/GPS disappearance after repeated resets

Record: detected I2C address, refresh behavior, any visual corruption, and whether the display introduces bus instability.

---

## Step 5 — SA818 UART command test

**Goal:** confirm Sa818Radio driver, UART communication, and PTT polarity.

Driver: `firmware/components/radio_sa818/Sa818Radio.cpp` — wired into `radio_task` via
`Sa818UartTransport` (UART1, 9600 8N1) and `PttGpioFn` lambda (GPIO11 active-low).

1. [ ] Connect SA818 to Feather per wiring plan:
   - Feather GPIO13 → SA818 RX (AT command input)
   - Feather GPIO9 → SA818 TX (AT response output)
   - Feather GPIO11 → SA818 PTT (active low)
2. [ ] Power on SA818 supply rail; measure V_RADIO → expect 3.6–4.2 V (SA818 datasheet §4)
3. [ ] Power on Feather; serial log must show within 2 s:
   - `radio: PTT GPIO11 configured (HIGH=off); watchdog safe-off registered`
   - `sa818_bench: --- STAGE 1: UART HANDSHAKE (AT+DMOCONNECT) ---`
   - `radio: SA818 init OK`
   - (If init fails: `radio: SA818 init failed – radio unavailable; PTT remains off`)
4. [ ] Confirm AT handshake visible on UART1 with logic analyser or USB-serial tap:
   - Firmware sends: `AT+DMOCONNECT\r\n`
   - SA818 responds: `+DMOCONNECT:0\r\n`
   - If deeper UART debugging is enabled, the bench also logs `TX write: ok` and pending RX-byte diagnostics after timeouts
5. [ ] Serial log shows frequency set: `AT+DMOSETGROUP=1,144.3900,144.3900,0000,1,0000\r\n`
   - SA818 responds: `+DMOSETGROUP:0\r\n`
6. [ ] PTT polarity test — trigger a TX request via BLE; measure SA818 PTT pin:
   - PTT asserted (TX on)  → GPIO11 LOW  → SA818 PTT pin should be LOW
   - PTT de-asserted (idle) → GPIO11 HIGH → SA818 PTT pin should be HIGH
7. [ ] **Do not sustain TX** — immediately cancel or wait for timeout after polarity confirmed

Record: SA818 UART response string, PTT voltage on assert/de-assert, V_RADIO under TX load.

Current verified note from 2026-03-21:
- the full test firmware again completed:
  - `+DMOCONNECT:0`
  - `+DMOSETGROUP:0`
  - staged PTT toggle
  - 10-tone TX bench
  - externally received APRS packet TX

**Failure modes:**
- `SA818 init failed` in log → check UART wiring polarity (TX/RX swap is common)
- PTT logic inverted → verify GPIO11 is wired to SA818 PTT; check active-low assumption
- `+DMOCONNECT:1` response → SA818 in bad state; power-cycle SA818 supply rail

---

## Step 6 — I2S / MCLK stability

**Goal:** confirm MCLK is present and I2S clocks are stable.

1. [ ] With SGTL5000 and Feather connected, power on
2. [ ] Probe I2S_MCLK (GPIO14) with oscilloscope → expect 8.192 MHz
3. [ ] Probe I2S_BCLK (GPIO8) → expect 256 kHz
4. [ ] Probe I2S_WS (GPIO15) → expect 8 kHz square wave
5. [ ] Monitor for I2S underrun/overrun counters in serial log (should be 0 at idle)

Clock plan:
- ESP32-S3 I2S master uses `I2S_MCLK_MULTIPLE_1024` at 8 kHz → `8.192 MHz` MCLK
- SGTL5000 expects `SYS_FS = 32 kHz`, `RATE_MODE = ÷4` → effective `8 kHz` ADC/DAC
- Expected ratio: `MCLK / BCLK = 32`

Record: MCLK frequency, BCLK frequency, WS frequency, and whether the measured values are stable across reconnect/reset.

---

## Step 7 — Audio loop calibration (codec ↔ SA818)

**Goal:** set TX audio level and RX audio level for correct APRS deviation.

1. [ ] Connect SGTL5000 line out → SA818 AF_IN via AF_TX_COUPLED network (1 µF + attenuator footprint)
2. [ ] Connect SA818 AF_OUT → SGTL5000 line in via AF_RX_COUPLED network (1 µF + optional RC LPF)
3. [ ] Run the firmware bench stages and confirm:
   - headphone tones are audible on the PJRC jack
   - `audio_bench` shows non-zero `peak` / `rms` values when `LINE_IN` is driven
   - `sa818_bench` runs the 10-tone TX sequence only with a load or antenna attached
   - `sa818_bench` RX stage logs live `rx_peak_abs` values while a nearby radio transmits voice/audio
4. [ ] Inject a 1200 Hz / 2200 Hz Bell 202 tone pair from PC audio into codec line in
5. [ ] Monitor SA818 AF_IN level with AC voltmeter → adjust attenuator for ~100 mVpp (SA818 AF_IN nominal)
6. [ ] Key SA818 TX; monitor TX deviation with calibrated reference receiver or RF power meter
7. [ ] Target: ±3 kHz deviation for FM APRS (adjust R divider in AF_TX_COUPLED)

Record: AF_TX_COUPLED attenuation setting, measured deviation, SA818 AF_OUT level into codec, and RX `max_peak` / `signal_seconds` from the bench log.

---

## Step 8 — GPS NMEA lock

**Goal:** confirm GPS transport and fix acquisition.

1. [ ] Connect the u-blox module to the Feather default I2C/STEMMA bus (`GPIO3` SDA, `GPIO4` SCL) and confirm `0x42` appears on the boot I2C scan
2. [ ] Place GPS module with sky view (window or outdoors)
3. [ ] Serial log shows raw NMEA sentences being received from `gps_task` even before fix
4. [ ] BLE GPS telemetry notify updates at 1 Hz; `fix=0` is acceptable before lock
5. [ ] Wait for fix (typically 30–60 s cold start, <5 s hot start)
6. [ ] BLE GPS telemetry notify shows non-zero `lat`, `lon`, `sats ≥ 4`, `fix = 1`

Record: time to first fix, sat count at fix, lat/lon vs known reference.

Current verified note from 2026-03-28:
- the shared Feather I2C/STEMMA GPS path is now working on the current prototype
- GPS telemetry is reaching the app over BLE
- this step should now treat shared-I2C GPS transport as the known-good baseline; remaining work is fix timing, repeatability, and longer-run validation
- the SH1106 display now shares this same default I2C path, so GPS validation should also confirm display updates remain stable while GPS traffic is active

---

## Step 9 — Full APRS TX beacon

**Goal:** end-to-end APRS TX decode on a reference receiver.

1. [ ] All prior steps completed and passing
2. [ ] Callsign configured via BLE config write
3. [ ] Send a TX request via BLE: `{"dest":"APRS","text":">PAKT bench test"}`
4. [ ] Observe TX result notify on desktop app: `{"msg_id":"1","status":"tx"}`
5. [ ] Reference TNC or SDR + software decoder confirms APRS frame decode
6. [ ] Frame shows correct source callsign, destination, and text
7. [ ] Repeat 5× while monitoring for resets, brownout events, or PTT stuck-on

Record: decode success rate, receiving device/app used, decoded packet text, and any brownout or WDT reset events.

Current verified note from 2026-03-21:
- the current full test firmware and wiring state again produced APRS packets that were received externally after SA818 handshake/config recovery
- this step should now treat TX functionality as a restored known-good baseline, while deviation and repeatability remain to be measured formally

**Important:** hearing Bell 202 tones is not enough for Step 9 to pass; this step requires packet-level APRS decode on the receiving side.

---

## Step 9b — APRS RX listen window

**Goal:** prove the prototype can decode on-air APRS packets, not just voice energy or generic RF audio.

1. [ ] Tune the prototype to the APRS channel for your region (`144.390 MHz` in North America)
2. [ ] Provide a real APRS source during the receive window:
   - APRSdroid + HT audio/PTT interface
   - a TNC-connected radio
   - a second PAKT board transmitting APRS frames
3. [ ] Transmit APRS packets every 20-30 seconds during the firmware RX bench window
4. [ ] Confirm the prototype logs a decoded AX.25/APRS frame
5. [ ] If no frame decodes, record whether `rx_peak_abs` changed anyway
6. [ ] If deeper analysis is needed, run the 30-second RX recorder stage and save the emitted base64 WAV dump from serial for offline analysis
7. [ ] Prefer the `16-bit` Stage C recorder path for new captures; use the selected ADC gain step in `bench_profile_config.h` to match the best observed RX margin
8. [ ] For repeated RX investigations, prefer the quiet-capture profile and record the exact profile/mode used:
   - left-only vs stereo-average
   - sample rate
   - ADC gain
   - export method used

Record: APRS source used, packet interval, approximate distance, decoded frame examples if any, `rx_peak_abs` behavior if decode fails, and whether a 30-second WAV capture was exported.

Current troubleshooting note from 2026-03-20:
- a targeted Stage C workflow now exists for capture-only RX debugging via `firmware/main/bench_profile_config.h`
- the 30-second recorder/export path has been validated on hardware using PSRAM-backed `16-bit` mono WAV capture
- saved captures currently suggest a mismatch between what the firmware records at the demod input and what the oscilloscope shows on the analog RX nodes
- scope captures in `/Users/macmini4/Desktop/PAKT/tmp/osc/` indicate the two probed analog points track each other reasonably well after scaling, which reduces the likelihood of gross waveform destruction between `SA818 AF_OUT` and `SGTL5000 LINE_IN_L`
- because of that, future RX debug should prioritize:
  - short burst-triggered raw sample dumps from the firmware `mono_buf`
  - side-by-side comparison against the same event on the scope
  - verification of SGTL5000 input/gain/config and I2S RX sample interpretation
  - use of the new RX debug controls in `bench_profile_config.h`:
    - `kRxInputMode`
    - `kRxSwapStereoSlots`

Current handoff note from 2026-03-27:
- the newer quiet-capture profile has produced repeated full `30 s` `16-bit` `16 kHz` WAV artifacts through a framed binary export path
- this simpler capture flow appears somewhat cleaner than the older full-system/base64 workflow
- however, do not yet assume that the waveform improvement is fully “real”
- the current host-side reconstruction still has to undo newline rewriting introduced by serial transport, so some remaining artifact could still belong to the transfer path rather than the codec capture itself
- the next investigator should therefore treat the quiet-capture artifacts as the best current evidence, but still provisional until cross-checked against a less ambiguous retrieval path
    - `kRxByteSwapSamples`
    - `kRxEnableDcBlock`
    - `kRxDcBlockPole`

Current verified note from 2026-03-27 (later same session):
- the quiet-profile RX path now has a confirmed firmware fix for a real capture bug:
  - firmware was previously unpacking only half of each `2048-byte` batched I2S read
  - this effectively fed the demodulator at `~8 kHz` while configured for `16 kHz`
  - the corrected path now processes the full `512` mono frames per read
- successful live indicators from the corrected run:
  - `samp=15872` at `1 s`, then `31744`, `48128`, etc.
  - Stage C SA818 volume reduced to `4` to eliminate the earlier full-scale clipping
  - multiple log lines:
    - `audio: AFSK: decoded AX.25 frame (61 bytes) → queue`
- saved artifacts from the first successful corrected run:
  - `/Users/macmini4/Desktop/PAKT/tmp/rx_captures/live_after_fix_run1.log`
  - `/Users/macmini4/Desktop/PAKT/tmp/rx_captures/quiet_capture_after_fix_run1.raw`
  - `/Users/macmini4/Desktop/PAKT/tmp/rx_captures/quiet_capture_after_fix_run1.wav`
- this is now the preferred RX baseline for follow-up work

Updated practical interpretation for Step 9b:
- on-device APRS RX decode is now proven on hardware
- this step should now focus on:
  - repeatability across runs and sources
  - decode margin / gain tuning
  - documenting the known-good settings
  - saving example decoded frames and corresponding WAV artifacts

---

## Step 10 — PTT stuck-on fault test (G3 critical path)

**Goal:** confirm PttWatchdog (FW-016) de-asserts PTT under fault conditions.

FW-016 parameters (see `PttWatchdog::kDefaultTimeoutMs`):
- Timeout: 10 000 ms (10 s)
- Supervisor tick: 500 ms
- `aprs_task` heartbeat: every 1 000 ms (loop period)

Sub-test A — Stale heartbeat (BLE disconnect):

1. [ ] Send a TX request; observe `status: tx` notify and PTT asserted on SA818
2. [ ] Kill the desktop app or disconnect BLE (do not send any further heartbeat)
3. [ ] Within 10–11 s, firmware serial log must show: `PTT WATCHDOG TRIGGERED at t=... ms – forcing PTT off`
4. [ ] PTT must de-assert (SA818 PTT pin goes high) within that window
5. [ ] After reconnect, send a fresh TX request → watchdog re-arms, PTT can be asserted again (recovery)

Sub-test B — aprs_task hang simulation (not possible in software stub; revisit when SA818 driver wired):

1. [ ] When SA818 driver is wired, induce a deliberate `vTaskDelay` hang in aprs_task
2. [ ] Watchdog fires within 10 s; PTT de-asserts; verify via SA818 PTT pin

Sub-test C — Reboot safe-off:

1. [ ] During active TX, remove power briefly then restore
2. [ ] On reboot, PTT must be low before firmware log prints first line
3. [ ] Firmware log must show `PTT default state: OFF` before any task starts

**Failure mode:** PTT stays high after BLE disconnect or reboot → **do not transmit further**; investigate FW-016 watchdog wiring before any field use.

---

## Pass/fail summary

| Gate | Step | Pass criterion |
|---|---|---|
| G0 | 1–2 | Flash, boot, BLE advertising |
| G3 | 3, 10 | Auth enforcement, PTT safe-off |
| G1 | 4–9 | Full APRS TX decode on reference receiver |
| G2 | — | 1-hour BLE endurance run (separate test session) |
| G4 | 7, 9 | No resets under repeated TX; audio levels in spec |

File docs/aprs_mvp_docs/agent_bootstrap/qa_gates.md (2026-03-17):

# QA Gates (Must Pass)

Gate scope:
- **G0** — per-change gate: must pass before merging any PR or committing a step complete. Failure blocks the current change, not just milestone closure.
- **G1–G4** — milestone gates: must all pass before closing the MVP milestone. Any G1–G4 failure blocks milestone closure. Safety/security gate (G3) failures additionally block any further TX-capable changes.

## Gate G0 - Build/Test hygiene (every change)
- Firmware builds in CI/local.
- Unit tests for touched logic pass.
- No new critical warnings in touched modules.
- If board connected: firmware flashes and boots cleanly on target ESP32-S3.

## Gate G1 - Functional MVP
- Beacon TX decodes on known-good receiver.
- SGTL5000 `SYS_MCLK` and sample-rate configuration remains stable across reconnect/reinit cycles.
- RX decode stream reaches app correctly.
- Message send/ack/timeout states correct.
- KISS-over-BLE exchanges frames correctly with at least one reference client or bridge.
- Controlled-condition beacon decode target: >= 95%.

## Gate G2 - BLE reliability
- Desktop harness connect/reconnect and log export pass before mobile validation.
- 1 hour continuous RX BLE session stable.
- Reconnect works after link drop and device reboot.
- Chunk reassembly handles loss/duplicates/timeouts.
- Native BLE and KISS-over-BLE can coexist without breaking each other.

## Gate G3 - Security and safety
- Write endpoints blocked when not encrypted+bonded.
- Pairing window and bond-reset flow validated.
- Fault tests always return to `PTT=off`.

## Gate G4 - Power and field sanity
- No reset loop under repeated TX bursts.
- Battery telemetry is sane and monotonic under load.
- Field test script completed with issue log.

## Evidence required before closing milestone
- Test log summary
- Failures + fixes
- Residual risks + mitigation owner
- For connected runs: port/profile used and startup monitor excerpt

## Gate failure handling
- G0 failure: do not mark the step complete or merge; fix and re-run before proceeding.
- G1–G4 failure: do not close the MVP milestone; document the failure, assign an owner, and resolve before release.
- If a gate cannot be executed due to hardware access limits, mark as `blocked` with exact missing dependency.
- Do not treat partial checks as full pass.
- G3 (security/safety) failure additionally blocks any further TX-capable changes until resolved.

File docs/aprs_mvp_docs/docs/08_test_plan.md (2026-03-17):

# Test plan (MVP)

## 1) Bench tests
### Power
- Charge current, thermal behavior
- Battery voltage measurement accuracy
- Current draw in:
  - idle BLE connected
  - RX active
  - TX beacon every 60s
  - sleep mode

### SA818 control
- UART command success rates
- Frequency set and stability
- PTT timing

### Audio path
- Verify codec sample rate accuracy
- Measure TX audio level at SA818 input
- Verify RX audio not clipping

## 2) RF functional tests
### TX APRS beacon
- Decode with known-good receiver + decoder
- Confirm symbol, comment, position format

### RX decode
- Receive packets from local digipeaters / test transmitter
- Verify decode rate at varying signal levels

### Messaging
- Send message to a station that will ACK
- Verify retry and timeout behavior

## 3) BLE + app tests
- Windows desktop app:
  - Connect/pair/reconnect stability
  - Config read/write parity with firmware schema
  - RX stream, TX request/result, telemetry decode validation
  - KISS RX/TX chunking, frame integrity, and coexistence with native BLE endpoints
  - Session log export and timestamp consistency
- Pairing stability (Android, iOS)
- Config persistence after reboot
- Packet stream reliability under load
- Reconnect behavior
- KISS client compatibility:
  - At least one reference KISS client or bridge can send a frame to PAKT
  - At least one reference KISS client or bridge receives a frame from PAKT
  - Oversize or malformed KISS frames are rejected safely without crashing native BLE flows

## 4) Field tests
- Mobile beaconing on foot/vehicle
- Battery endurance in real usage
- Thermal performance in pocket/bag
- Third-party KISS software interoperability in a realistic operator workflow

## Acceptance criteria (MVP)
- 95%+ beacon packets decode cleanly on a nearby receiver in controlled conditions
- RX can decode local APRS traffic without frequent false frames
- Messages show clear send/ack feedback in app
- BLE connection stays stable for 1 hour continuous RX stream
- KISS-over-BLE works with at least one reference third-party APRS client or compatibility bridge

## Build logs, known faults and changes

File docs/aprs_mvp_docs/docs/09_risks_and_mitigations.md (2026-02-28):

# Risks and mitigations

## Audio level/deviation calibration
**Risk:** Packets not decodable due to wrong deviation/clipping.
**Mitigation:** I2S codec, calibration modes, configurable gain, simple limiter.

## RF desense from digital noise
**Risk:** ESP32/codec noise reduces RX performance.
**Mitigation:** RF shielding, layout separation, filtering, good grounding, LC filters.

## iOS background BLE limitations
**Risk:** iOS may throttle background streams.
**Mitigation:** Keep BLE payload small, session-based operation, app design that expects foreground use for continuous RX.

## Support burden (antennas, local APRS infrastructure)
**Risk:** Users blame device for coverage/path issues.
**Mitigation:** In-app diagnostics (last heard digi, path presets), clear docs, “RF basics” troubleshooting guide.

## Regulatory / regional frequency differences
**Risk:** Wrong default frequency for user region.
**Mitigation:** Region presets during setup; store user selection.

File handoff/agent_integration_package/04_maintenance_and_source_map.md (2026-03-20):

# Maintenance Guide And Source Map

This package is intended to stay maintainable as hardware and BLE behavior
change. Use this file to know where to update the source docs.

## Authoritative sources by topic

### Payload JSON contracts

Primary source:

- `docs/aprs_mvp_docs/payload_contracts.md`

Code that should stay aligned:

- `firmware/components/payload_codec/`
- `firmware/components/telemetry/`
- `firmware/components/capability/`
- `app/desktop_test/pakt_client.py`
- `app/desktop_test/telemetry.py`
- `app/desktop_test/capability.py`
- `app/desktop_test/message_tracker.py`

### BLE UUIDs and GATT layout

Primary sources:

- `docs/aprs_mvp_docs/docs/05_ble_gatt_spec.md`
- `firmware/components/ble_services/include/pakt/BleUuids.h`
- `firmware/components/ble_services/BleServer.cpp`

### Actual implementation status

Primary sources:

- `firmware/main/main.cpp`
- `docs/aprs_mvp_docs/agent_bootstrap/gate_pass_matrix.md`
- `docs/aprs_mvp_docs/agent_bootstrap/audit.md`

### Hardware interfaces and assumptions

Primary sources:

- `docs/aprs_mvp_docs/hardware/interfaces.md`
- `hardware/prototyping_wiring.md`
- `hardware/prototype_breakout_wiring_plan.md`
- `docs/bench_bringup_checklist.md`

### Third-party interoperability direction

Primary sources:

- `docs/aprs_mvp_docs/docs/15_interoperability_matrix.md`
- `docs/aprs_mvp_docs/docs/16_kiss_over_ble_spec.md`

## Known doc drift to watch

### Device Capabilities payload example drift

Current issue:

- `docs/aprs_mvp_docs/docs/05_ble_gatt_spec.md` shows an older simple example
  for Device Capabilities
- firmware and desktop app actually use:
  `{"fw_ver","hw_rev","protocol","features":[...]}`

Rule:

- when updating capability behavior, update both the GATT spec example and
  `payload_contracts.md`

### Spec versus implemented endpoint maturity

Current issue:

- some characteristics are fully specified, but the live firmware production
  path is still stubbed or hardware-gated

Rule:

- whenever an endpoint moves from reserved/stubbed to live, update:
  - this handoff package
  - `gate_pass_matrix.md`
  - `payload_contracts.md` if payload shape changed
  - `05_ble_gatt_spec.md` if behavior/property/security changed

## Update checklist when hardware or BLE changes

If UUIDs, services, properties, or security change:

1. update `firmware/components/ble_services/include/pakt/BleUuids.h`
2. update `firmware/components/ble_services/BleServer.cpp`
3. update `docs/aprs_mvp_docs/docs/05_ble_gatt_spec.md`
4. update this package's `02_native_ble_protocol.md`
5. update the desktop test app if host behavior changed

If payload fields change:

1. update `docs/aprs_mvp_docs/payload_contracts.md`
2. update firmware serializers/parsers/validators
3. update desktop app parsers
4. update/add tests
5. update this package's `02_native_ble_protocol.md`

If hardware wiring or internal buses change:

1. update `docs/aprs_mvp_docs/hardware/interfaces.md`
2. update wiring docs under `hardware/`
3. update `docs/bench_bringup_checklist.md`
4. update this package's `01_onboarding_brief.md` if the integration-relevant
   hardware model changed

If project maturity/status changes:

1. update `docs/aprs_mvp_docs/agent_bootstrap/gate_pass_matrix.md`
2. update `docs/aprs_mvp_docs/agent_bootstrap/audit.md`
3. update this package's `03_current_software_and_app_status.md`

## Suggested handoff note for the next agent

Use native PAKT BLE as the richer device integration path and treat
KISS-over-BLE as an MVP interoperability path whose software stack is in place
but whose live hardware validation is still pending. Read capabilities first,
follow payload contracts, implement chunking, and treat hardware-validated
behavior separately from software-complete but still hardware-gated paths.

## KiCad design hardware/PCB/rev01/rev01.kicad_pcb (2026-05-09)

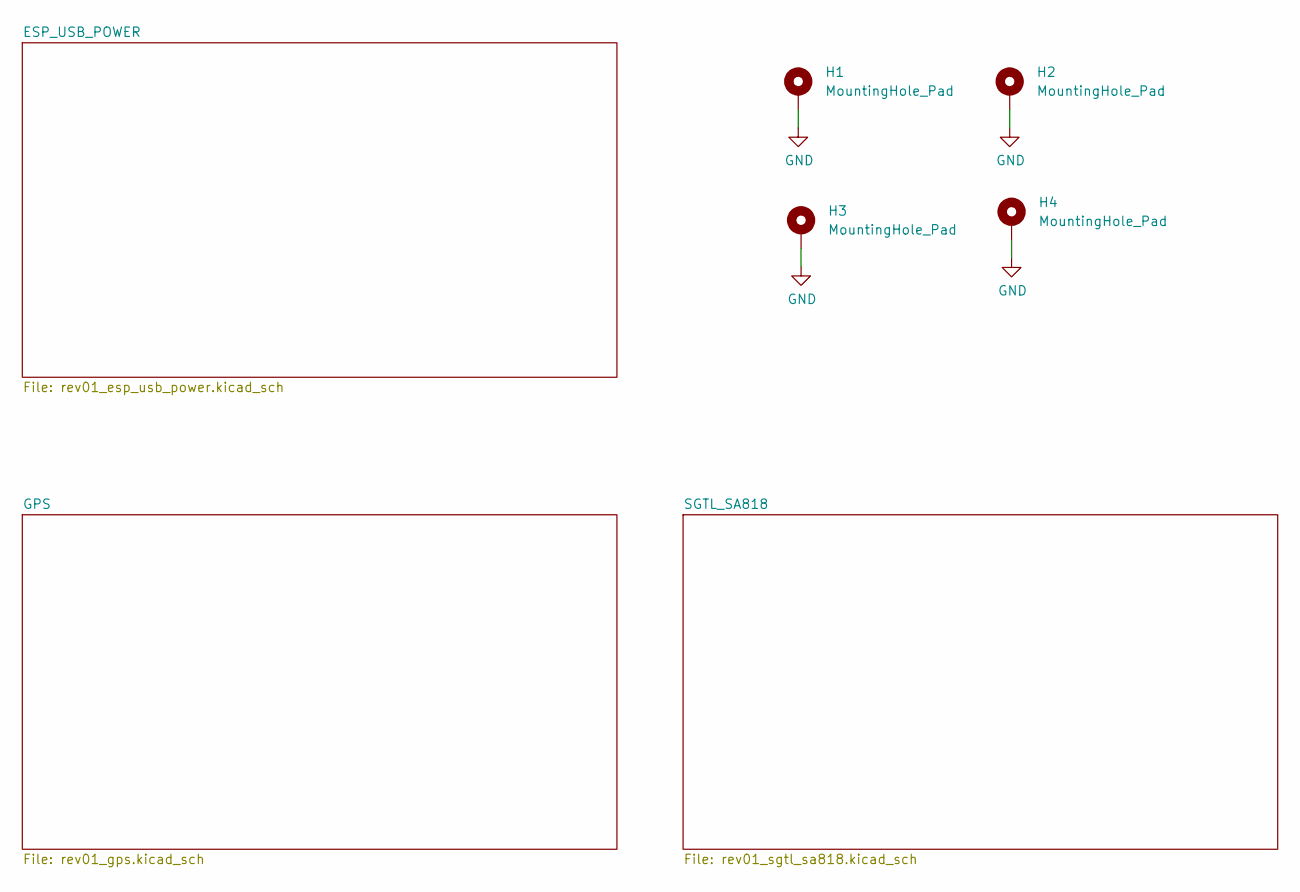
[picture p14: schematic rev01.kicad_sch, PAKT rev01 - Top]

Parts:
H1, H2, H3, H4: MountingHole_Pad; MountingHole_3.2mm_M3_Pad

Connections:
GND: H1.1, H2.1, H3.1, H4.1; also elsewhere on the board

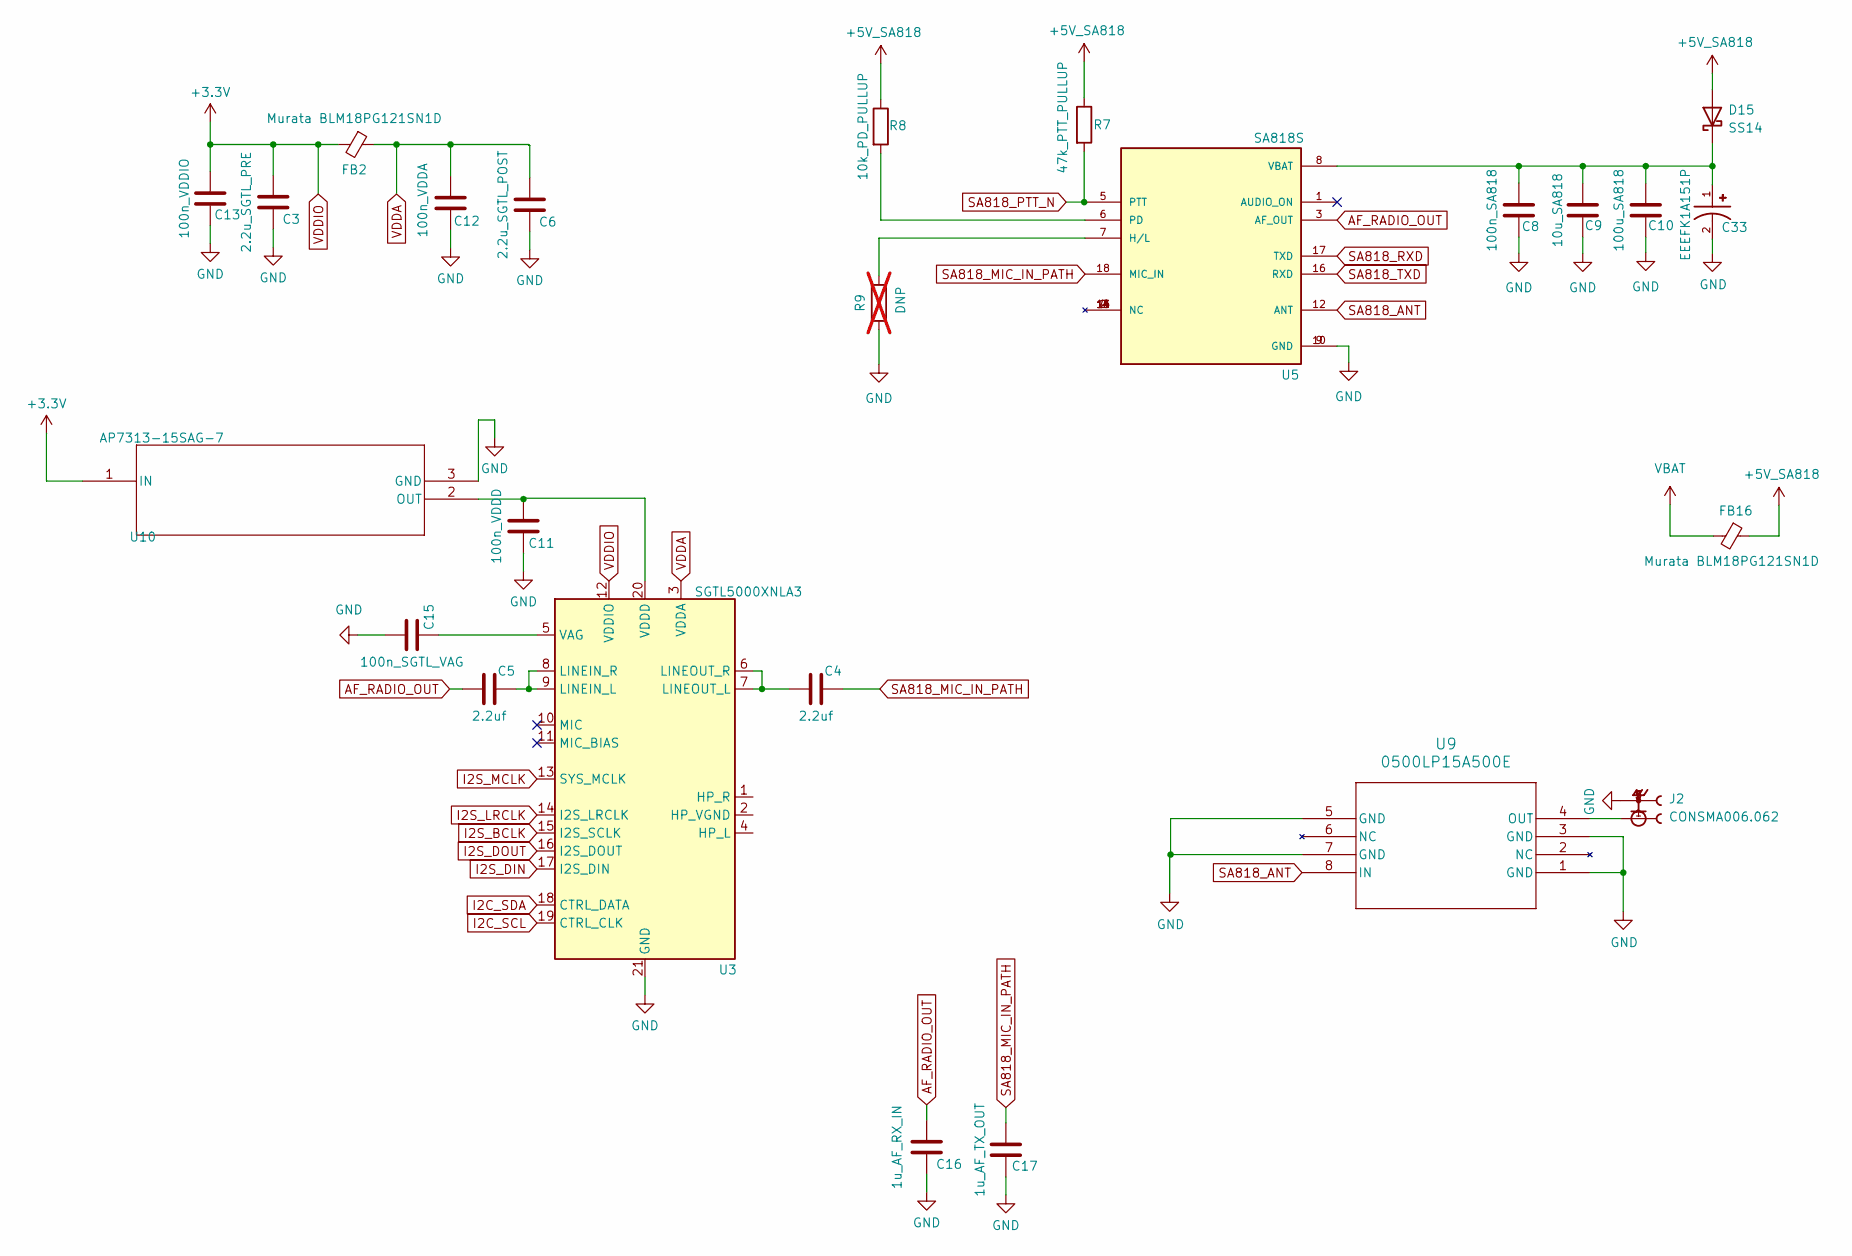
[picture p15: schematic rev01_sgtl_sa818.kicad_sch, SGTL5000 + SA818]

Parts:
C3: 2.2u_SGTL_PRE; C_0603_1608Metric
C4, C5: 2.2uf; C_0603_1608Metric
C6: 2.2u_SGTL_POST; C_0603_1608Metric
C8: 100n_SA818; C_0603_1608Metric
C9: 10u_SA818; C_0805_2012Metric
C10: 100u_SA818; C_1206_3216Metric
C11: 100n_VDDD; C_0603_1608Metric
C12: 100n_VDDA; C_0603_1608Metric
C13: 100n_VDDIO; C_0603_1608Metric
C15: 100n_SGTL_VAG; C_0603_1608Metric
C16: 1u_AF_RX_IN; C_0603_1608Metric
C17: 1u_AF_TX_OUT; C_0603_1608Metric
C33: EEEFK1A151P; CAP_EEEFK1A151P; PARTREV 10-Oct-19
D15: SS14; D_SMA; MPN SS14
FB2, FB16: Murata BLM18PG121SN1D; R_0603_1608Metric; MPN BLM18PG121SN1D
J2: CONSMA006.062; SMA_Amphenol_132134-14_Vertical_P5; PARTREV B
R7: 47k_PTT_PULLUP; R_0603_1608Metric
R8: 10k_PD_PULLUP; R_0603_1608Metric
R9: DNP; R_0603_1608Metric; not fitted
U3: SGTL5000XNLA3; HUQFN20_SOT1628-1_NXP
U5: SA818S; XCVR_SA818S
U9: 0500LP15A500E; 0500LP15A500E_JOT; MPN 0500LP15A500E
U10: AP7313-15SAG-7; AP7313_15SAG_7

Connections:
+5V_SA818: D15.2 (A), FB16.1, R7.1, R8.1
AF_RADIO_OUT: C5.1, C16.1, U5.3 (AF_OUT)
GND: C3.2, C6.2, C8.2, C9.2, C10.2, C11.2, C12.2, C13.2, C15.1, C16.2, C17.2, C33.2, J2.2, J2.3, J2.4, J2.5, R9.1, U3.21 (GND), U5.9 (GND), U5.10 (GND), U9.1 (GND), U9.3 (GND), U9.5 (GND), U9.7 (GND), U10.3 (GND); also elsewhere on the board
I2C_SCL: U3.19 (CTRL_CLK); also elsewhere on the board
I2C_SDA: U3.18 (CTRL_DATA); also elsewhere on the board
I2S_BCLK: U3.15 (I2S_SCLK); also elsewhere on the board
I2S_DIN: U3.17 (I2S_DIN); also elsewhere on the board
I2S_DOUT: U3.16 (I2S_DOUT); also elsewhere on the board
I2S_LRCLK: U3.14 (I2S_LRCLK); also elsewhere on the board
I2S_MCLK: U3.13 (SYS_MCLK); also elsewhere on the board
unnamed: C8.1, C9.1, C10.1, C33.1, D15.1 (K), U5.8 (VBAT)
unnamed: C5.2, U3.8 (LINEIN_R), U3.9 (LINEIN_L)
unnamed: C4.1, U3.6 (LINEOUT_R), U3.7 (LINEOUT_L)
unnamed: C15.2, U3.5 (VAG)
unnamed: R9.2, U5.7 (H/L)
unnamed: R8.2, U5.6 (PD)
unnamed: J2.1, U9.4 (OUT)
unnamed: C11.1, U3.20 (VDDD), U10.2 (OUT)
SA818_ANT: U5.12 (ANT), U9.8 (IN)
SA818_MIC_IN_PATH: C4.2, C17.1, U5.18 (MIC_IN)
SA818_PTT_N: R7.2, U5.5 (PTT); also elsewhere on the board
SA818_RXD: U5.17 (TXD); also elsewhere on the board
SA818_TXD: U5.16 (RXD); also elsewhere on the board
VBAT: FB16.2; also elsewhere on the board
VDDA: C6.1, C12.1, FB2.1, U3.3 (VDDA)
VDDIO: C3.1, C13.1, FB2.2, U3.12 (VDDIO), U10.1 (IN); also elsewhere on the board

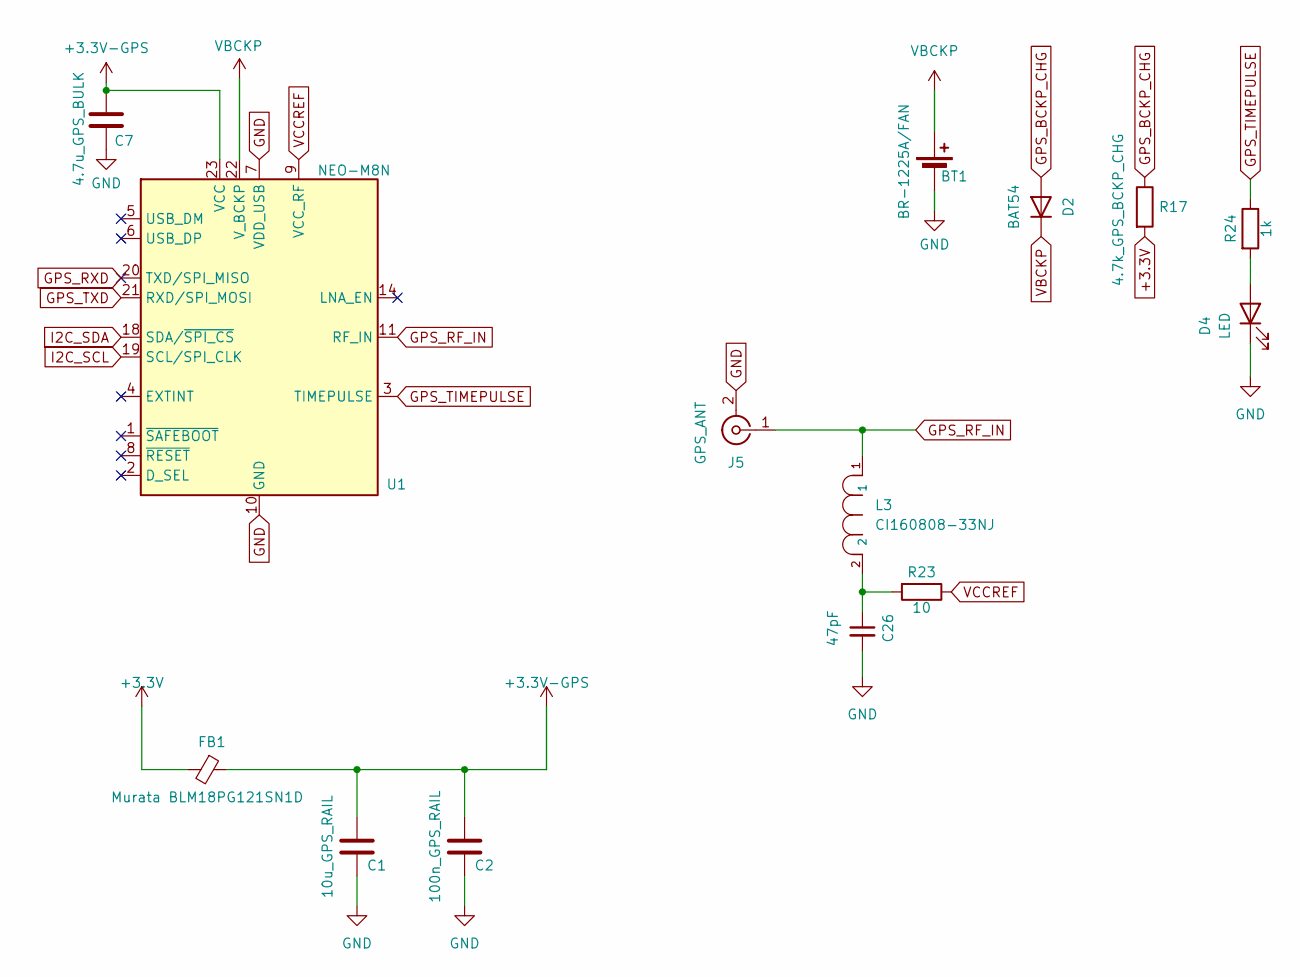
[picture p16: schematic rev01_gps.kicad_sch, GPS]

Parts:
BT1: BR-1225A/FAN; BatteryHolder_Keystone_3000_1x12mm
C1: 10u_GPS_RAIL; C_0805_2012Metric
C2: 100n_GPS_RAIL; C_0603_1608Metric
C7: 4.7u_GPS_BULK; C_0805_2012Metric
C26: 47pF; C_0402_1005Metric
D2: BAT54; D_SOD-323
D4: LED; LED_0603_1608Metric
FB1: Murata BLM18PG121SN1D; R_0603_1608Metric; MPN BLM18PG121SN1D
J5: GPS_ANT; U.FL_Hirose_U.FL-R-SMT-1_Vertical
L3: CI160808-33NJ; L_0603_1608Metric; TOLERANCE ±5 %; MPN CI160808-33NJ
R17: 4.7k_GPS_BCKP_CHG; R_0603_1608Metric
R23: 10; R_0603_1608Metric
R24: 1k; R_0603_1608Metric
U1: NEO-M8N; ublox_NEO

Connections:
+3.3V-GPS: C1.1, C2.1, C7.1, FB1.1, U1.23 (VCC)
GND: BT1.2 (-), C1.2, C2.2, C7.2, C26.2, D4.1 (K), J5.2 (Ext), U1.7 (VDD_USB), U1.10 (GND), U1.12 (GND), U1.13 (GND), U1.24 (GND); also elsewhere on the board
GPS_BCKP_CHG: D2.2 (A), R17.1
GPS_RF_IN: J5.1 (In), L3.1, U1.11 (RF_IN)
GPS_RXD: U1.20 (TXD/SPI_MISO); also elsewhere on the board
GPS_TIMEPULSE: R24.1, U1.3 (TIMEPULSE)
GPS_TXD: U1.21 (RXD/SPI_MOSI); also elsewhere on the board
I2C_SCL: U1.19 (SCL/SPI_CLK); also elsewhere on the board
I2C_SDA: U1.18 (SDA/~SPI_CS); also elsewhere on the board
unnamed: C26.1, L3.2, R23.2
unnamed: D4.2 (A), R24.2
VBCKP: BT1.1 (+), D2.1 (K), U1.22 (V_BCKP)
VCCREF: R23.1, U1.9 (VCC_RF)
VDDIO: FB1.2, R17.2; also elsewhere on the board

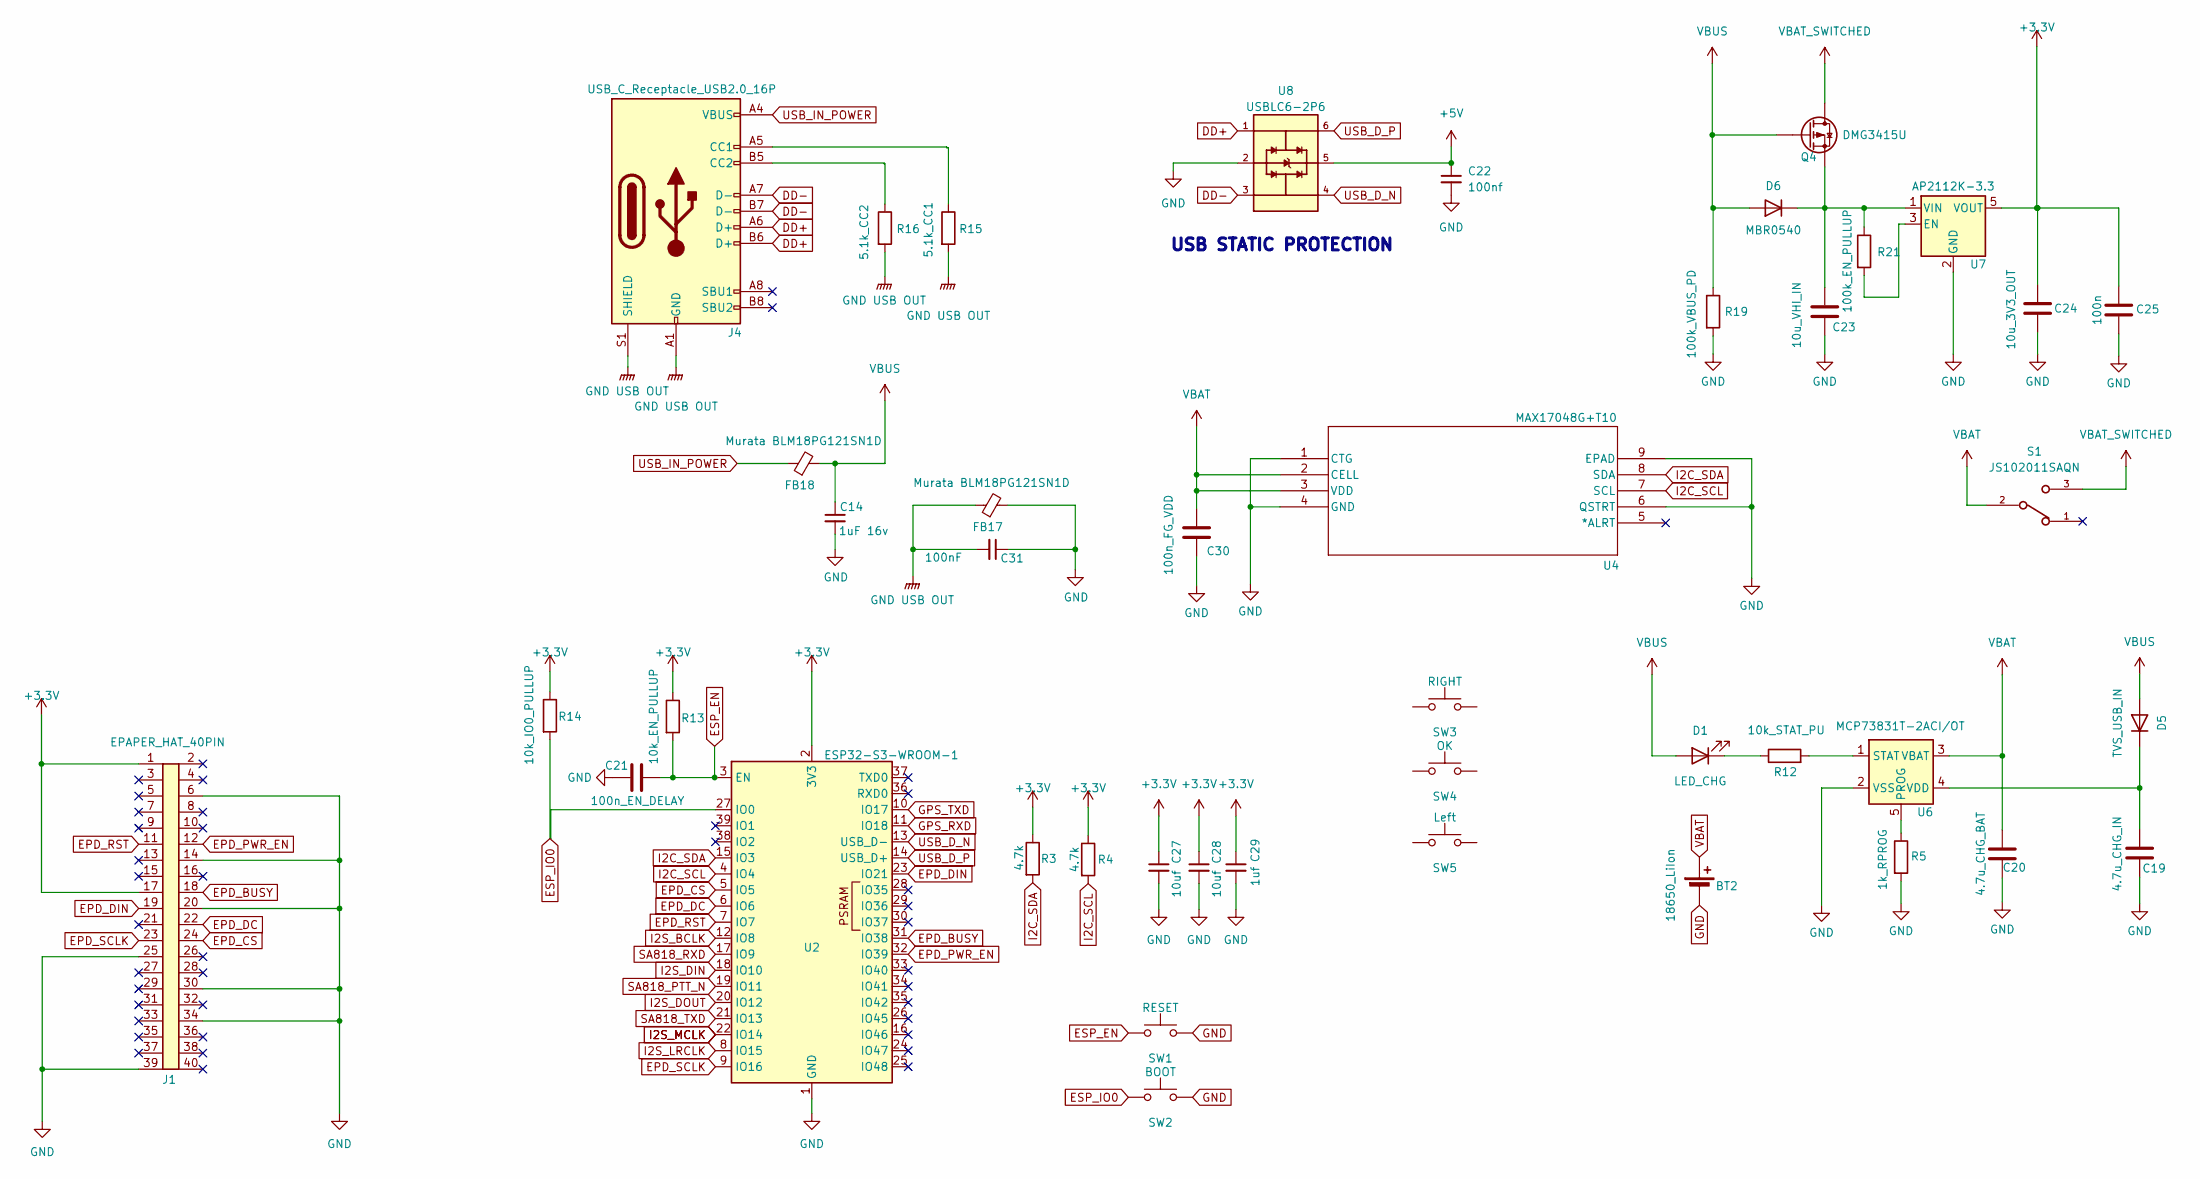
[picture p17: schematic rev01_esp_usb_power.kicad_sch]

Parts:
BT2: 18650_LiIon; BatteryHolder_Keystone_1042_1x18650
C14: 1uF 16v; C_0603_1608Metric; MPN CL05A105KA5NQNC; LCSC C52923
C19: 4.7u_CHG_IN; C_0805_2012Metric
C20: 4.7u_CHG_BAT; C_0805_2012Metric
C21: 100n_EN_DELAY; C_0603_1608Metric
C22: 100nf; C_0603_1608Metric
C23: 10u_VHI_IN; C_0805_2012Metric
C24: 10u_3V3_OUT; C_0805_2012Metric
C25: 100n; C_0603_1608Metric
C27, C28: 10uf; C_0805_2012Metric
C29: 1uf; C_0805_2012Metric
C30: 100n_FG_VDD; C_0603_1608Metric
C31: 100nF; C_0603_1608Metric; MPN CL05B104KO5NNNC; LCSC C1525
D1: LED_CHG; LED_0603_1608Metric
D5: TVS_USB_IN; D_SOD-323
D6: MBR0540; D_SOD-123
FB17, FB18: Murata BLM18PG121SN1D; R_0603_1608Metric; MPN BLM18PG121SN1D
J1: EPAPER_HAT_40PIN; PinSocket_2x20_P2.54mm_Vertical; MPN PPTC202LFBN-RC
J4: USB_C_Receptacle_USB2.0_16P; USB_C_Receptacle_GCT_USB4105-xx-A_16P_TopMnt_Horizontal
Q4: DMG3415U; SOT-23_GSD
R3, R4: 4.7k; R_0603_1608Metric
R5: 1k_RPROG; R_0603_1608Metric
R12: 10k_STAT_PU; R_0603_1608Metric
R13: 10k_EN_PULLUP; R_0603_1608Metric
R14: 10k_IO0_PULLUP; R_0603_1608Metric
R15: 5.1k_CC1; R_0603_1608Metric
R16: 5.1k_CC2; R_0603_1608Metric
R19: 100k_VBUS_PD; R_0603_1608Metric
R21: 100k_EN_PULLUP; R_0603_1608Metric
S1: JS102011SAQN; SW_JS102011SAQN
SW1: RESET; SW_SPST_TL3342
SW2: BOOT; SW_SPST_TL3342
SW3: RIGHT; SW_SPST_TL3342
SW4: OK; SW_SPST_TL3342
SW5: Left; SW_SPST_TL3342
U2: ESP32-S3-WROOM-1
U4: MAX17048G+T10; MAX17048
U6: MCP73831T-2ACI/OT; SOT-23-5
U7: AP2112K-3.3; SOT-23-5
U8: USBLC6-2P6; SOT-666; PARTREV 5

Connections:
+5V: C22.1, U8.5
DD+: J4.A6 (D+), J4.B6 (D+), U8.1
DD-: J4.A7 (D-), J4.B7 (D-), U8.3
EPD_BUSY: J1.18, U2.31 (IO38)
EPD_CS: J1.24, U2.5 (IO5)
EPD_DC: J1.22, U2.6 (IO6)
EPD_DIN: J1.19, U2.23 (IO21)
EPD_PWR_EN: J1.12, U2.32 (IO39)
EPD_RST: J1.11, U2.7 (IO7)
EPD_SCLK: J1.23, U2.9 (IO16)
ESP_EN: C21.2, R13.2, SW1.1, U2.3 (EN)
ESP_IO0: R14.2, SW2.1, U2.27 (IO0)
GND: BT2.2 (-), C14.2, C19.2, C20.2, C21.1, C22.2, C23.2, C24.2, C25.2, C27.2, C28.2, C29.2, C30.2, C31.1, FB17.2, J1.6, J1.14, J1.20, J1.25, J1.30, J1.34, J1.39, R5.2, R19.2, SW1.2, SW2.2, U2.1 (GND), U2.40 (GND), U2.41 (GND), U4.1 (CTG), U4.4 (GND), U4.6 (QSTRT), U4.9 (EPAD), U6.2 (VSS), U7.2 (GND), U8.2; also elsewhere on the board
GND USB OUT: C31.2, FB17.1, J4.A1 (GND), J4.A12 (GND), J4.B1 (GND), J4.B12 (GND), J4.S1 (SHIELD), R15.2, R16.2
GPS_RXD: U2.11 (IO18); also elsewhere on the board
GPS_TXD: U2.10 (IO17); also elsewhere on the board
I2C_SCL: R4.2, U2.4 (IO4), U4.7 (SCL); also elsewhere on the board
I2C_SDA: R3.2, U2.15 (IO3), U4.8 (SDA); also elsewhere on the board
I2S_BCLK: U2.12 (IO8); also elsewhere on the board
I2S_DIN: U2.18 (IO10); also elsewhere on the board
I2S_DOUT: U2.20 (IO12); also elsewhere on the board
I2S_LRCLK: U2.8 (IO15); also elsewhere on the board
I2S_MCLK: U2.22 (IO14); also elsewhere on the board
unnamed: D1.1 (K), R12.1
unnamed: C19.1, D5.1 (K), U6.4 (VDD)
unnamed: C23.1, D6.1 (K), Q4.S, R21.1, U7.1 (VIN)
unnamed: J4.A5 (CC1), R15.1
unnamed: J4.B5 (CC2), R16.1
unnamed: R5.1, U6.5 (PROG)
unnamed: R12.2, U6.1 (STAT)
unnamed: R21.2, U7.3 (EN)
SA818_PTT_N: U2.19 (IO11); also elsewhere on the board
SA818_RXD: U2.17 (IO9); also elsewhere on the board
SA818_TXD: U2.21 (IO13); also elsewhere on the board
USB_D_N: U2.13 (USB_D-), U8.4
USB_D_P: U2.14 (USB_D+), U8.6
USB_IN_POWER: FB18.1, J4.A4 (VBUS), J4.A9 (VBUS), J4.B4 (VBUS), J4.B9 (VBUS)
VBAT: BT2.1 (+), C20.1, C30.1, S1.2, U4.2 (CELL), U4.3 (VDD), U6.3 (VBAT); also elsewhere on the board
VBAT_SWITCHED: Q4.D, S1.3
VBUS: C14.1, D1.2 (A), D5.2 (A), D6.2 (A), FB18.2, Q4.G, R19.1
VDDIO: C24.1, C25.1, C27.1, C28.1, C29.1, J1.1, J1.17, R3.1, R4.1, R13.1, R14.1, U2.2 (3V3), U7.5 (VOUT); also elsewhere on the board

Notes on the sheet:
USB STATIC PROTECTION

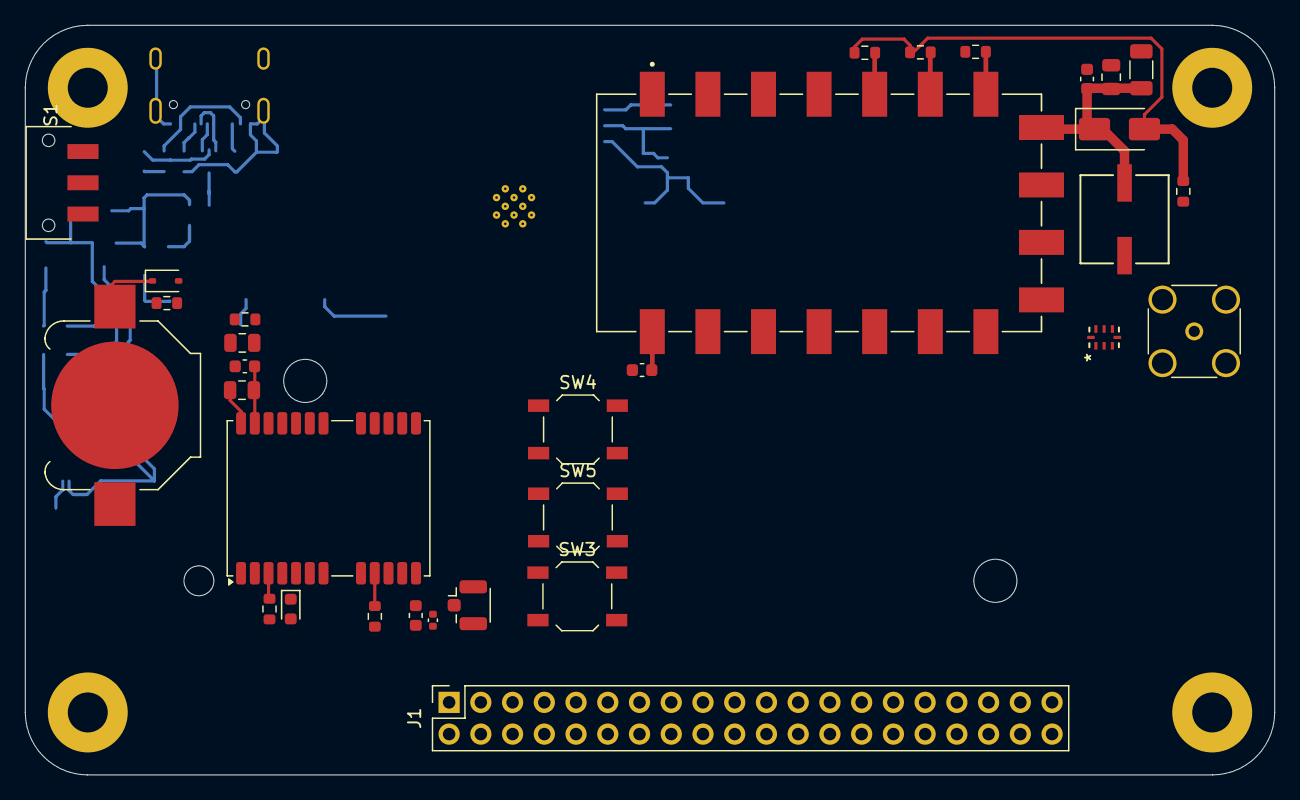
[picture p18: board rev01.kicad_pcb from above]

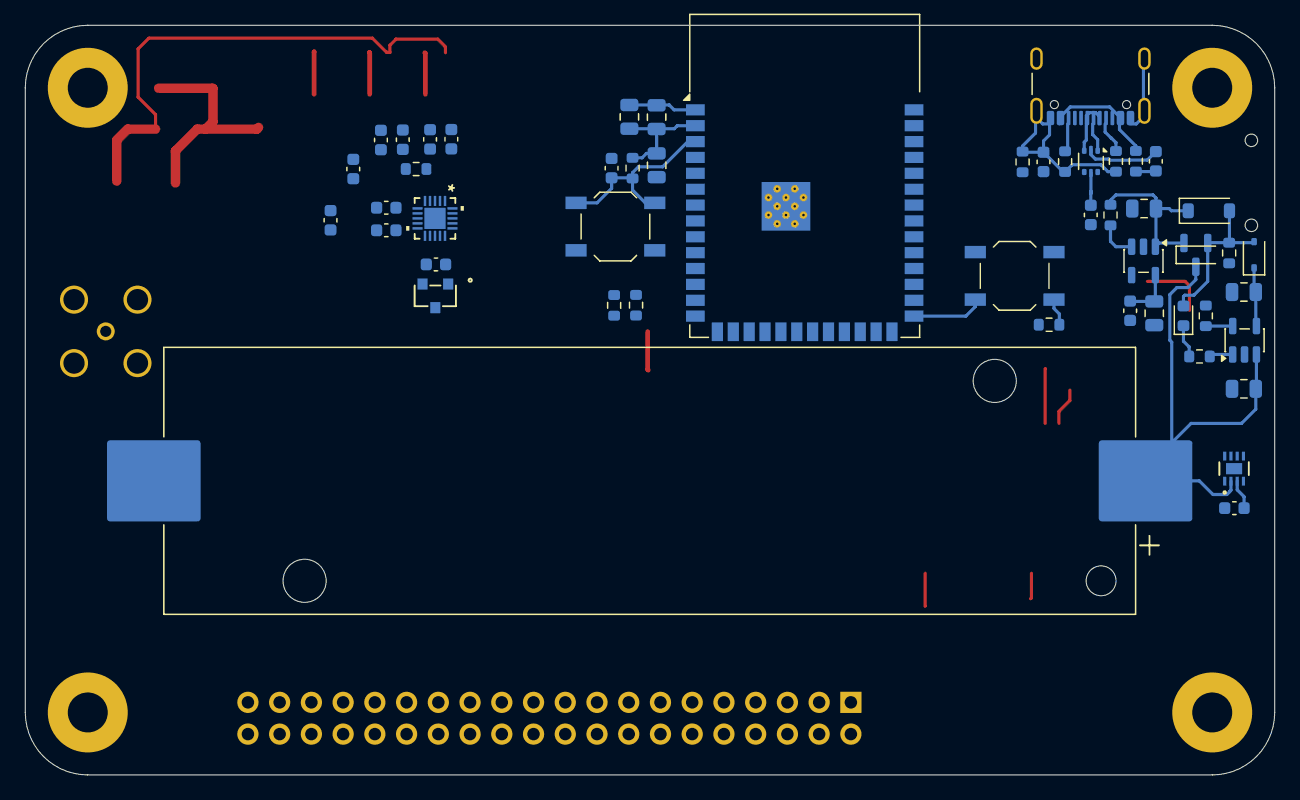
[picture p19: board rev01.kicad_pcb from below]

Board: 2 copper layers, 100.0 x 60.0 mm, 86 parts (50 on the bottom side), 62 nets.

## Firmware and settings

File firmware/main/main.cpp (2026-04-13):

// PAKT Firmware – application entry point
//
// Each subsystem runs as an independent FreeRTOS task.  Tasks are stubs here
// (Step 0); full drivers are added in Steps 1-6.
//
// Priority policy (higher number = higher priority in FreeRTOS):
//   power    2  – background, non-time-critical
//   display  3  – SH1106 OLED UI, 2 Hz refresh, preemptable by all protocol tasks
//   ble      4  – rate-limited by contract; must not starve modem
//   gps      5  – UART stream, moderate latency tolerance
//   aprs     5  – packet state machine
//   radio    7  – UART to SA818, timing-sensitive
//   audio    8  – I2S read/write, real-time critical

#include "freertos/FreeRTOS.h"
#include "freertos/task.h"
#include "freertos/semphr.h"
#include "esp_log.h"
#include "esp_system.h"
#include "esp_task_wdt.h"
#include "esp_timer.h"
#include "nvs_flash.h"

#include "audio_bench_test.h"
#include "bench_profile_config.h"
#include "sa818_bench_test.h"
#include "pakt/BleServer.h"
#include "pakt/DeviceCapabilities.h"
#include "pakt/KissFramer.h"
#include "pakt/NmeaParser.h"
#include "pakt/AprsTaskContext.h"
#include "pakt/PayloadValidator.h"
#include "pakt/DeviceConfigStore.h"
#include "pakt/PttWatchdog.h"
#include "pakt/PttController.h"
#include "pakt/AfskDemodulator.h"
#include "pakt/AfskModulator.h"
#include "pakt/Aprs.h"
#include "pakt/Sa818Radio.h"
#include "pakt/Telemetry.h"
#include "pakt/DisplaySH1106.h"
#include "NvsStorage.h"
#include "Sa818UartTransport.h"
#include "driver/gpio.h"
#include "driver/i2c_master.h"
#include "driver/i2s_std.h"
#include "driver/usb_serial_jtag.h"
#include "driver/uart.h"
#include "esp_adc/adc_oneshot.h"
#include "esp_heap_caps.h"
#include "esp_psram.h"
#include <atomic>
#include <cinttypes>
#include <cstdarg>
#include <cmath>
#include <cstdio>
#include <cstring>

static const char *TAG = "pakt";

// Shared between aprs_task (owner) and ble_task (producer).
// Set by aprs_task before it enters its run loop; ble_task checks for null.
static pakt::AprsTaskContext *g_aprs_ctx = nullptr;

// PTT watchdog (FW-016). Pointer set by aprs_task before its run loop;
// watchdog_task calls tick() every 500 ms. Null until aprs_task is ready.
static pakt::PttWatchdog *g_ptt_watchdog = nullptr;

// ── TX pipeline shared state ──────────────────────────────────────────────────
//
// g_radio      – set by radio_task once Sa818Radio::init() succeeds.
// g_i2s_tx_chan– set by audio_task once the I2S TX channel is enabled.
// Both are read by aprs_task (afsk_tx_frame).  Written once; no mutex needed.
static pakt::Sa818Radio  *g_radio        = nullptr;
static i2s_chan_handle_t  g_i2s_tx_chan  = nullptr;
static i2c_master_bus_handle_t g_shared_i2c_bus = nullptr;

static constexpr uint32_t kAudioSampleRateHz = pakt::benchcfg::kAudioSampleRateHz;
static constexpr bool kVerboseRuntimeLogs =
    pakt::benchcfg::kLogVerbosity == pakt::benchcfg::LogVerbosity::Verbose;

// Rolling 1-second RX peak absolute value, updated by audio_task's demod loop.
// Read by sa818_bench Stage 6 (RX audio capture) via a non-capturing lambda.
// Atomic: audio_task writes, radio_task reads during bench window.
static std::atomic<int32_t>  g_rx_peak_abs{0};

// Cumulative demodulator diagnostics, published by audio_task every ~1 s.
// Read by aprs_task bench (Stage B) to distinguish "no signal" from "FCS failures".
//   g_demod_flags      : total 0x7E flag patterns detected (> 0 means AFSK lock)
//   g_demod_fcs_rejects: frames assembled but CRC failed (> 0 means near-decode)
static std::atomic<uint32_t> g_demod_flags{0};
static std::atomic<uint32_t> g_demod_fcs_rejects{0};
static std::atomic<uint32_t> g_rx_packet_count{0};
static std::atomic<uint32_t> g_tx_packet_count{0};
static std::atomic<uint32_t> g_tx_error_count{0};
static std::atomic<uint32_t> g_rx_error_count{0};
static std::atomic<uint32_t> g_last_rx_frame_ms{0};
static std::atomic<bool>     g_debug_stream_enabled{false};

enum class RuntimeRadioState : uint8_t {
    Idle = 0,
    Rx,
    Tx,
    Error,
};

static std::atomic<RuntimeRadioState> g_runtime_radio_state{RuntimeRadioState::Idle};
static std::atomic<uint32_t> g_radio_rx_freq_hz{144390000U};
static std::atomic<uint32_t> g_radio_tx_freq_hz{144390000U};
static std::atomic<uint8_t>  g_radio_squelch{1};
static std::atomic<uint8_t>  g_radio_volume{4};
static std::atomic<bool>     g_radio_wide_band{true};

static std::atomic<bool>     g_gps_fix_valid{false};
static std::atomic<double>   g_gps_lat_deg{0.0};
static std::atomic<double>   g_gps_lon_deg{0.0};
static std::atomic<float>    g_gps_alt_m{0.0f};
static std::atomic<float>    g_gps_speed_kmh{0.0f};
static std::atomic<float>    g_gps_course_deg{0.0f};
static std::atomic<uint8_t>  g_gps_sats_used{0};
static std::atomic<uint8_t>  g_gps_fix_quality{0};
static std::atomic<uint32_t> g_gps_timestamp_s{0};
static std::atomic<bool>     g_gps_transport_i2c{false};

// Enhanced RX signal diagnostics, published by audio_task every ~1 s.
//   g_rx_mean_abs  : mean |sample| in last 1 s window (0-32767 scale).
//                   Bell 202 at full-scale sine would give ~20900; noise ~200-800.
//   g_rx_clip_count: samples with |x| > 28000 (≈85% FS) in last 1 s window.
//                   > 0 indicates ADC saturation / gain too high.
static std::atomic<uint32_t> g_rx_mean_abs{0};
static std::atomic<uint32_t> g_rx_clip_count{0};

// ADC gain request: 0–15 steps at +1.5 dB/step → 0 to +22.5 dB
// (SGTL5000 CHIP_ANA_ADC_CTRL, both channels).
// Set by aprs_task bench gain sweep; audio_task applies in its per-second tick.
static std::atomic<uint8_t>  g_adc_gain_req{0};

// ── Battery telemetry (written by power_task, read by display_task) ───────────
// Value 255 in g_batt_pct means "not yet measured / unknown".
// These will be populated when power_task gains full MAX17048 support.
static std::atomic<float>   g_batt_voltage_v{0.0f};
static std::atomic<uint8_t> g_batt_pct{255};
static std::atomic<bool>    g_batt_charging{false};
static std::atomic<bool>    g_usb_present{false};

// ── Last received APRS message text (written by aprs_task, read by display_task)
// Protected by g_aprs_rx_text_mutex so both sides see a consistent string.
// aprs_task writes TNC2-formatted string (e.g. "N0CALL>APRS,RELAY*:/pos...")
// on each decoded packet; display_task copies under mutex at ~2 Hz refresh.
static SemaphoreHandle_t g_aprs_rx_text_mutex = nullptr;
static char              g_aprs_rx_text[224]  = ""; // up to 223 chars + NUL

// PCM snapshot: 1024 raw mono int16 samples captured on demand.
// arm : aprs_task sets true; audio_task clears when collection starts.
// valid: audio_task sets true (release) when 1024 samples collected.
// aprs_task reads/logs the buffer then clears valid and arm for the next test.
static constexpr size_t kPcmCapLen =
    static_cast<size_t>(kAudioSampleRateHz * 128u / 1000u);  // 128 ms window
static int16_t           g_pcm_cap[kPcmCapLen];
static std::atomic<bool> g_pcm_cap_arm{false};
static std::atomic<bool> g_pcm_cap_valid{false};

// Full RX debug recorder: 30 s mono PCM at the configured audio sample rate,
// signed 16-bit.
// Backed by PSRAM when available so we can export the exact demod-input samples
// for offline analysis without 8-bit quantization loss.
static constexpr uint32_t kRxRecordSampleRateHz = kAudioSampleRateHz;
static constexpr uint32_t kRxRecordSeconds      = 30;
static constexpr size_t   kRxRecordSamples =
    static_cast<size_t>(kRxRecordSampleRateHz) * kRxRecordSeconds;
static int16_t            *g_rx_record_buf = nullptr;
static std::atomic<bool>   g_rx_record_arm{false};
static std::atomic<bool>   g_rx_record_active{false};
static std::atomic<bool>   g_rx_record_valid{false};
static std::atomic<size_t> g_rx_record_samples{0};

// PCM output buffer for AFSK modulation (global to avoid stack pressure).
// Max AX.25 = 330 B → ~44 800 samples at 16 kHz/1200 baud; keep margin above
// that so debug/sample-rate experiments do not truncate packet TX.
static constexpr size_t kAfskMaxPcmSamples = 60000;
static int16_t           g_tx_pcm_buf[kAfskMaxPcmSamples];

// Device config (callsign, ssid, radio settings).
// NVS backend attached in app_main() after nvs_flash_init().
// Until then (and if NVS init fails) updates are in-memory only.
static pakt::DeviceConfigStore g_device_config;
static pakt::NvsStorage        g_nvs_storage;

// ── Decoded AX.25 RX queue (audio_task → aprs_task) ──────────────────────────
//
// audio_task (producer): pushes raw AX.25 frames decoded by the AFSK modem.
// aprs_task  (consumer): drains the queue each tick; forwards to native BLE
//                        rx_packet notify and KISS RX notify.
//
// Thread model: SPSC — only audio_task writes head_, only aprs_task writes tail_.
// Depth=8 gives ~8 ms burst buffer at 1 packet/ms (typical APRS is << 1/s).
namespace {

struct Ax25RxQueue {
    static constexpr size_t kDepth    = 8;
    static constexpr size_t kMaxFrame = pakt::kKissMaxFrame;

    struct Entry { uint8_t data[kMaxFrame]; size_t len; };

    Entry  slots[kDepth]{};
    std::atomic<uint32_t> head_{0};
    std::atomic<uint32_t> tail_{0};

    // Producer (audio_task context): push a decoded AX.25 frame.
    bool push(const uint8_t *d, size_t l) {
        if (!d || l == 0 || l > kMaxFrame) return false;
        uint32_t h = head_.load(std::memory_order_relaxed);
        if ((h - tail_.load(std::memory_order_acquire)) >= kDepth) return false;
        auto &s = slots[h % kDepth];
        std::memcpy(s.data, d, l);
        s.len = l;
        head_.store(h + 1, std::memory_order_release);
        return true;
    }

    // Consumer (aprs_task context): pop one frame; returns false if empty.
    bool pop(uint8_t *out, size_t *out_len) {
        uint32_t t = tail_.load(std::memory_order_relaxed);
        if (t == head_.load(std::memory_order_acquire)) return false;
        const auto &s = slots[t % kDepth];
        std::memcpy(out, s.data, s.len);
        *out_len = s.len;
        tail_.store(t + 1, std::memory_order_release);
        return true;
    }

    uint8_t size() const {
        const uint32_t h = head_.load(std::memory_order_acquire);
        const uint32_t t = tail_.load(std::memory_order_acquire);
        const uint32_t depth = h - t;
        return static_cast<uint8_t>(depth > kDepth ? kDepth : depth);
    }
};

} // anonymous namespace

static Ax25RxQueue g_rx_ax25_queue;

static bool ensure_rx_record_buffer()
{
    if (g_rx_record_buf) return true;

    const size_t bytes = kRxRecordSamples * sizeof(int16_t);
    const size_t spiram_free = heap_caps_get_free_size(MALLOC_CAP_SPIRAM);
    const size_t spiram_largest = heap_caps_get_largest_free_block(MALLOC_CAP_SPIRAM);
    const size_t internal_free = heap_caps_get_free_size(MALLOC_CAP_INTERNAL | MALLOC_CAP_8BIT);
    const size_t internal_largest =
        heap_caps_get_largest_free_block(MALLOC_CAP_INTERNAL | MALLOC_CAP_8BIT);

    ESP_LOGI("aprs_bench",
             "RX recorder alloc request=%u bytes | PSRAM init=%s size=%u free=%u largest=%u | "
             "internal free=%u largest=%u",
             static_cast<unsigned>(bytes),
             esp_psram_is_initialized() ? "yes" : "no",
             static_cast<unsigned>(esp_psram_get_size()),
             static_cast<unsigned>(spiram_free),
             static_cast<unsigned>(spiram_largest),
             static_cast<unsigned>(internal_free),
             static_cast<unsigned>(internal_largest));

    void *p = heap_caps_malloc(kRxRecordSamples * sizeof(int16_t),
                               MALLOC_CAP_SPIRAM | MALLOC_CAP_8BIT);
    if (!p) {
        p = heap_caps_malloc(kRxRecordSamples * sizeof(int16_t), MALLOC_CAP_8BIT);
    }
    if (!p) {
        ESP_LOGE("aprs_bench", "RX recorder alloc failed (%u bytes)",
                 static_cast<unsigned>(bytes));
        return false;
    }
    g_rx_record_buf = static_cast<int16_t *>(p);
    ESP_LOGI("aprs_bench", "RX recorder buffer ready: %u samples (%u bytes) in %s",
             static_cast<unsigned>(kRxRecordSamples),
             static_cast<unsigned>(bytes),
             esp_ptr_external_ram(g_rx_record_buf) ? "PSRAM" : "internal RAM");
    return true;
}

static void write_le16(uint8_t *p, uint16_t v)
{
    p[0] = static_cast<uint8_t>(v & 0xFFu);
    p[1] = static_cast<uint8_t>((v >> 8) & 0xFFu);
}

static void write_le32(uint8_t *p, uint32_t v)
{
    p[0] = static_cast<uint8_t>(v & 0xFFu);
    p[1] = static_cast<uint8_t>((v >> 8) & 0xFFu);
    p[2] = static_cast<uint8_t>((v >> 16) & 0xFFu);
    p[3] = static_cast<uint8_t>((v >> 24) & 0xFFu);
}

static void make_wav_header(uint8_t header[44], uint32_t sample_rate_hz,
                            uint16_t channels, uint16_t bits_per_sample,
                            uint32_t data_bytes)
{
    std::memcpy(header + 0,  "RIFF", 4);
    write_le32(header + 4, 36u + data_bytes);
    std::memcpy(header + 8,  "WAVE", 4);
    std::memcpy(header + 12, "fmt ", 4);
    write_le32(header + 16, 16u);
    write_le16(header + 20, 1u);
    write_le16(header + 22, channels);
    write_le32(header + 24, sample_rate_hz);
    write_le32(header + 28, sample_rate_hz * channels * (bits_per_sample / 8u));
    write_le16(header + 32, static_cast<uint16_t>(channels * (bits_per_sample / 8u)));
    write_le16(header + 34, bits_per_sample);
    std::memcpy(header + 36, "data", 4);
    write_le32(header + 40, data_bytes);
}
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
extern "C" void app_main(void)
{
    ESP_LOGI(TAG, "PAKT firmware v%s starting (IDF %s)", PAKT_FIRMWARE_VERSION, esp_get_idf_version());
    ESP_LOGI(TAG, "Bench profile: %s", pakt::benchcfg::kProfileName);

    // PTT must be safe-off before any task starts.
    // The radio driver (Step 1) will assert this at init; document the intent here.
    ESP_LOGI(TAG, "PTT default state: OFF");

    // ── NVS init + config load ────────────────────────────────────────────────
    // Must complete before tasks start so callsign/ssid are available immediately.
    {
        esp_err_t ret = nvs_flash_init();
        if (ret == ESP_ERR_NVS_NO_FREE_PAGES || ret == ESP_ERR_NVS_NEW_VERSION_FOUND) {
            ESP_LOGW(TAG, "NVS partition truncated; erasing and reinitialising");
            ESP_ERROR_CHECK(nvs_flash_erase());
            ret = nvs_flash_init();
        }
        if (ret != ESP_OK) {
            ESP_LOGE(TAG, "NVS init failed (%s) – config not persisted this session",
                     esp_err_to_name(ret));
            // g_device_config keeps in-memory-only mode (no set_storage call).
        } else {
            g_device_config.set_storage(&g_nvs_storage);
            if (g_device_config.load()) {
                ESP_LOGI(TAG, "Config loaded from NVS: callsign=%s ssid=%u",
                         g_device_config.config().callsign,
                         static_cast<unsigned>(g_device_config.config().ssid));
            } else {
                ESP_LOGI(TAG, "No prior config in NVS – using defaults");
            }
        }
    }

    // Mutex protecting g_aprs_rx_text; must exist before any task that touches it.
    g_aprs_rx_text_mutex = xSemaphoreCreateMutex();

    if constexpr (pakt::benchcfg::kStartAudioTask) {
        xTaskCreate(audio_task, "audio", 8192, nullptr, 8, nullptr);
    }
    if constexpr (pakt::benchcfg::kStartRadioTask) {
        xTaskCreate(radio_task, "radio", 4096, nullptr, 7, nullptr);
    }
    if constexpr (pakt::benchcfg::kStartWatchdogTask) {
        xTaskCreate(watchdog_task, "watchdog", 4096, nullptr, 6, nullptr);
    }
    if constexpr (pakt::benchcfg::kStartGpsTask) {
        xTaskCreate(gps_task, "gps", 4096, nullptr, 5, nullptr);
    }
    if constexpr (pakt::benchcfg::kStartAprsTask) {
        xTaskCreate(aprs_task, "aprs", 6144, nullptr, 5, nullptr);
    }
    if constexpr (pakt::benchcfg::kStartBleTask) {
        xTaskCreate(ble_task, "ble", 8192, nullptr, 4, nullptr);
    }
    if constexpr (pakt::benchcfg::kStartDisplayTask) {
        // Priority 3: lower than BLE (4) so it never competes with protocol tasks;
        // higher than power (2) so background battery sampling can't starve the display.
        // Stack: 3 KB covers snprintf formatting + SH1106 flush path.
        xTaskCreate(display_task, "display", 3072, nullptr, 3, nullptr);
    }
    if constexpr (pakt::benchcfg::kStartPowerTask) {
        // Stack: 4 KB leaves headroom for ADC setup, I2C reads, and logging.
        xTaskCreate(power_task, "power", 4096, nullptr, 2, nullptr);
    }

    ESP_LOGI(TAG, "Selected tasks created");
}

// ── Task stubs ────────────────────────────────────────────────────────────────
// Each stub will be replaced in subsequent implementation steps.
// The tag prefix matches the task name so logs are easy to filter.

static void radio_task(void *arg)
{
    // FW-003: SA818-V radio driver (UART1, PTT GPIO11 active-low)
    //
    // GPIO11 – PTT, active low: LOW = TX asserted, HIGH = TX off.
    // Register a direct GPIO lambda as the watchdog safe-off callback BEFORE
    // init() so the watchdog can de-assert PTT even if init() fails or hangs.
    // This direct path bypasses Sa818Radio state and avoids any race between
    // watchdog_task and radio_task.

    // static constexpr gives these variables static storage duration, so they are
    // accessible from the non-capturing lambdas below without explicit capture
    // (C++17 §6.7.1 / §7.5.5.2).  GCC 12 (Xtensa ESP-IDF toolchain) handles
    // this correctly; no -Wcapture-this-in-constexpr-context warning expected.
    static constexpr gpio_num_t kPttGpio    = static_cast<gpio_num_t>(11);
    static constexpr uart_port_t kUartPort  = UART_NUM_1;
    static constexpr int         kUartTxPin = 13;   // SA818_RX_CTRL (ESP TX → SA818 RXD)
    static constexpr int         kUartRxPin = 9;    // SA818_TX_STAT (SA818 TXD → ESP RX)
    static constexpr int         kBaud      = 9600;
    static constexpr uint32_t    kSa818BootSettleMs = 2000;

    // Configure PTT GPIO: output, default HIGH (PTT off).
    gpio_config_t ptt_cfg = {};
    ptt_cfg.pin_bit_mask = (1ULL << kPttGpio);
    ptt_cfg.mode         = GPIO_MODE_OUTPUT;
    ptt_cfg.pull_up_en   = GPIO_PULLUP_DISABLE;
    ptt_cfg.pull_down_en = GPIO_PULLDOWN_DISABLE;
    ptt_cfg.intr_type    = GPIO_INTR_DISABLE;
    gpio_config(&ptt_cfg);
    gpio_set_level(kPttGpio, 1);   // PTT off

    // Register watchdog safe-off callback: direct GPIO, bypasses driver state.
    pakt::ptt_register_safe_off([](){ gpio_set_level(kPttGpio, 1); });
    ESP_LOGI("radio", "PTT GPIO%d configured (HIGH=off); watchdog safe-off registered",
             static_cast<int>(kPttGpio));

    // Configure UART1 at 9600 8N1 for SA818 AT commands.
    const uart_config_t uart_cfg = {
        .baud_rate  = kBaud,
        .data_bits  = UART_DATA_8_BITS,
        .parity     = UART_PARITY_DISABLE,
        .stop_bits  = UART_STOP_BITS_1,
        .flow_ctrl  = UART_HW_FLOWCTRL_DISABLE,
        .source_clk = UART_SCLK_DEFAULT,
    };
    esp_err_t err = uart_driver_install(kUartPort, 256, 0, 0, nullptr, 0);
    if (err != ESP_OK) {
        ESP_LOGE("radio", "uart_driver_install(UART_NUM_%d) failed: %s",
                 static_cast<int>(kUartPort), esp_err_to_name(err));
        for (;;) { vTaskDelay(pdMS_TO_TICKS(5000)); }
    }
    err = uart_param_config(kUartPort, &uart_cfg);
    if (err != ESP_OK) {
        ESP_LOGE("radio", "uart_param_config(UART_NUM_%d) failed: %s",
                 static_cast<int>(kUartPort), esp_err_to_name(err));
        for (;;) { vTaskDelay(pdMS_TO_TICKS(5000)); }
    }
    err = uart_set_pin(kUartPort, kUartTxPin, kUartRxPin,
                       UART_PIN_NO_CHANGE, UART_PIN_NO_CHANGE);
    if (err != ESP_OK) {
        ESP_LOGE("radio", "uart_set_pin(UART_NUM_%d, tx=%d, rx=%d) failed: %s",
                 static_cast<int>(kUartPort), kUartTxPin, kUartRxPin,
                 esp_err_to_name(err));
        for (;;) { vTaskDelay(pdMS_TO_TICKS(5000)); }
    }
    uart_flush_input(kUartPort);
    ESP_LOGI("radio",
             "UART%d configured: tx=GPIO%d rx=GPIO%d baud=%d; waiting %u ms for SA818 boot",
             static_cast<int>(kUartPort), kUartTxPin, kUartRxPin, kBaud,
             static_cast<unsigned>(kSa818BootSettleMs));
    vTaskDelay(pdMS_TO_TICKS(kSa818BootSettleMs));

    // Construct concrete transport and radio driver.
    static pakt::Sa818UartTransport transport(kUartPort);
    static pakt::Sa818Radio radio(
        transport,
        [](bool on){ gpio_set_level(kPttGpio, on ? 0 : 1); }
    );

    // Run staged SA818 bench test before normal init.
    // Stage 5 (TX audio) waits for g_i2s_tx_chan (published by audio_task after audio_bench).
    // Stage 6 (RX capture) runs after Stage 5; by then the demod loop is live and
    // rx_peak_fn returns the rolling 1-s peak_abs from g_rx_peak_abs.
    if constexpr (pakt::benchcfg::kEnableSa818Bench) {
        pakt::bench::run_sa818_bench(
            transport, kPttGpio, kUartPort,
            static_cast<const volatile void *>(&g_i2s_tx_chan),
            kAudioSampleRateHz,
            /*tx_wait_ms=*/120000,
            /*rx_peak_fn=*/[]() -> int32_t {
                return g_rx_peak_abs.load(std::memory_order_relaxed);
            });
    } else {
        ESP_LOGI("radio", "SA818 bench disabled by bench_profile_config.h");
    }

    if (!radio.init()) {
        ESP_LOGE("radio", "SA818 init failed – radio unavailable; PTT remains off");
        g_runtime_radio_state.store(RuntimeRadioState::Error, std::memory_order_relaxed);
        // Watchdog safe-off callback stays as direct GPIO lambda (safe).
        for (;;) { vTaskDelay(pdMS_TO_TICKS(5000)); }
    }

    ESP_LOGI("radio", "SA818 init OK");
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

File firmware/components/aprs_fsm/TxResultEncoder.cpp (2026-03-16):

// TxResultEncoder.cpp – TX result JSON encoder for BLE notify (P0)

#include "pakt/TxResultEncoder.h"

#include <cstdio>

namespace pakt {

size_t TxResultEncoder::encode(const char *msg_id, TxResultEvent event,
                                char *buf, size_t buf_len)
{
    if (!buf || buf_len == 0 || !msg_id) return 0;
    int n = snprintf(buf, buf_len,
                     "{\"msg_id\":\"%s\",\"status\":\"%s\"}",
                     msg_id, event_to_str(event));
    if (n < 0) return 0;
    return (static_cast<size_t>(n) < buf_len) ? static_cast<size_t>(n) : buf_len - 1;
}

TxResultEvent TxResultEncoder::state_to_event(TxMsgState state)
{
    switch (state) {
        case TxMsgState::ACKED:     return TxResultEvent::ACKED;
        case TxMsgState::TIMED_OUT: return TxResultEvent::TIMEOUT;
        case TxMsgState::CANCELLED: return TxResultEvent::CANCELLED;
        default:                    return TxResultEvent::ERROR;
    }
}

const char *TxResultEncoder::event_to_str(TxResultEvent event)
{
    switch (event) {
        case TxResultEvent::TX:        return "tx";
        case TxResultEvent::ACKED:     return "acked";
        case TxResultEvent::TIMEOUT:   return "timeout";
        case TxResultEvent::CANCELLED: return "cancelled";
        case TxResultEvent::ERROR:     return "error";
    }
    return "error";
}

} // namespace pakt

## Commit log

2026-02-28 added components datasheet
    [placeholder_bom.csv, sources_manifest.csv]
2026-03-09 mvp prep
    [DFN-8-1EP_3x2mm_P0.5mm_EP1.75x1.45mm.step, ESP32-S3-WROOM-1.step, NEO-M9N-00B.step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]
2026-03-20 prototype updates
2026-03-28 Fix APRS RX half-rate capture bug; add dual bench profiles; proven on-device decode
    - Fix: IDF 5.5.x i2s_channel_read batches two 1024-byte DMA descriptors and
    returns 2048 bytes regardless of requested size. The old loop limit
    (frames < kDmaFrames=256) discarded the second 256 frames every read,
    running the demodulator at 8 kHz instead of 16 kHz. Fixed by introducing
    kMaxMonoFrames=512 and raising the unpack loop limit to drain all bytes IDF
    returns; samp/s is now ~16000 as expected.
    - Fix: Stage C SA818 volume wired through profile constant kAprsStageCVolume.
    Both profiles now set volume=4 (was 8 in current profile, causing peak=32768
    ADC clipping that corrupted the Bell 202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
    [main.cpp]
2026-03-28 Wire APRS ack detection, GPS UART driver, and main firmware production mode
    - Fix: aprs_task RX drain loop was never calling ctx.notify_ack(); received APRS
    acks were forwarded to BLE clients as rx_packet but never fed back into
    TxScheduler. Messages always timed out regardless of on-air ack. Fixed by
    parsing the decoded AX.25 info field for ':ADDRESSEE:ack<msg_id>' format,
    matching addressee to the device callsign, and calling ctx.notify_ack(msg_id)
    to close the send/ack/timeout FSM path.
    - Fix: GPS UART was a stub (placeholder comment only). gps_task now initialises
    UART2 on GPIO17 (TX→M9N RXD) / GPIO18 (M9N TXD→ESP RX) at 38400 baud (NEO-M9N
    factory default). Bytes are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
    [main.cpp]
2026-04-10 pcb rev01 schematic and nets
    [_test_122549.kicad_sch, rev01.kicad_pcb, rev01.kicad_sch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]
2026-04-12 PCB rev01 progress
    [rev01.kicad_sch, rev01_esp_usb_power.kicad_sch, rev01_gps.kicad_sch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]
2026-04-12 pcb progress
    [DFN-8-1EP_3x2mm_P0.5mm_EP1.75x1.45mm.step, HUQFN20_SOT1628-1_NXP.step, MAX17048.step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]
2026-04-13 Add SH1106 display smoke test and battery telemetry
2026-05-09 progress on pcb
    [JS102011SAQN.step, PTS647SN50SMTR2LFS.stp, rev01.kicad_pcb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]
2026-05-09 added e-paper display
    [rev01.kicad_pcb, rev01_bom_grouped.csv, rev01_bom_preferred.csv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]

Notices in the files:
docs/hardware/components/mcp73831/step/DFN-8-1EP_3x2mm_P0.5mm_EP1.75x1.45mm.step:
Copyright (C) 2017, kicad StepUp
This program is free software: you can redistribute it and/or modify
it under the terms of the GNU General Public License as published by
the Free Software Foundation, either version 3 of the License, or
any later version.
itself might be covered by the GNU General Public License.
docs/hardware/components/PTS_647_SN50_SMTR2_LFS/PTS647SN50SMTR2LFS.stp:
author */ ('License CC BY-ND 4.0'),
